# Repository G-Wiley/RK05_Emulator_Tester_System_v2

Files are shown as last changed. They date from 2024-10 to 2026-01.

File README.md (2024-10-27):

# RK05 Emulator/Tester System v2
The RK05 Emulator/Tester System v2

Finished Emulator

<p>The RK05 Emulator/Tester v2 system consists of a main unit, various cables, a terminator, and a power supply. The primary improvement of v2 is that is can emulate and test drives with up to 32 sectors. The DEC RK05 has a maximum capability of 16 sectors but other drives such as some members of the Diablo series 30 family can support up to 32 sectors.

<p>The RK05 Emulator/Tester main unit can be configured to function either as an RK05 disk drive emulator or as an RK05 disk drive tester. The specific function is determined by the software in the Raspberry Pi Pico and the FPGA firmware. Currently, the RK05 disk emulator functions have been rigorously tested. The RK05 disk drive tester functions have been used to test the emulator but full tester functionality is not yet complete.

<p>The Emulator/Tester main unit is designed so it can be connected using the same cables and terminators used with a real RK05 disk drive.

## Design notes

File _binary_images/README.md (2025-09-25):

as of 21-Sep-2025, the latest code is:<br>
<p><b>Emulator:</b><br>
RPi Pico software: RK05_Emulator_RPi_Pico_v2-7.uf2<br>
FPGA firmware: RK05_emulator_FPGA_v2-8.bin</p>
<p><b>Tester:</b><br>
RPi Pico software: RK05_Tester_RPi_Pico_v1-19.uf2<br>
FPGA firmware: RK05_tester_FPGA_v2-5.bin</p>

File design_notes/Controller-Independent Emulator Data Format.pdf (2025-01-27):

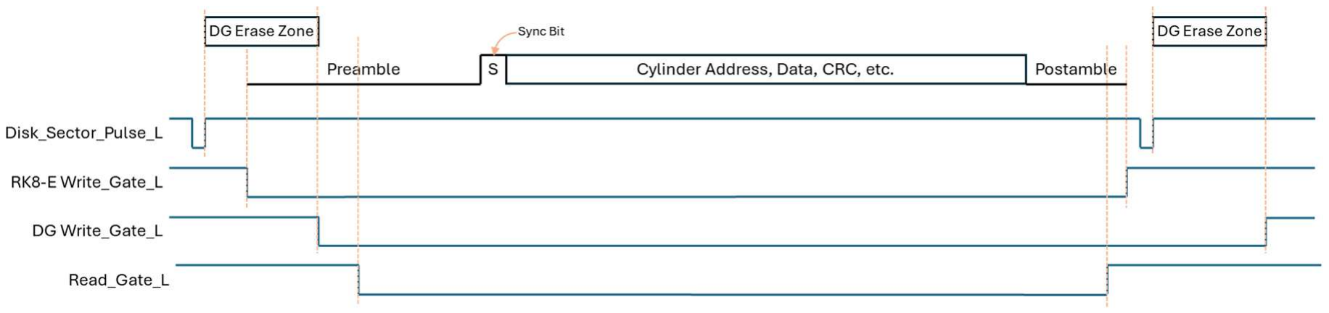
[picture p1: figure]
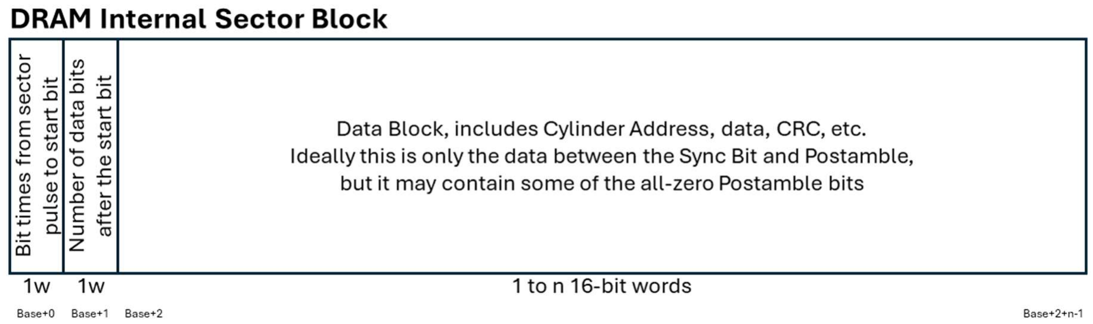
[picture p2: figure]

26-Jan-2025 | Controller-Independent Emulator Data Format v06.docx | page 1

Controller-independent drive emulator data format

Challenges for the previous emulator architecture:
- Having the drive use controller-specific fields made it diicult to accommodate dierent controllers. It was necessary to know details of the timing of the disk bus signals for dierent controllers.
- The timing of some control signals, such as the Write Gate signal on Data General controllers, extend past the sector being written or read which was a complication for the emulator but solvable.
All disk formats in this family of drives and controllers have an all-zero preamble, a single one bit for the sync bit, some number of data bits stored in each sector which includes various fields in addition to data, and an all-zero postamble. Data General controllers keep the Write Gate signal asserted past the sector mark of the next sector.

The controller-independent format has the following data structure for each sector in DRAM and also each sector on the microSD card.

By referencing time from the sector pulse, the emulator will always output the start bit and data block at the correct time. It’s just like bits on the surface of the disk platter.
The fields are as follows:
- Bit times from sector pulse to start bit – address Base+0, the number of bit times from the leading edge of the sector pulse to the start bit that follows the preamble. Since the preamble is an all-zero field, the emulator needs only to count the number of zero bits prior to the start bit and record the count in this field.
- Number of data bits after the start bit – address Base+1, a 16-bit count of the number of bits in the following Data Block. The emulator knows that any bits following the Data Block are all-zero which is either all of the postamble of the last bits of the postamble.

26-Jan-2025 | Controller-Independent Emulator Data Format v06.docx | page 2
- Data block – from addresses Base+2 up to Base+2+n-1, a block of 1 to n words which is the data for a sector on the disk which includes the Cylinder Address, sector data, and CRC. This field could also contain some of the postamble bits when sectors are written by the computer’s disk controller. This is the same data that is presently stored in the DRAM and on the microSD card disk image file.
It is helpful to describe the events that occur during disk read and write operations to be able to implement these functions in FPGA logic.

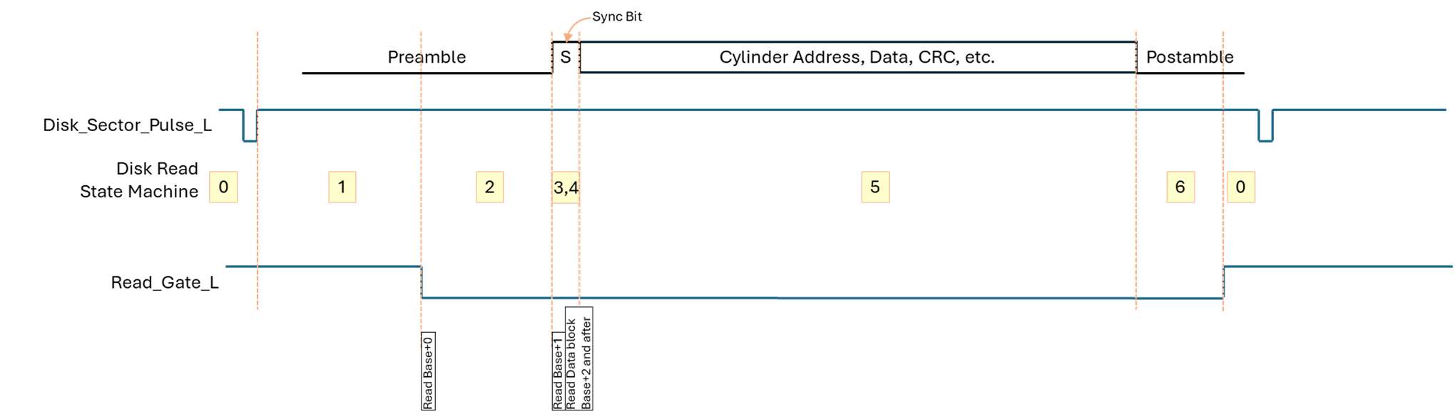
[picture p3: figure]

26-Jan-2025 | Controller-Independent Emulator Data Format v06.docx | page 3

Disk Read Operation:

The following sequence of events occurs when the disk controller reads a sector from the disk:
1. The Emulator generates a periodic sector pulse.
2. At the leading edge of the sector pulse, the Emulator internally loads the fieldbitcount counter to 1, which tracks the number of bit times since the sector pulse. The Emulator begins to increment the fieldbitcount counter once per bit time.
3. If the controller asserts the Read Gate signal, then the Emulator reads the first word of the
DRAM Internal Sector Block from DRAM at address Base+0 which is the value: “Bit times from sector pulse to start bit” and saves it in cthreshold. The fieldbitcount counter continues to increment once per bit time. If there is no read operation (Read Gate doesn’t go active after the sector pulse) and the next sector pulse arrives without having Read Gate asserted, then the fieldbitcount counter is loaded with 1 again at the leading edge of the sector pulse. This happens often.
4. The Emulator detects when the fieldbitcount counter is equal to cthreshold (which was read from Base+0 in step #3) and outputs the Start Bit at the proper clock/data phase time on the serial read data signal, BUS_RD_DATA_L.
5. The Emulator reads the second word of the DRAM Internal Sector Block from DRAM at address Base+1 which is “Number of data bits after the start bit” and saves it in cthreshold. This is to know when to stop the process of reading from DRAM and outputting serial data to the Disk Bus. The fieldbitcount counter is reset to 1 because it now keeps track of how many bits are transferred following the Sync Bit.
6. The Emulator now outputs serialized data read from the Data Block in the DRAM starting at address Base+2. The fieldbitcount counter is incremented once per bit time. If the fieldbitcount counter is equal to cthreshold (which was read from Base + 1 in step #5) then the emulator advances to step #7. If Read Gate goes inactive before all bits of the Data Block have been read from DRAM and serialized, then reset the data read state machine to its starting state.
7. While Read Gate is still in the active state, the Emulator outputs all-zero data to the Disk Bus until Read Gate goes inactive.
8. When Read Gate goes inactive, then reset the data read state machine to its starting state.

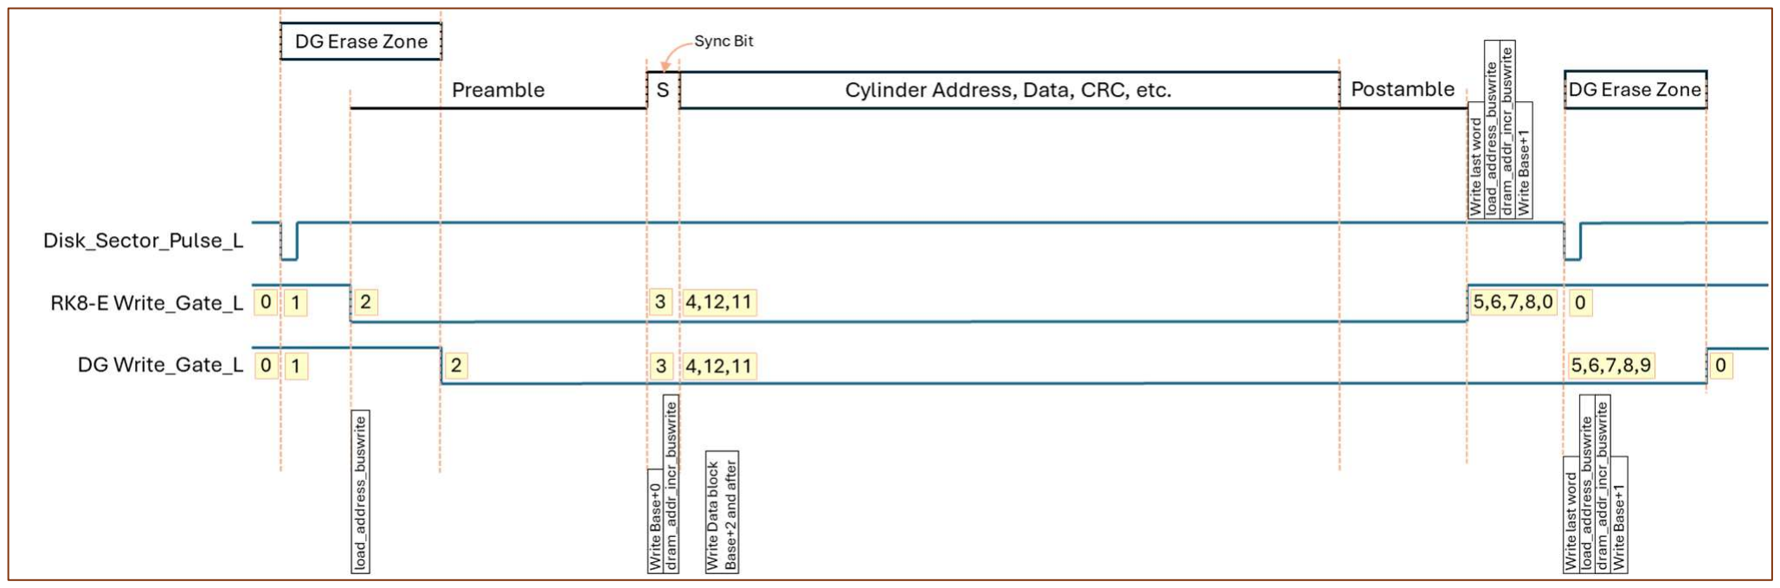
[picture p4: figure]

26-Jan-2025 | Controller-Independent Emulator Data Format v06.docx | page 4

Disk Write Operation:

The following sequence of events occurs when the disk controller writes a sector to the disk:
1. The Emulator generates a periodic sector pulse.
2. At the leading edge of the sector pulse, the Emulator internally loads the fieldbitcount counter to 1, which tracks the number of bit times since the sector pulse. The Emulator begins to increment the fieldbitcount counter once per bit time. Prior to receiving the composite write data-clock signal from the controller, the emulator uses the internal bit time reference signal, clkenbl_read_bit, as a bit time reference.
3. The controller asserts the Write Gate signal.
4. The Emulator decodes serial data on BUS_WT_DATA_CLK_L to recover clock and data.
5. The emulator continues to increment the fieldbitcount counter but now uses the bit enable signal from the decoded BUS_WT_DATA_CLK_L signal as a bit-time reference.
6. When the Sync Bit is detected on the decoded BUS_WT_DATA_CLK_L, the Emulator writes the value in the fieldbitcount counter (which is the bit count since the leading edge of the index pulse) into the first word of the DRAM Internal Sector Block at Base+0. The Emulator sets the fieldbitcount counter to 1 which will now be used to count the number of bits that follow the Sync Bit.

### 7. Emulator decodes serial data on BUS_WT_DATA_CLK_L and writes data words to the DRAM

Internal Sector Block area called Data Block which begins at Base+2.
8. When the Controller de-asserts Write Gate, the Emulator writes the last word or partial word of decoded data to the Data Block and then writes the value in the fieldbitcount counter to the second word of DRAM Internal Sector Block at Base+1 and the internal state machine returns to its starting state. If the Emulator asserts the periodic sector pulse prior to the inactive edge of Write Gate, then the Emulator interprets this event as the end of the sector data and the Emulator writes the last word or partial word of decoded data to the Data Block and then writes the field_bit_count counter to the second word of DRAM Internal Sector Block at Base+1 and the internal state machine goes to a state where no more data is written to DRAM and it waits for Write Gate to go inactive. In the event where Write Gate goes inactive following the assertion of the sector pulse, the internal state machine returns to its starting state when Write Gate goes inactive.

26-Jan-2025 | Controller-Independent Emulator Data Format v06.docx | page 5

The file size on microSD is only two words per sector larger than the previous rk05 file format size, so the load and unload times are about the same.
Essential fields needed in the microSD file header to support the functions described above are:
- Number of Cylinders
- Number of Sectors per Track
- Number of Heads
- Microseconds per sector
- Bit rate
The Bit Rate field is the only controller-specific information needed by the Emulator.
Need a format-specific converter utility for each disk controller type to convert from SIMH to the emulator file format. Maybe this is only needed for PDP-8 and PDP-11. For less-commonly-used formats it is probably suicient to have a utility to create an empty (all-zero data) file with header parameters in the list above, and the lengths of data blocks need to only be approximate given the data rate and number of sectors per track. The emulator disks can be formatted on each machine or users can develop their own SIMH converter for other formats using the source code for the PDP-8 utilities.

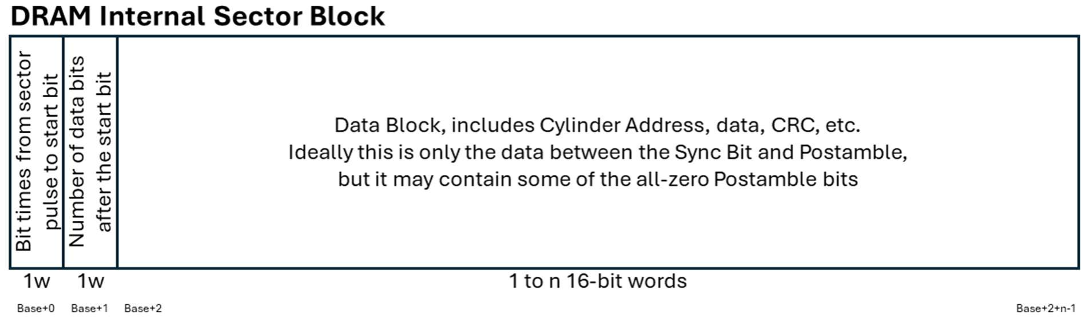
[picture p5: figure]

26-Jan-2025 | Controller-Independent Emulator Data Format v06.docx | page 6

rke File Format Description:

The file on the microSD card has a file extension of “rke”. The emulator RUN/LOAD switch is toggled to the RUN position, the emulator searches for the first rke file that it finds and loads that file into the emulator’s DRAM. The rke file consists of a group of header fields followed by a group of sector data blocks. The sector data blocks can vary in size slightly. This is determined by the original lengths of each block when the microSD file was created and the width of the write gate pulse produced by the disk controller that may have written new data to the disk while it was loaded in the drive.
The file consists of Header + Data Blocks. For 16-sector PDP-8 there are 203 * 16 * 2 = 6496 blocks. For 12-sector PDP-11 there are 203 * 12 * 2 = 4872 blocks.
The rke file header consists of the following fields:
# bytes | Field Description | Hex Oset

10 | char magicNumber[10] = "\x89RK05\r\n\x1A"; | 0x0
4 | char versionNumber[4] = "1.1"; | 0xa
11 | char imageName[11]; | 0xe
200 | char imageDescription[200]; | 0x19
20 | char imageDate[20]; | 0xe1
100 | char controller[100]; | 0xf5
4 | int bitRate; (big endian format) | 0x159
4 | int numberOfCylinders; (big endian format) | 0x15d
4 | int numberOfSectorsPerTrack; (big endian format) | 0x161
4 | int numberOfHeads; (big endian format) | 0x165
4 | int microsecondsPerSector; (big endian format) | 0x169

Following the header there is a group of Sector Blocks beginning at oset 36510 (0x16d). The number of Sector Blocks is:

numberOfCylinders × numberOfSectorsPerTrack × numberOfHeads
The format of each Sector Block is as follows:
- uint16 bit_times_sector_to_start_bit; (little endian format)
- uint16 data_bits_after_start_bit; (little endian format)
- uint16 data_in_sector[data_word_count]

26-Jan-2025 | Controller-Independent Emulator Data Format v06.docx | page 7

The length of the Data Block in 16-bit words, data_word_count, can vary by a small amount in each sector because it is determined by the emulator measuring the length of the write gate pulse from the controller. A file might be initially created by converting a simH file to an rke file, in which case all Sector Blocks will be the same length. Then if that rke file is loaded into the emulator and some sectors are written by the disk controller, the sectors written by the disk controller can have a slightly dierent length than the sectors created by the simH conversion software. The number of 16-bit words in the Data Block is based on the data_bits_after_start_bit field value.
If (data_bits_after_start_bit % 16) == 0 then the Data Block length is (data_bits_after_start_bit / 16). If (data_bits_after_start_bit % 16) != 0 then the Data Block length is (data_bits_after_start_bit / 16) + 1.

## Example of rke file contents

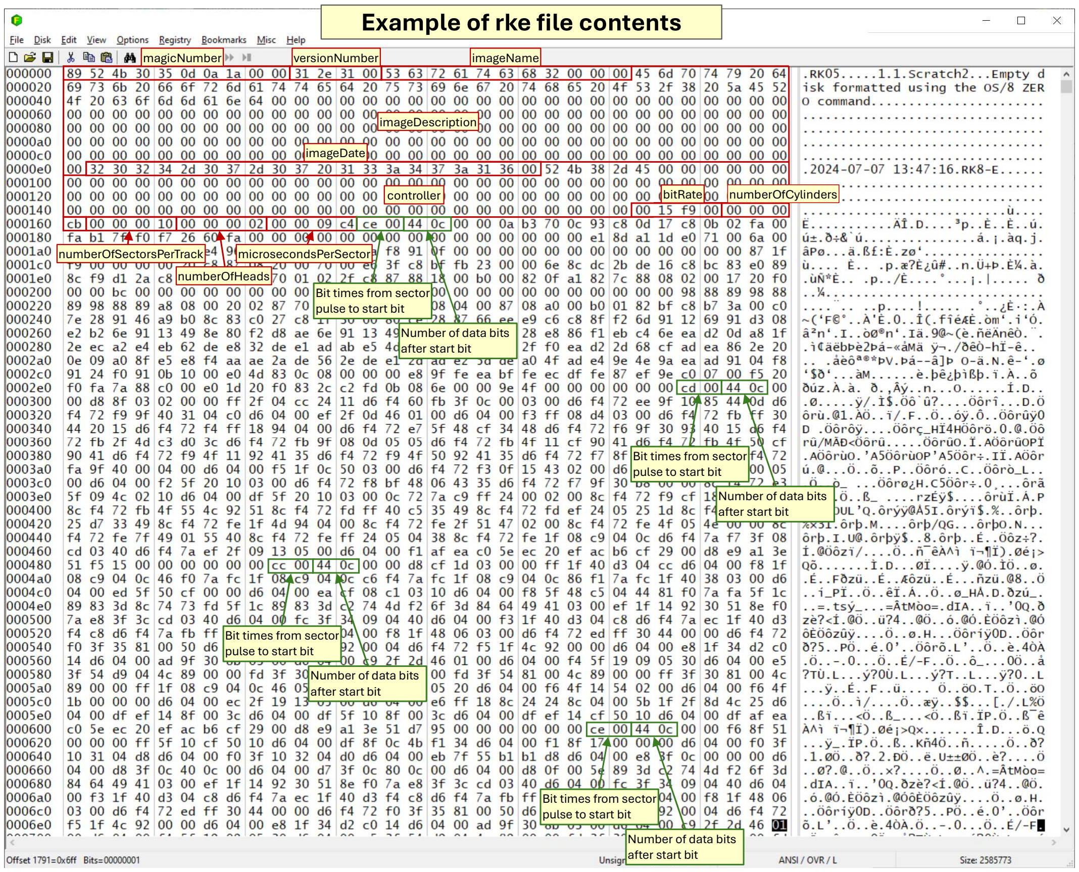
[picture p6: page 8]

26-Jan-2025 | Controller-Independent Emulator Data Format v06.docx | page 8
magicNumber | versionNumber | imageName

imageDescription

imageDate

controller | bitRate | numberOfCylinders

numberOfSectorsPerTrack
numberOfHeads

microsecondsPerSector

Bit times from sector
pulse to start bit
Number of data bits
after start bit

Bit times from sector
pulse to start bit
Number of data bits
after start bit

Bit times from sector
pulse to start bit
Number of data bits
after start bit

Bit times from sector
pulse to start bit
Number of data bits
after start bit

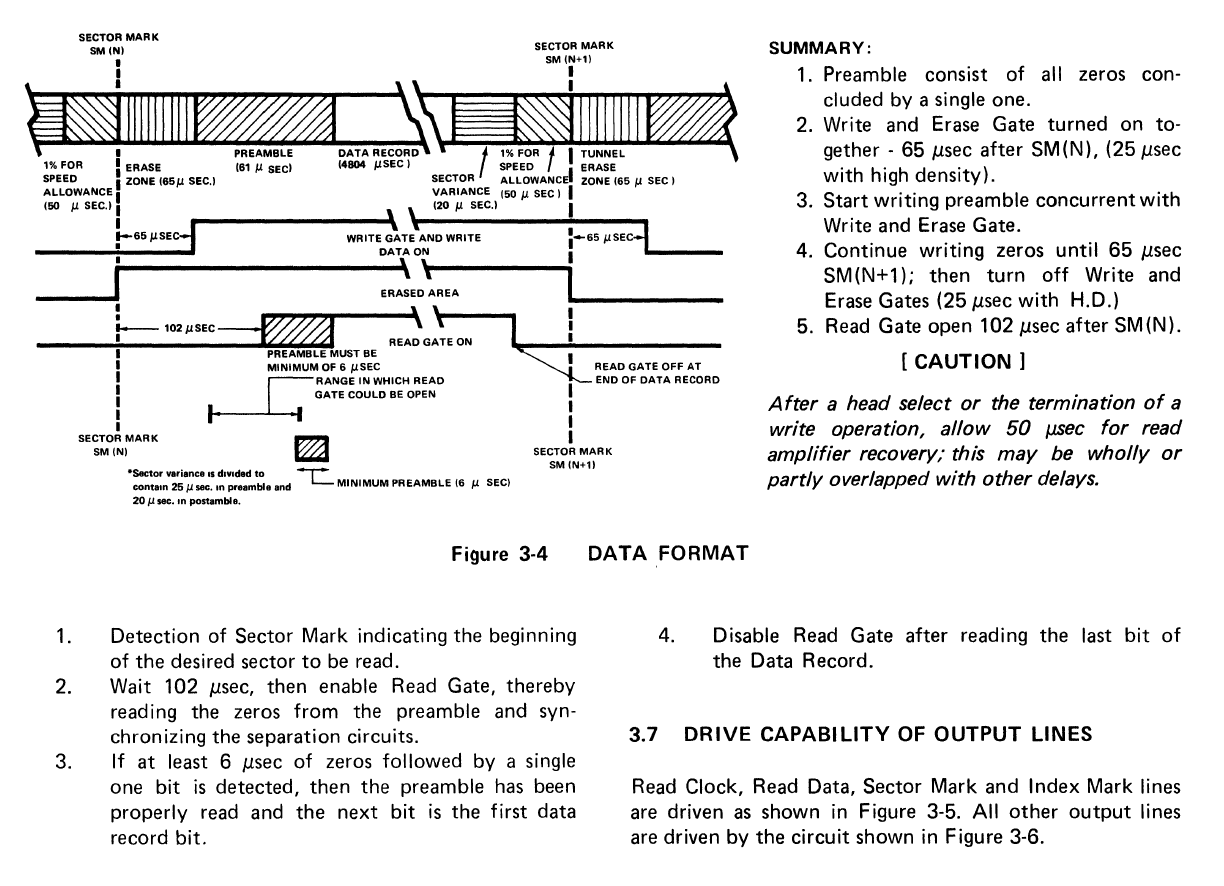
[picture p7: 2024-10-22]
design_notes/Data General diablosync.png

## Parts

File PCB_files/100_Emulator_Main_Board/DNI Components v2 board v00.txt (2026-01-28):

RK05 Emulator v1, parts not added to BOM
Schematic Page 1
J1
J28
J29
R5
R9

Schematic Page 2
JA7
JB7

Schematic Page 3
C7
J3
H1
H2
H3
H4
H5

Schematic Page 4
C35
FPC1
J2
J4
J5
J6
J7
J8
J9
J10
J11
J12
J13
J14
J15
J17
J18
J19
J20
J21
J24
J25
J27
R13
R22
R25
U21
U22

Schematic Page 5
JA8
JB8

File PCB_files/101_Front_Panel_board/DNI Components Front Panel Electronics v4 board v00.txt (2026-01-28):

RK05 Emulator Front Panel Electronics v3, parts not added to BOM
Schematic Page 1
J1
J2
J3
J4
J5
J6
J7 (3-pin header, servo)
J9
J10
J11
J12
J13
J14
J15
J16
J17 (16-pin header, main board)
H1 to H15
R6
R18
SW2
U3 (display module)

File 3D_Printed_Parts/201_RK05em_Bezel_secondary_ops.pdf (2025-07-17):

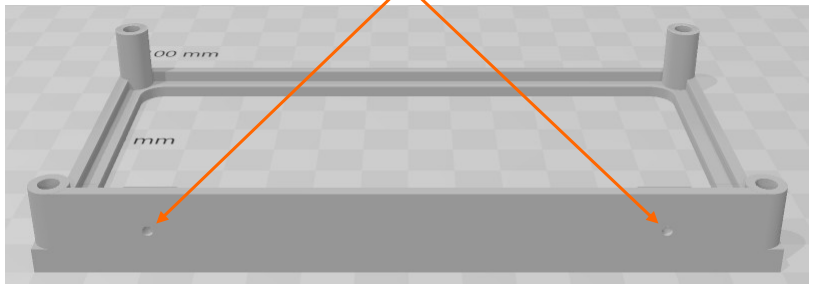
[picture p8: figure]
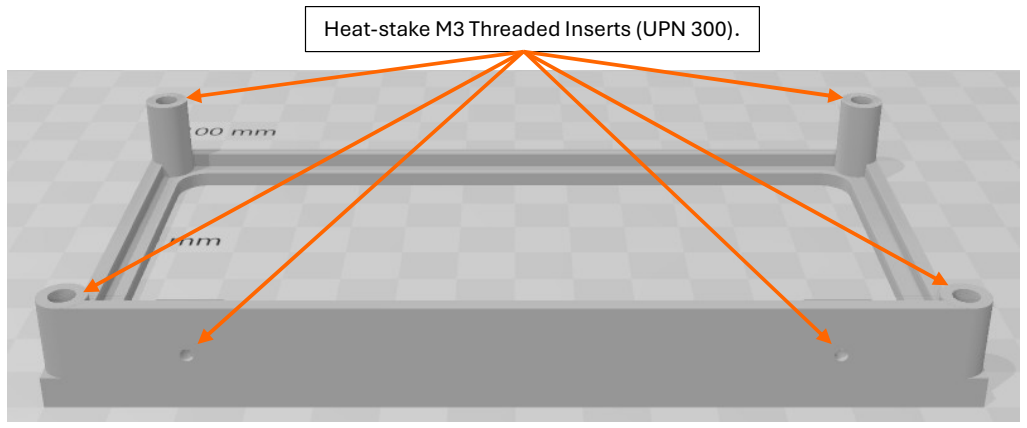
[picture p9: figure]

201_RK05em_Bezel_secondary_ops_v01.docx | page 1

Secondary operations, Bezel

After 3D printing, the Bezel, item 201, needs the following secondary operations to be the fully completed part that can be installed in the final main unit.
- Confirm that the holes in the 3D printed piece in 2 places have a diameter of 4.0 mm. The hole size in the printed part might be slightly inaccurate, depending on the 3D printing process. If necessary, drill these two holes to have a 4.0 mm diameter to be compatible with the M3 insert that will be installed here.
- Heat-stake M3 Threaded Inserts (UPN 300) in holes in the 3D printed piece in 6 places. A soldering iron set to 350° C with a pointed tip or a heat-staking tip can be used to gently press the threaded inserts into place.

Confirm 4.0 mm finished hole size.

Heat-stake M3 Threaded Inserts (UPN 300).

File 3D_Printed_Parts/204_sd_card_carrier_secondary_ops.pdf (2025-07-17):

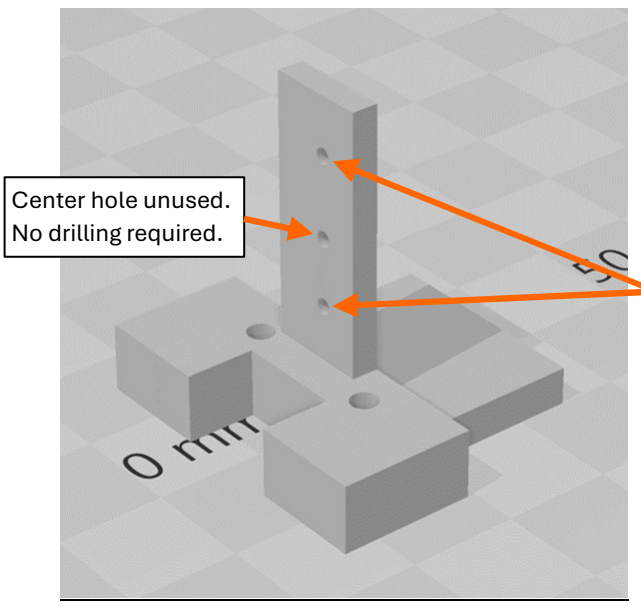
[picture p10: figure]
Center hole unused. No drilling required.
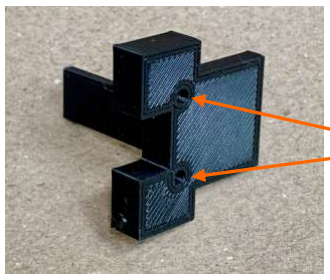
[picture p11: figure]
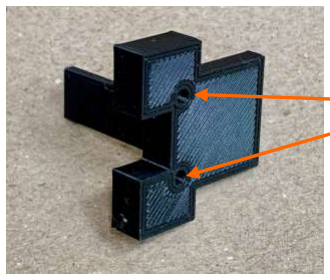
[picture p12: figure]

204_sd_card_carrier_secondary_ops_v02.docx | page 1

Secondary operations, microSD Card Carrier

After 3D printing, the microSD Card Carrier, item 204, needs the following secondary operations to be the fully completed part that can be attached to the front panel assembly.
- Confirm diameter and if necessary, drill holes through to the opposite surface in the 3D printed piece as shown in 2 places to produce a finished hole size of 3.2 mm.
- Confirm diameter and if necessary, drill holes through to the opposite surface in the 3D printed piece as shown in 2 places to produce a finished hole size of 3.0 mm. It is better to drill these holes from the flat surface most visible in the image below.
- Heat-stake M2 threaded inserts (item 311) into the 3.0 mm holes in the 3D printed piece in 2 places. A soldering iron set to 350° C with a pointed tip or a heat-staking tip can be used to gently press the threaded inserts into place.

Drill for 3.0 mm finished hole size.
Drill from this surface.

Heat-stake M2 threaded inserts (item 311) from this surface.

Drill for 3.2 mm finished hole size.

Heat-stake M2 threaded inserts (item 311) from this surface.

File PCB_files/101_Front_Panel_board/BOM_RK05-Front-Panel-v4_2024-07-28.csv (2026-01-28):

ID | Name | Designator | Footprint | Quantity | Manufacturer Part | Manufacturer | Supplier | Supplier Part | Price
1 | 220Ω | R1,R7 | R0603 | 2 | 0603WAF2200T5E | UNI-ROYAL(厚声) | LCSC | C22962 | 0.001
2 | KT-0603R | LED9,LED10 | LED0603-RD | 2 | KT-0603R | KENTO | LCSC | C2286 | 0.005
3 | C440445_CORRECTED_GW | LED6,LED7,LED8,LED5,LED1,LED2,LED3,LED4 | LED-SMD_L3.2-W2.8-R-RD-GW | 8 | TJ-S3528UG6W9TLC3DW-A5 | TOGIALED(统佳) | LCSC | C440445 | 0.033
4 | 10kΩ | R8,R9,R10,R21,R2,R3,R4,R5 | R0603 | 8 | 0603WAF1002T5E | UNI-ROYAL(厚声) | LCSC | C25804 | 0.001
5 | 0Ω | R19,R20 | R0603 | 2 | 0603WAF0000T5E | UNI-ROYAL(厚声) | LCSC | C21189 | 0.001
6 | 100nF | C2,C3,C4 | C0603 | 3 | CC0603KRX7R9BB104 | YAGEO(国巨) | LCSC | C14663 | 0.002
7 | 10uF | C5 | C0603 | 1 | CL10A106KP8NNNC | SAMSUNG(三星) | LCSC | C19702 | 0.005
8 | PCA9557PW,118 | U1 | TSSOP-16_L5.0-W4.4-P0.65-LS6.4-BL | 1 | PCA9557PWR | Texas Instruments | LCSC | C201547 | 0.461
9 | MC74ACT541DTR2G | U2 | TSSOP-20_L6.5-W4.4-P0.65-LS6.4-BL | 1 | MC74ACT541DTR2G | onsemi(安森美) | LCSC | C8112 | 0.553
10 | 120Ω | R11,R12,R13,R14,R15,R16,R17,R26 | R0805 | 8 | 0805W8F1200T5E | UNI-ROYAL(厚声) | LCSC | C17437 | 0.002

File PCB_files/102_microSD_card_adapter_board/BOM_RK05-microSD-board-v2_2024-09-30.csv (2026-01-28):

ID | Name | Designator | Footprint | Quantity | Manufacturer Part | Manufacturer | Supplier | Supplier Part | Price
1 | 100nF | C1 | C0603 | 1 | CC0603KRX7R9BB104 | YAGEO(国巨) | LCSC | C14663 | 0.002
2 | TF-01A | CARD1 | TF-SMD_TF-01A | 1 | TF-01A | 韩国韩荣 | LCSC | C91145 | 0.159
3 | 10kΩ | R1 | R0603 | 1 | 0603WAF1002T5E | UNI-ROYAL(厚声) | LCSC | C25804 | 0.001

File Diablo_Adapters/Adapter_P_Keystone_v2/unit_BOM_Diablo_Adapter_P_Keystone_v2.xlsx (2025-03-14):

Qty | UPN | Ref. Des. | Description | Part Ver. | Manufacturer | Manufacturer's part number | Supplier | Link | cost ea | ext cost
1 | 109 |  | PCB, Diablo Adapter, Pin, Keystone | v2 |  |  | JLCPCB | Surface Finish: LeadFree HASL | $0.990 | $0.990
4 | 379 | J1A, J1B, J2A, J2B | Header, 40-pin, right-angle, with ejectors |  | Amphenol ICC (FCI) | 86130402114345E1LF | Digikey | https://www.digikey.com/en/products/detail/amphenol-cs-fci/86130402114345E1LF/5201674 | $1.460 | $5.841
1 | 385 | J3 | CONN Header 2POS 0.1 GOLD PCB |  | Sullins Electronics | PPPC021LFBN-RC | Digikey | https://www.digikey.com/en/products/detail/sullins-connector-solutions/PPPC021LFBN-RC/810174 | $0.291 | $0.291
1 | 380 | R1 | Resistor, 10, 1/4W 5% |  |  | choose 10 ohms | AliExpress | https://www.aliexpress.us/item/3256805535456035.html | $0.037 | $0.037
1 | 208 |  | Diablo Connector Shim | v1 |  | 208 v0 | JLCPCB |  | $1.202 | $1.202
2 | 374 |  | Sheet Metal Screw, #2, 1/4 inch, pan head |  |  |  | Amazon | https://www.amazon.com/dp/B098QL1MCM | $0.075 | $0.151
1 | 388 |  | Thumb Screw, 6-32 x 12mm, Royal Blue |  |  |  | AliExpress | https://www.aliexpress.us/item/3256803687287578.html | $1.313 | $1.313
42 | 389 |  | CONN PC PIN CIRC 0.060 DIA GOLD |  | Mill-Max Manufacturing Inc. | 4357-0-00-15-00-00-03-0 | Digikey | https://www.digikey.com/en/products/detail/mill-max-manufacturing-corp/4357-0-00-15-00-00-03-0/5820224 | $0.388 | $16.281
0 |  |  | CONN PC PIN CIRC 0.063DIA GOLD |  | Keystone Electronics | 1362-2 | Digikey | https://www.digikey.com/en/products/detail/keystone-electronics/1362-2/2746382 | $0.922 | $0.000
 |  |  |  |  | Keystone is an alternate for Mill-Max 4357-0-00-15-00-00-03-0
 |  |  | TOTAL |  |  |  |  |  |  | $26.11

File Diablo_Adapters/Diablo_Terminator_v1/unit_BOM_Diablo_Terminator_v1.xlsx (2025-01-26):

Qty | UPN | Ref. Des. | Description | Part Ver. | Manufacturer | Manufacturer's part number | Supplier | Link | cost ea | ext cost
1 | 112 |  | PCB, Diablo Terminator, assembled | v1 |  |  | JLCPCB | Surface Finish: LeadFree HASL | $3.509 | $3.51
2 | 386 | J1, J2 | CONN HDR 40POS 0.1 GOLD PCB |  | Sullins Electronics | SFH11-PBPC-D20-ST-BK | Digikey | https://www.digikey.com/en/products/detail/sullins-connector-solutions/SFH11-PBPC-D20-ST-BK/1990093 | $1.780 | $3.56
1 | 387 | J3 | CONN HEADER VERT 2POS 2.54MM |  | Samtec Inc. | TSW-102-09-G-S | Digikey | https://www.digikey.com/en/products/detail/samtec-inc/TSW-102-09-G-S/2685867 | $0.340 | $0.34
 |  |  | TOTAL |  |  |  |  |  | $5.63

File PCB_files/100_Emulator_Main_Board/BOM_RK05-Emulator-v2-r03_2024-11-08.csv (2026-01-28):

ID | Name | Designator | Footprint | Quantity | Manufacturer Part | Manufacturer | Supplier | Supplier Part | Price
1 | 100kΩ | R34,R29 | R0603 | 2 | 0603WAF1003T5E | UNI-ROYAL(厚声) | LCSC | C25803 | 0.001
2 | 470Ω | R33 | R0603 | 1 | 0603WAF4700T5E | UNI-ROYAL(厚声) | LCSC | C23179 | 0.001
3 | SN75451BD-Logic | U23,U20,U11,U4,U5,U6,U7,U8,U9,U10,U12 | SOIC-8_L5.0-W4.0-P1.27-LS6.0-BL | 11 | SN75451 | Texas Instruments | LCSC | C7068 | 0.429
4 | 1kΩ | R32,R31 | R0603 | 2 | 0603WAF1001T5E | UNI-ROYAL(厚声) | LCSC | C21190 | 0.001
5 | 74LVC244AD,118 | U13,U14,U15 | SOIC-20_L13.0-W7.6-P1.27-LS10.3-BL | 3 | 74LVC244AD,118 | Nexperia | LCSC | C548504 | 0.312
6 | 10kΩ | R30,R20,R17,R8,R16,R14,R15,R1,R2,R3,R4,R6,R27,R11,R12 | R0603 | 15 | 0603WAF1002T5E | UNI-ROYAL(厚声) | LCSC | C25804 | 0.001
7 | TPS3808G01DBVR | U19 | SOT-23-6_L2.9-W1.6-P0.95-LS2.8-BR | 1 | TPS3808G01DBVR | TI(德州仪器) | LCSC | C19653 | 0.376
8 | 0Ω | R10 | R0603 | 1 | 0603WAF0000T5E | UNI-ROYAL(厚声) | LCSC | C21189 | 0.001
9 | SKRPASE010 | SW1 | KEY-SMD_4P-L4.2-W3.2-P2.20-LS4.6 | 1 | SKRPASE010 | ALPSALPINE(阿尔卑斯阿尔派) | LCSC | C470427 | 0.096
10 | 22kΩ | R28,R26 | R0603 | 2 | 0603WAF2202T5E | UNI-ROYAL(厚声) | LCSC | C31850 | 0.001
11 | 100Ω | R7,R23,R24 | R0603 | 3 | 0603WAF1000T5E | UNI-ROYAL(厚声) | LCSC | C22775 | 0.001
12 | FC-2012HRK-620D | LED1 | LED0805-R-RD | 1 | NCD0805R1 | 国星光电 | LCSC | C84256 | 0.012
13 | 150Ω | R21 | R0603 | 1 | 0603WAF1500T5E | UNI-ROYAL(厚声) | LCSC | C22808 | 0.001
14 | 4.7kΩ | R19 | R0603 | 1 | 0603WAF4701T5E | UNI-ROYAL(厚声) | LCSC | C23162 | 0.001
15 | MBR120LSF | D2 | SOD-123_L2.8-W1.8-LS3.7-RD | 1 | MBR120LSF | SHIKUES(时科) | LCSC | C130880 | 0.035
16 | 240Ω | R18 | R0603 | 1 | 0603WAF2400T5E | UNI-ROYAL(厚声) | LCSC | C23350 | 0.001
17 | RK05_Emulator_iCE40HX1K | U1 | TQFP-144_L20.0-W20.0-P0.50-LS22.0-BL-EP7.2 | 1 | iCE40HX1K-TQ144 | Lattice Semiconductor | Digi-Key | iCE40HX1K-TQ144
18 | 40MHz | X1 | OSC-SMD_4P-L5.0-W3.2-BL_SG-8101CB | 1 | SG-8101CB 40.000000MHz TBGSA | EPSON(爱普生) | LCSC | C390561 | 1.277
19 | 100nF | C47,C34,C1,C2,C3,C4,C5,C6,C9,C10,C11,C12,C13,C14,C15,C16,C17,C18,C19,C20,C21,C22,C28,C29,C30,C31,C32,C33,C36,C37,C38,C39,C40,C41,C42,C43,C44,C45,C46 | C0603 | 39 | CC0603KRX7R9BB104 | YAGEO(国巨) | LCSC | C14663 | 0.002
20 | W9825G6KH-6 | U2 | TSOP-54_L22.2-W10.2-P0.80-LS11.8-BL | 1 | W9825G6KH-6 | WINBOND(华邦) | LCSC | C62246 | 1.328
21 | 10uF | C23,C24,C25,C26 | C0603 | 4 | CL10A106KP8NNNC | SAMSUNG(三星) | LCSC | C19702 | 0.005
22 | B5819W_C8598 | D1 | SOD-123_L2.7-W1.6-LS3.7-RD-1 | 1 | B5819W SL | CJ(江苏长电/长晶) | LCSC | C8598 | 0.025
23 | N25Q032A13ESC40F | U3 | SOIC-8_L5.0-W4.0-P1.27-LS6.0-BL | 1 | N25Q032A13ESC40F | Micron | Digi-Key | 1450-N25Q032A13ESC40FCT-ND
24 | LD1117DT33CTR | U16 | TO-252-2_L6.5-W6.1-P4.58-LS10.0-TL | 1 | LD1117DT33CTR | ST(意法半导体) | LCSC | C36395 | 0.196
25 | LD1117DT12CTR | U17 | TO-252-3_L6.5-W5.8-P4.58-BL | 1 | LD1117DT12CTR | ST(意法半导体) | LCSC | C81188 | 0.191

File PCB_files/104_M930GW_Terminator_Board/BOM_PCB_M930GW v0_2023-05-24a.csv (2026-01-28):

ID | Name | Designator | Footprint | Quantity | Manufacturer Part | Manufacturer | Supplier | Supplier Part | Price
1 | 470nF | C8,C9,C4,C5,C6,C7 | C0603 | 6 | CL10B474KA8NNNC | SAMSUNG(三星) | LCSC | C1623 | 0.007
2 | 47uF | C1A | C1210 | 1 | LMK325BJ476MM-T | TAIYO YUDEN(太诱) | LCSC | C92824 | 0.214
3 | 1nF | C2,C3 | C0603 | 2 | CL10B102KB8NNNC | SAMSUNG(三星) | LCSC | C1588 | 0.003
4 | 180Ω | R1,R3,R5,R7,R9,R11,R13,R15,R17,R19,R21,R23,R25,R27,R29,R31,R33,R35,R37,R39,R41,R43,R45,R47,R49,R51,R53,R55,R58,R60,R62,R64,R66,R70,R72,R74,R76,R78,R80,R82,R84,R86,R88,R90,R92,R94,R96,R98,R100,R102,R104,R106,R108,R110 | R1206 | 54 | 1206W4F1800T5E | UNI-ROYAL(Uniroyal Elec) | LCSC | C17924 | 0.003
5 | 390Ω | R2,R4,R6,R8,R10,R12,R14,R16,R18,R20,R22,R24,R26,R28,R30,R32,R34,R40,R42,R44,R46,R48,R50,R52,R54,R57,R59,R61,R63,R65,R67,R68,R69,R71,R73,R77,R79,R83,R85,R87,R89,R91,R93,R95,R97,R99,R101,R103,R105,R107,R109 | R0603 | 51 | 0603WAF3830T5E | UNI-ROYAL(厚声) | LCSC | C23151 | 0.001

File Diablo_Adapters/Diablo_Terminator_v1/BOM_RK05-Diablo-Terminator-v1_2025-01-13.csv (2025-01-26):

ID | Name | Designator | Footprint | Quantity | Manufacturer Part | Manufacturer | Supplier | Supplier Part | Price
1 | 383Ω | R38,R2,R4,R6,R8,R14,R16,R18,R20,R22,R24,R26,R30,R32,R34,R40,R42,R44,R48,R52,R54,R57,R59,R61,R63,R65,R67,R68,R73,R83,R85,R87,R89,R91,R93,R103,R105,R107,R109 | R0603 | 39 | 0603WAF3830T5E | UNI-ROYAL(厚声) | LCSC | C23151 | 0.001
2 | 470nF | C8,C9,C4,C5,C6,C7 | C0603 | 6 | CL10B474KA8NNNC | SAMSUNG(三星) | LCSC | C1623 | 0.006
3 | 47uF | C1A | C1210 | 1 | LMK325BJ476MM-T | TAIYO YUDEN(太诱) | LCSC | C92824 | 0.192
4 | 1nF | C2,C3 | C0603 | 2 | CL10B102KB8NNNC | SAMSUNG(三星) | LCSC | C1588 | 0.003
5 | 180Ω | R1,R3,R5,R7,R13,R15,R17,R19,R21,R23,R25,R29,R31,R33,R35,R37,R39,R41,R43,R47,R51,R53,R58,R60,R62,R64,R66,R74,R84,R86,R88,R90,R92,R94,R104,R106,R108,R110 | R1206 | 38 | 1206W4F1800T5E | UNI-ROYAL(厚声) | LCSC | C17924 | 0.003

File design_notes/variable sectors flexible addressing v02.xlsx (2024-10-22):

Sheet: v2_board
0.04 |  |  | 1600000 b/s
 |  |  |  |  |  |  |  |  |  |  | #sectors - 1
# sectors | #sectors - 1 | #sector bits | #bits / sector | #words / sector needed | sector data #addr bits needed | total# addr bits | sector data #addr bits allocated | #words / sector allocated | margin (words) | margin (µsec) | s4 | s3 | s2 | s1 | s0 | DRAM Address
2 | 1 | 1 | 32000 | 2000 | 11 | 12 | 12 | 4096 | 2096 | 20960 | 0 | 0 | 0 | 0 | 1 | CYL[7:0] | HEAD | SECT[0] | AC[11] | AC[10] | AC[9] | AC[8] | AC[7] | AC[6] | AC[5] | AC[4] | AC[3] | AC[2] | AC[1] | AC[0]
3 | 2 | 2 | 21333.33333 | 1333.333333 | 11 | 13 | 11 | 2048 | 714 | 7140 | 0 | 0 | 0 | 1 | 0 | CYL[7:0] | HEAD | SECT[1] | SECT[0] | AC[10] | AC[9] | AC[8] | AC[7] | AC[6] | AC[5] | AC[4] | AC[3] | AC[2] | AC[1] | AC[0]
4 | 3 | 2 | 16000 | 1000 | 10 | 12 | 11 | 2048 | 1048 | 10480 | 0 | 0 | 0 | 1 | 1 | CYL[7:0] | HEAD | SECT[1] | SECT[0] | AC[10] | AC[9] | AC[8] | AC[7] | AC[6] | AC[5] | AC[4] | AC[3] | AC[2] | AC[1] | AC[0]
5 | 4 | 3 | 12800 | 800 | 10 | 13 | 10 | 1024 | 224 | 2240 | 0 | 0 | 1 | 0 | 0 | CYL[7:0] | HEAD | SECT[2] | SECT[1] | SECT[0] | AC[9] | AC[8] | AC[7] | AC[6] | AC[5] | AC[4] | AC[3] | AC[2] | AC[1] | AC[0]
6 | 5 | 3 | 10666.66667 | 666.6666667 | 10 | 13 | 10 | 1024 | 357 | 3570 | 0 | 0 | 1 | 0 | 1 | CYL[7:0] | HEAD | SECT[2] | SECT[1] | SECT[0] | AC[9] | AC[8] | AC[7] | AC[6] | AC[5] | AC[4] | AC[3] | AC[2] | AC[1] | AC[0]
7 | 6 | 3 | 9142.857143 | 571.4285714 | 10 | 13 | 10 | 1024 | 452 | 4520 | 0 | 0 | 1 | 1 | 0 | CYL[7:0] | HEAD | SECT[2] | SECT[1] | SECT[0] | AC[9] | AC[8] | AC[7] | AC[6] | AC[5] | AC[4] | AC[3] | AC[2] | AC[1] | AC[0]
8 | 7 | 3 | 8000 | 500 | 9 | 12 | 10 | 1024 | 524 | 5240 | 0 | 0 | 1 | 1 | 1 | CYL[7:0] | HEAD | SECT[2] | SECT[1] | SECT[0] | AC[9] | AC[8] | AC[7] | AC[6] | AC[5] | AC[4] | AC[3] | AC[2] | AC[1] | AC[0]
9 | 8 | 4 | 7111.111111 | 444.4444444 | 9 | 13 | 9 | 512 | 67 | 670 | 0 | 1 | 0 | 0 | 0 | CYL[7:0] | HEAD | SECT[3] | SECT[2] | SECT[1] | SECT[0] | AC[8] | AC[7] | AC[6] | AC[5] | AC[4] | AC[3] | AC[2] | AC[1] | AC[0]
10 | 9 | 4 | 6400 | 400 | 9 | 13 | 9 | 512 | 112 | 1120 | 0 | 1 | 0 | 0 | 1 | CYL[7:0] | HEAD | SECT[3] | SECT[2] | SECT[1] | SECT[0] | AC[8] | AC[7] | AC[6] | AC[5] | AC[4] | AC[3] | AC[2] | AC[1] | AC[0]
11 | 10 | 4 | 5818.181818 | 363.6363636 | 9 | 13 | 9 | 512 | 148 | 1480 | 0 | 1 | 0 | 1 | 0 | CYL[7:0] | HEAD | SECT[3] | SECT[2] | SECT[1] | SECT[0] | AC[8] | AC[7] | AC[6] | AC[5] | AC[4] | AC[3] | AC[2] | AC[1] | AC[0]
12 | 11 | 4 | 5333.333333 | 333.3333333 | 9 | 13 | 9 | 512 | 178 | 1780 | 0 | 1 | 0 | 1 | 1 | CYL[7:0] | HEAD | SECT[3] | SECT[2] | SECT[1] | SECT[0] | AC[8] | AC[7] | AC[6] | AC[5] | AC[4] | AC[3] | AC[2] | AC[1] | AC[0]
13 | 12 | 4 | 4923.076923 | 307.6923077 | 9 | 13 | 9 | 512 | 204 | 2040 | 0 | 1 | 1 | 0 | 0 | CYL[7:0] | HEAD | SECT[3] | SECT[2] | SECT[1] | SECT[0] | AC[8] | AC[7] | AC[6] | AC[5] | AC[4] | AC[3] | AC[2] | AC[1] | AC[0]
14 | 13 | 4 | 4571.428571 | 285.7142857 | 9 | 13 | 9 | 512 | 226 | 2260 | 0 | 1 | 1 | 0 | 1 | CYL[7:0] | HEAD | SECT[3] | SECT[2] | SECT[1] | SECT[0] | AC[8] | AC[7] | AC[6] | AC[5] | AC[4] | AC[3] | AC[2] | AC[1] | AC[0]
15 | 14 | 4 | 4266.666667 | 266.6666667 | 9 | 13 | 9 | 512 | 245 | 2450 | 0 | 1 | 1 | 1 | 0 | CYL[7:0] | HEAD | SECT[3] | SECT[2] | SECT[1] | SECT[0] | AC[8] | AC[7] | AC[6] | AC[5] | AC[4] | AC[3] | AC[2] | AC[1] | AC[0]
16 | 15 | 4 | 4000 | 250 | 8 | 12 | 9 | 512 | 262 | 2620 | 0 | 1 | 1 | 1 | 1 | CYL[7:0] | HEAD | SECT[3] | SECT[2] | SECT[1] | SECT[0] | AC[8] | AC[7] | AC[6] | AC[5] | AC[4] | AC[3] | AC[2] | AC[1] | AC[0]
17 | 16 | 5 | 3764.705882 | 235.2941176 | 8 | 13 | 8 | 256 | 20 | 200 | 1 | 0 | 0 | 0 | 0 | CYL[7:0] | HEAD | SECT[4] | SECT[3] | SECT[2] | SECT[1] | SECT[0] | AC[7] | AC[6] | AC[5] | AC[4] | AC[3] | AC[2] | AC[1] | AC[0]
18 | 17 | 5 | 3555.555556 | 222.2222222 | 8 | 13 | 8 | 256 | 33 | 330 | 1 | 0 | 0 | 0 | 1 | CYL[7:0] | HEAD | SECT[4] | SECT[3] | SECT[2] | SECT[1] | SECT[0] | AC[7] | AC[6] | AC[5] | AC[4] | AC[3] | AC[2] | AC[1] | AC[0]
19 | 18 | 5 | 3368.421053 | 210.5263158 | 8 | 13 | 8 | 256 | 45 | 450 | 1 | 0 | 0 | 1 | 0 | CYL[7:0] | HEAD | SECT[4] | SECT[3] | SECT[2] | SECT[1] | SECT[0] | AC[7] | AC[6] | AC[5] | AC[4] | AC[3] | AC[2] | AC[1] | AC[0]
20 | 19 | 5 | 3200 | 200 | 8 | 13 | 8 | 256 | 56 | 560 | 1 | 0 | 0 | 1 | 1 | CYL[7:0] | HEAD | SECT[4] | SECT[3] | SECT[2] | SECT[1] | SECT[0] | AC[7] | AC[6] | AC[5] | AC[4] | AC[3] | AC[2] | AC[1] | AC[0]
21 | 20 | 5 | 3047.619048 | 190.4761905 | 8 | 13 | 8 | 256 | 65 | 650 | 1 | 0 | 1 | 0 | 0 | CYL[7:0] | HEAD | SECT[4] | SECT[3] | SECT[2] | SECT[1] | SECT[0] | AC[7] | AC[6] | AC[5] | AC[4] | AC[3] | AC[2] | AC[1] | AC[0]
22 | 21 | 5 | 2909.090909 | 181.8181818 | 8 | 13 | 8 | 256 | 74 | 740 | 1 | 0 | 1 | 0 | 1 | CYL[7:0] | HEAD | SECT[4] | SECT[3] | SECT[2] | SECT[1] | SECT[0] | AC[7] | AC[6] | AC[5] | AC[4] | AC[3] | AC[2] | AC[1] | AC[0]
23 | 22 | 5 | 2782.608696 | 173.9130435 | 8 | 13 | 8 | 256 | 82 | 820 | 1 | 0 | 1 | 1 | 0 | CYL[7:0] | HEAD | SECT[4] | SECT[3] | SECT[2] | SECT[1] | SECT[0] | AC[7] | AC[6] | AC[5] | AC[4] | AC[3] | AC[2] | AC[1] | AC[0]
24 | 23 | 5 | 2666.666667 | 166.6666667 | 8 | 13 | 8 | 256 | 89 | 890 | 1 | 0 | 1 | 1 | 1 | CYL[7:0] | HEAD | SECT[4] | SECT[3] | SECT[2] | SECT[1] | SECT[0] | AC[7] | AC[6] | AC[5] | AC[4] | AC[3] | AC[2] | AC[1] | AC[0]
25 | 24 | 5 | 2560 | 160 | 8 | 13 | 8 | 256 | 96 | 960 | 1 | 1 | 0 | 0 | 0 | CYL[7:0] | HEAD | SECT[4] | SECT[3] | SECT[2] | SECT[1] | SECT[0] | AC[7] | AC[6] | AC[5] | AC[4] | AC[3] | AC[2] | AC[1] | AC[0]
26 | 25 | 5 | 2461.538462 | 153.8461538 | 8 | 13 | 8 | 256 | 102 | 1020 | 1 | 1 | 0 | 0 | 1 | CYL[7:0] | HEAD | SECT[4] | SECT[3] | SECT[2] | SECT[1] | SECT[0] | AC[7] | AC[6] | AC[5] | AC[4] | AC[3] | AC[2] | AC[1] | AC[0]
27 | 26 | 5 | 2370.37037 | 148.1481481 | 8 | 13 | 8 | 256 | 107 | 1070 | 1 | 1 | 0 | 1 | 0 | CYL[7:0] | HEAD | SECT[4] | SECT[3] | SECT[2] | SECT[1] | SECT[0] | AC[7] | AC[6] | AC[5] | AC[4] | AC[3] | AC[2] | AC[1] | AC[0]
28 | 27 | 5 | 2285.714286 | 142.8571429 | 8 | 13 | 8 | 256 | 113 | 1130 | 1 | 1 | 0 | 1 | 1 | CYL[7:0] | HEAD | SECT[4] | SECT[3] | SECT[2] | SECT[1] | SECT[0] | AC[7] | AC[6] | AC[5] | AC[4] | AC[3] | AC[2] | AC[1] | AC[0]
29 | 28 | 5 | 2206.896552 | 137.9310345 | 8 | 13 | 8 | 256 | 118 | 1180 | 1 | 1 | 1 | 0 | 0 | CYL[7:0] | HEAD | SECT[4] | SECT[3] | SECT[2] | SECT[1] | SECT[0] | AC[7] | AC[6] | AC[5] | AC[4] | AC[3] | AC[2] | AC[1] | AC[0]
30 | 29 | 5 | 2133.333333 | 133.3333333 | 8 | 13 | 8 | 256 | 122 | 1220 | 1 | 1 | 1 | 0 | 1 | CYL[7:0] | HEAD | SECT[4] | SECT[3] | SECT[2] | SECT[1] | SECT[0] | AC[7] | AC[6] | AC[5] | AC[4] | AC[3] | AC[2] | AC[1] | AC[0]
31 | 30 | 5 | 2064.516129 | 129.0322581 | 8 | 13 | 8 | 256 | 126 | 1260 | 1 | 1 | 1 | 1 | 0 | CYL[7:0] | HEAD | SECT[4] | SECT[3] | SECT[2] | SECT[1] | SECT[0] | AC[7] | AC[6] | AC[5] | AC[4] | AC[3] | AC[2] | AC[1] | AC[0]

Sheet: v1_board
0.04 |  |  | 1600000 b/s
 |  |  |  |  |  |  |  |  |  |  | #sectors - 1
# sectors | #sectors - 1 | #sector bits | #bits / sector | #words / sector needed | sector data #addr bits needed | total# addr bits | sector data #addr bits allocated | #words / sector allocated | margin (words) | margin (µsec) | s3 | s2 | s1 | s0 | DRAM Address
2 | 1 | 1 | 32000 | 2000 | 11 | 12 | 12 | 4096 | 2096 | 20960 | 0 | 0 | 0 | 1 | CYL[7:0] | HEAD | SECT[0] | AC[11] | AC[10] | AC[9] | AC[8] | AC[7] | AC[6] | AC[5] | AC[4] | AC[3] | AC[2] | AC[1] | AC[0]
3 | 2 | 2 | 21333.33333 | 1333.333333 | 11 | 13 | 11 | 2048 | 714 | 7140 | 0 | 0 | 1 | 0 | CYL[7:0] | HEAD | SECT[1] | SECT[0] | AC[10] | AC[9] | AC[8] | AC[7] | AC[6] | AC[5] | AC[4] | AC[3] | AC[2] | AC[1] | AC[0]
4 | 3 | 2 | 16000 | 1000 | 10 | 12 | 11 | 2048 | 1048 | 10480 | 0 | 0 | 1 | 1 | CYL[7:0] | HEAD | SECT[1] | SECT[0] | AC[10] | AC[9] | AC[8] | AC[7] | AC[6] | AC[5] | AC[4] | AC[3] | AC[2] | AC[1] | AC[0]
5 | 4 | 3 | 12800 | 800 | 10 | 13 | 10 | 1024 | 224 | 2240 | 0 | 1 | 0 | 0 | CYL[7:0] | HEAD | SECT[2] | SECT[1] | SECT[0] | AC[9] | AC[8] | AC[7] | AC[6] | AC[5] | AC[4] | AC[3] | AC[2] | AC[1] | AC[0]
6 | 5 | 3 | 10666.66667 | 666.6666667 | 10 | 13 | 10 | 1024 | 357 | 3570 | 0 | 1 | 0 | 1 | CYL[7:0] | HEAD | SECT[2] | SECT[1] | SECT[0] | AC[9] | AC[8] | AC[7] | AC[6] | AC[5] | AC[4] | AC[3] | AC[2] | AC[1] | AC[0]
7 | 6 | 3 | 9142.857143 | 571.4285714 | 10 | 13 | 10 | 1024 | 452 | 4520 | 0 | 1 | 1 | 0 | CYL[7:0] | HEAD | SECT[2] | SECT[1] | SECT[0] | AC[9] | AC[8] | AC[7] | AC[6] | AC[5] | AC[4] | AC[3] | AC[2] | AC[1] | AC[0]
8 | 7 | 3 | 8000 | 500 | 9 | 12 | 10 | 1024 | 524 | 5240 | 0 | 1 | 1 | 1 | CYL[7:0] | HEAD | SECT[2] | SECT[1] | SECT[0] | AC[9] | AC[8] | AC[7] | AC[6] | AC[5] | AC[4] | AC[3] | AC[2] | AC[1] | AC[0]
9 | 8 | 4 | 7111.111111 | 444.4444444 | 9 | 13 | 9 | 512 | 67 | 670 | 1 | 0 | 0 | 0 | CYL[7:0] | HEAD | SECT[3] | SECT[2] | SECT[1] | SECT[0] | AC[8] | AC[7] | AC[6] | AC[5] | AC[4] | AC[3] | AC[2] | AC[1] | AC[0]
10 | 9 | 4 | 6400 | 400 | 9 | 13 | 9 | 512 | 112 | 1120 | 1 | 0 | 0 | 1 | CYL[7:0] | HEAD | SECT[3] | SECT[2] | SECT[1] | SECT[0] | AC[8] | AC[7] | AC[6] | AC[5] | AC[4] | AC[3] | AC[2] | AC[1] | AC[0]
11 | 10 | 4 | 5818.181818 | 363.6363636 | 9 | 13 | 9 | 512 | 148 | 1480 | 1 | 0 | 1 | 0 | CYL[7:0] | HEAD | SECT[3] | SECT[2] | SECT[1] | SECT[0] | AC[8] | AC[7] | AC[6] | AC[5] | AC[4] | AC[3] | AC[2] | AC[1] | AC[0]
12 | 11 | 4 | 5333.333333 | 333.3333333 | 9 | 13 | 9 | 512 | 178 | 1780 | 1 | 0 | 1 | 1 | CYL[7:0] | HEAD | SECT[3] | SECT[2] | SECT[1] | SECT[0] | AC[8] | AC[7] | AC[6] | AC[5] | AC[4] | AC[3] | AC[2] | AC[1] | AC[0]
13 | 12 | 4 | 4923.076923 | 307.6923077 | 9 | 13 | 9 | 512 | 204 | 2040 | 1 | 1 | 0 | 0 | CYL[7:0] | HEAD | SECT[3] | SECT[2] | SECT[1] | SECT[0] | AC[8] | AC[7] | AC[6] | AC[5] | AC[4] | AC[3] | AC[2] | AC[1] | AC[0]
14 | 13 | 4 | 4571.428571 | 285.7142857 | 9 | 13 | 9 | 512 | 226 | 2260 | 1 | 1 | 0 | 1 | CYL[7:0] | HEAD | SECT[3] | SECT[2] | SECT[1] | SECT[0] | AC[8] | AC[7] | AC[6] | AC[5] | AC[4] | AC[3] | AC[2] | AC[1] | AC[0]
15 | 14 | 4 | 4266.666667 | 266.6666667 | 9 | 13 | 9 | 512 | 245 | 2450 | 1 | 1 | 1 | 0 | CYL[7:0] | HEAD | SECT[3] | SECT[2] | SECT[1] | SECT[0] | AC[8] | AC[7] | AC[6] | AC[5] | AC[4] | AC[3] | AC[2] | AC[1] | AC[0]
16 | 15 | 4 | 4000 | 250 | 8 | 12 | 9 | 512 | 262 | 2620 | 1 | 1 | 1 | 1 | CYL[7:0] | HEAD | SECT[3] | SECT[2] | SECT[1] | SECT[0] | AC[8] | AC[7] | AC[6] | AC[5] | AC[4] | AC[3] | AC[2] | AC[1] | AC[0]

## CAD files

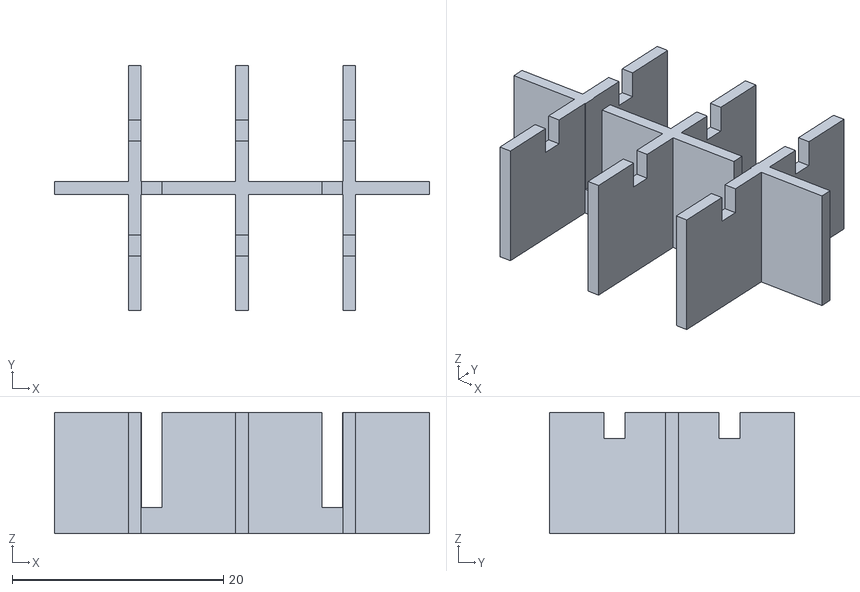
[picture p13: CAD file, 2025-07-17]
3D_Printed_Parts/207_Light_Shield1_v03.stl
35.5 x 23.2 x 11.5

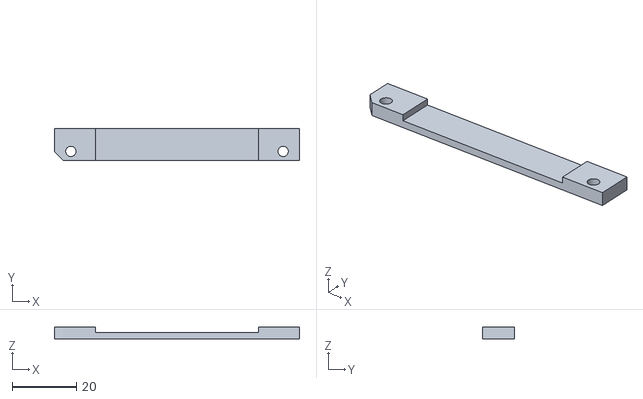
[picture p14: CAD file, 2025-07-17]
3D_Printed_Parts/205_M993_Cable_Clamp_v04.stl
76.2 x 10.0 x 3.73

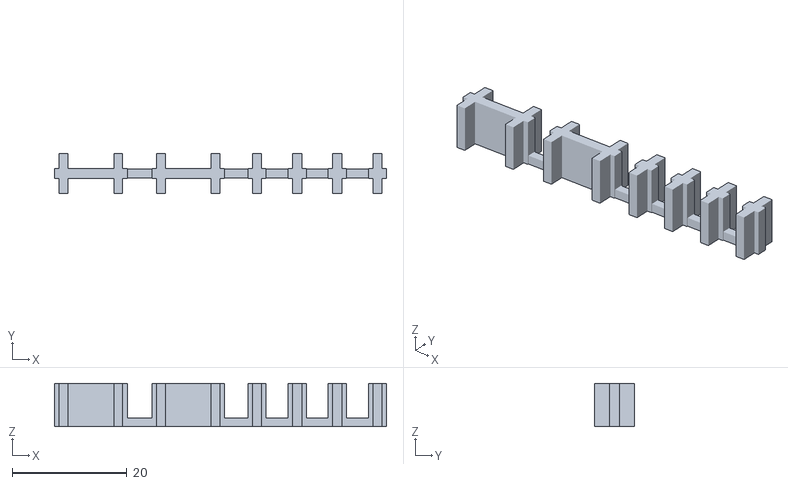
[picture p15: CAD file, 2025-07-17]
3D_Printed_Parts/202_RK05em_connector_filler_v05.stl
57.9 x 7.01 x 7.51

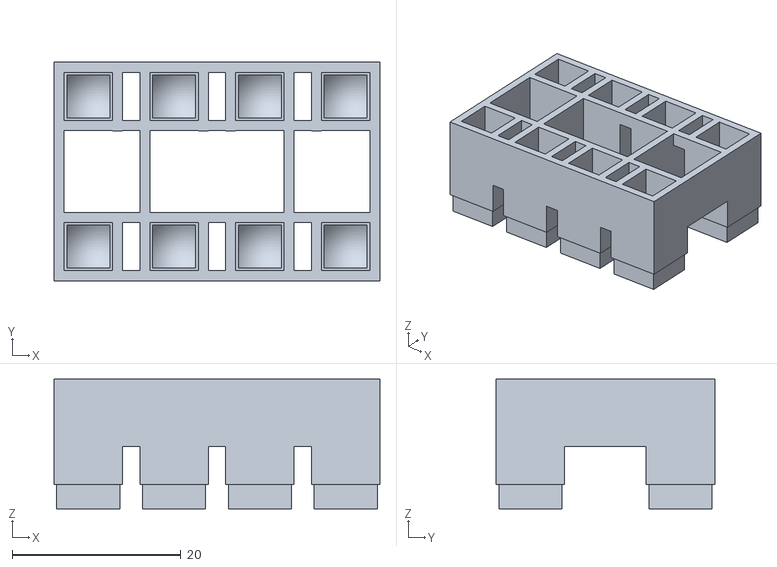
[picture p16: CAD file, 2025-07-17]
3D_Printed_Parts/200_RK05_Lamp_Lens_v04.stl
38.6 x 25.9 x 15.4

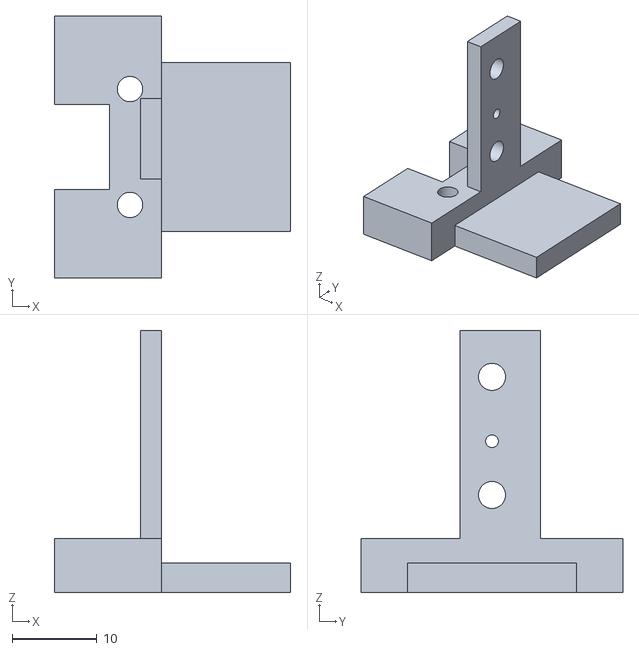
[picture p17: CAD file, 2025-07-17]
3D_Printed_Parts/204_sd_card_carrier_v21.stl
27.9 x 31.0 x 31.0

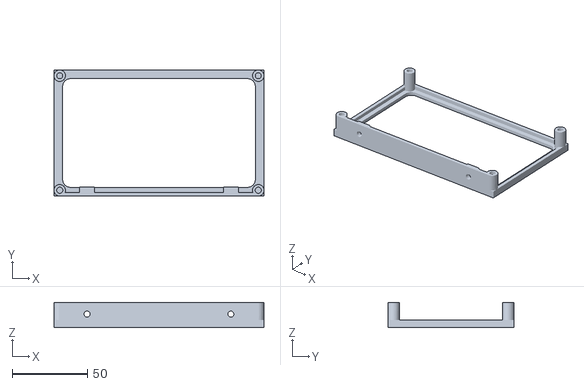
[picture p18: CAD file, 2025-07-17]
3D_Printed_Parts/201_RK05em_Bezel_v06.stl
139.7 x 83.8 x 16.8

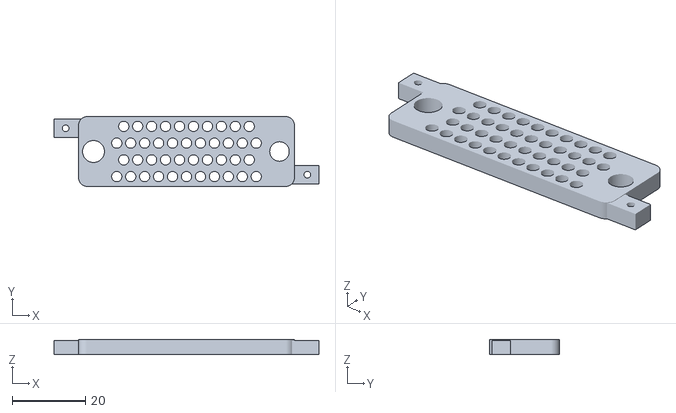
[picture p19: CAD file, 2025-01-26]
3D_Printed_Parts/Diablo Connector Shell v01.stl
72.4 x 19.1 x 3.96

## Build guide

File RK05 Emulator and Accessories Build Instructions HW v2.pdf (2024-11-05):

5-Nov-2024 | RK05 Emulator/Tester v2 & Accessories Assembly Instructions (document v04) | page 1

## RK05 Emulator/Tester v2 & Accessories Assembly Instructions

The RK05 Emulator/Tester system consists of a main unit, various cables, a terminator, and a power supply. These sub-components are available in kit form or parts can be purchased directly from the sources in the bill of materials. Assembly instructions for each of the sub-components are provided below.
The assembly process consists of soldering components to circuit boards and the use of M2 and M3 fasteners to hold parts together. Less common procedures such as heat staking of threaded inserts, and modification of edge connectors have been performed in advance so the kit can be assembled using commonly available tools. Some assemblies describe crimping of quick-connect terminals, but these terminals can be optionally soldered is a crimping tool is not available.
The RK05 Emulator/Tester v2 & Accessories sub-components are:
- E1, RK05 Emulator/Tester v2 main unit – This main unit emulates an RK05 drive. It can also be configured as an RK05 tester by loading dierent software and FPGA code.
- A1, RK05-to-RK8-E Cable, 1 meter length – Cable to connect an RK05 Emulator/Tester main unit to a DEC RK8-E or Plessey PM-DC/8 disk controller for a PDP-8 Omnibus. This board is intended to work with a DEC RK-11D/E but has not yet been tested. The A1 kit consists of an A4 plus two 1 meter 40-pin flat cables.
- A2, RK05-to-RK05 Cable, 1 meter length – Cable to connect two RK05 Emulators or RK05 drives or RK05 Emulator to RK05 drive on an RK05 bus. The A2 kit consists of two A4 boards plus two 1 meter 40-pin flat cables.
- A3, RK05-to-RK05 Cable, Side-to-Side – Similar to A2 but without cable clamps on the adapter board and short cables that route to the side.
- A4, RK05 Adapter Board without Flat Cables – An adapter board that plugs into the RK05 bus and has two 40-pin flat cable connectors. Pinout compatible with RK8-E and RK-11D/E.
- A5, RK05-to-Tester Cable, 1 meter length – Cable to connect an RK05 Tester to an RK05 or RK05 Emulator. Consists of one A6, one A4, and two 1 meter 40-pin flat cables.
- A6, RK05 Tester Adapter Board without flat cables – When the main unit is configured as a Tester then the RK05 bus edge connector signals are not compatible with the RK05 bus. This is because the inputs and outputs of the main unit are now reversed. The Tester Adapter Board converts the flipped input-output signals to standard RK05 flat cable signal pinout.
- A7 and A7N, RK05 Emulator Power Supply – A Power Supply that powers up to three RK05 Emulators from a 25 watt USB Type C input. A 25 watt USB Type C power adapter is included with the A7. The power cable built in the main unit kit plugs directly into this board. A7N does not include the USB Type C power adapter, for countries with primary power dierent than in the US.
- A9, RK05 Emulator Rack Mount Tray for 3 Emulators – A rack mount tray that holds three RK05 Emulators and a power supply. This can be purchased directly from amazon.com.
- T1, M930GW Terminator Board – RK05 bus terminator. Electrically the same as the DEC M930.

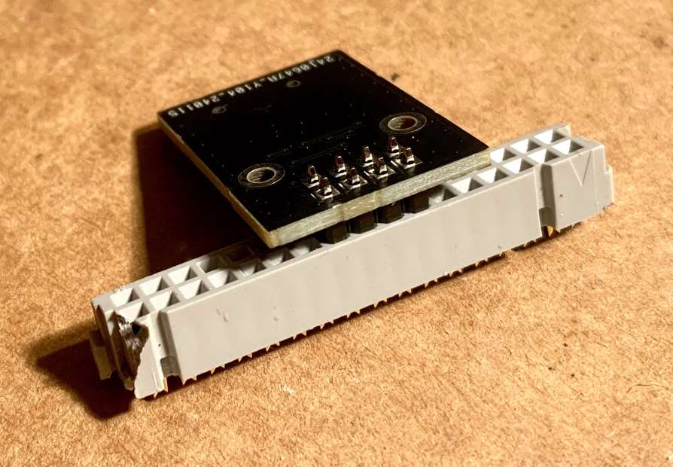
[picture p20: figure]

5-Nov-2024 | RK05 Emulator/Tester v2 & Accessories Assembly Instructions (document v04) | page 2

Assembly tips:
It’s recommended to use Lead-Free solder: 99% tin, 0.3% silver, 0.7% copper (99/0.3/0.7 Sn/Ag/Cu) when building the boards. PCB fabrication and surface mount assembly of all modules in the emulator was performed using a lead-free process. A 0.6mm diameter 99/0.3/0.7 lead-free solder with flux works well for attaching the through-hole parts.
When soldering the headers it is easy for heat from soldering to melt the plastic body of the header and the result is that the pins are crooked. Also, the end pins in the small headers can be slightly loose due to cutting the small headers from a larger header strip. To mitigate this issue, use an old flat cable connector as a holder for the header being soldered. First, rest the header on a hard surface and press the flat cable connector onto the header. This will align the pins in case any are loose. Next, insert the header into the PCB and solder the pins while the flat cable connector is still attached.

The assembly instructions have been written so that the shortest parts are installed first and the tallest are installed last.
Kit Parts Programming & Testing:
The FPGA on the main board has been programmed with the latest released code at the time of shipment. The main board has been tested using a bed-of-nails tester. In this test, all RK05 disk bus input/output signals have been verified using a walking-zeroes test and all other input/output signals such as those to the microSD card, display, front panel switches and LEDs have been similarly checked using an automated test.
The front panel board has been tested using a test clip with pogo pins that contact the 2x8 header pads and by running an automated test to verify all signals related to the display, front panel switches and LEDs.
The Raspberry Pi Pico has been programmed with the latest released code at the time of shipment, and plugged into a known-good system to confirm that the code boots properly.
Refer to the testing description document for details regarding the production testing.
The Raspberry Pi Pico and FPGA can be upgraded in the field. The Raspberry Pi Pico can be loaded with the latest “UF2” file by removing it from the main board and plugging it into a computer and copying the UF2 file to the Pico which appears as a flash drive. The FPGA can be reprogrammed with the latest “bin”

5-Nov-2024 | RK05 Emulator/Tester v2 & Accessories Assembly Instructions (document v04) | page 3

file using a Lattice programming adapter (about $30) that is commonly available on eBay. Refer to the programming document for details regarding the reprogramming of the Pico and FPGA.

5-Nov-2024 | RK05 Emulator/Tester v2 & Accessories Assembly Instructions (document v04) | page 4

## E1 RK05 Emulator/Tester

RK05 Emulator/Tester kit of parts:

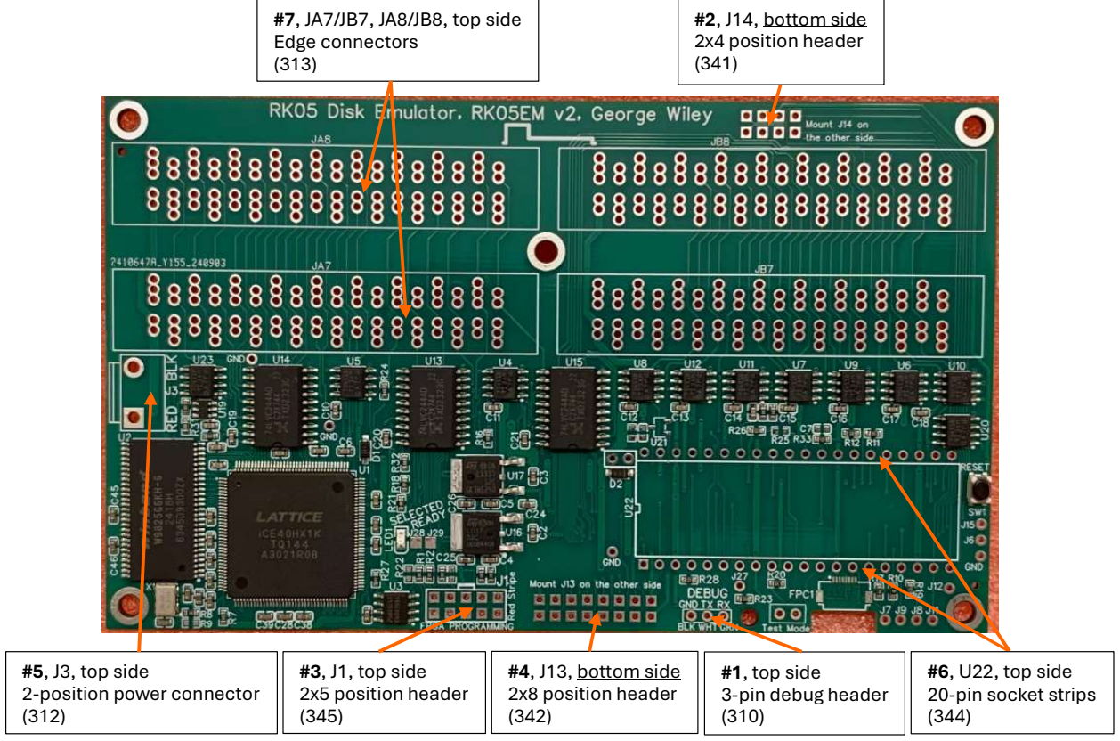
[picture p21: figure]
#2, J14, bottom side 2x4 position header (341); #7, JA7/JB7, JA8/JB8, top side Edge connectors (313); #1, top side 3-pin debug header (310); #4, J13, bottom side 2x8 position header (342); #3, J1, top side 2x5 position header (345); #5, J3, top side 2-position power connector (312); #6, U22, top side 20-pin socket strips (344)

5-Nov-2024 | RK05 Emulator/Tester v2 & Accessories Assembly Instructions (document v04) | page 5

Main Board electrical assembly
In the following instructions, “top side” refers to the side of the board with the surface mount components and “bottom side” refers to the side without the surface mount components. Install the following parts on the Emulator Main Board (100) from bag “G, Main Board”. The parts referenced in the following instructions are from bag “E, Main Board Electrical” and bag “M, Edge Connectors”.
1. Install and solder the 3-pin debug header (310) on the top side.
2. Install and solder J14, a 2 x 4 position header (341) on the bottom side. Silkscreen text describes proper installation.
3. Install and solder J1, a 2 x 5 position header (345) on the top side.
4. Install and solder J13, a 2 x 8 position header (342) on the bottom side. Silkscreen text describes proper installation.
5. Install and solder J3, a 2-pin power connector (312) on the top side. Take care to notice the silkscreen text and graphics that describe the proper polarity.
6. Install and solder two 20-pin single row socket strips (344) in the two rows of pins of U22 on the top side. It’s helpful to plug the Raspberry Pi Pico into the socket strips while soldering them to keep proper alignment between the two strips. First, solder the four corner pins of the two socket strips and then turn the board over to check the alignment. If necessary, correct the alignment and then turn back and solder the remaining pins of the socket strips.
7. Install and solder two edge connectors (313), one in location JA7/JB7 and the other in location JA8/JB8, both on the top side. There is no polarity so the connectors can be installed in either direction. For consistency, the blue lettering can face the lower edge so it’s not visible when the unit is assembled.

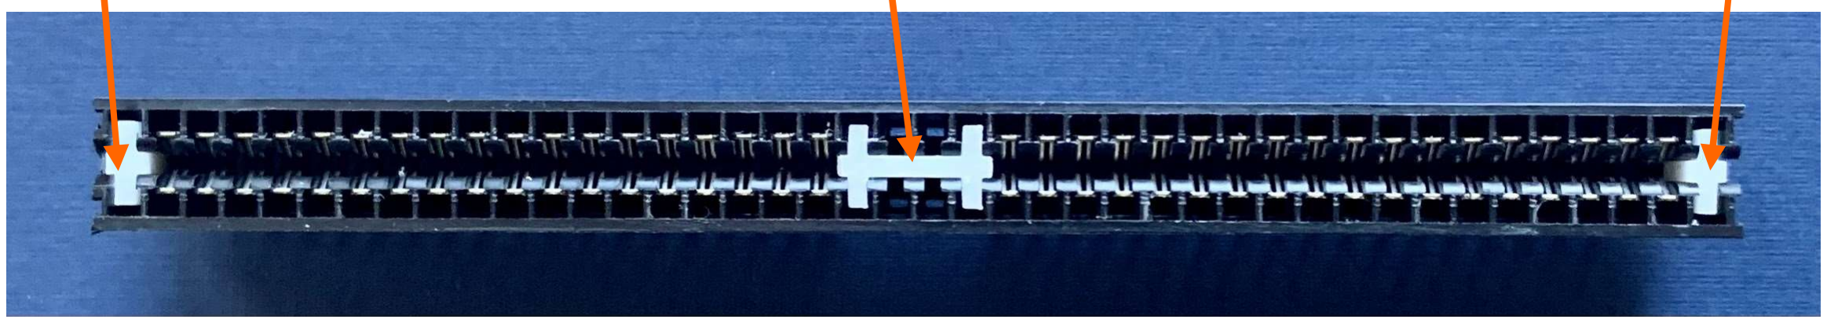
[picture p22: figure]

5-Nov-2024 | RK05 Emulator/Tester v2 & Accessories Assembly Instructions (document v04) | page 6
8. Detach the connector fillers/shims (202) from the connecting ribs and insert them into the edge connectors.
Keep track of which ends of the shims were attached to the connecting rib in the rack of shims. When the shims are separated (probably with diagonal cutters) the widths of the ends that were cut will be less accurate compared to the top ends of the shims. Insert these cut ends into the bottom of the connectors so the more-precise shim width is at the top where the boards are inserted.
The single-width shims should be inserted into the single slots without contact pins on the outside of the connectors. The quad-width shims should be inserted into the 4-pin-wide slots without contact pins in the center of the connectors.

#8, fillers/shims

Single-width
(202)

#8, fillers/shims

Single-width
(202)

#8, fillers/shims

Quad-width
(202)

5-Nov-2024 | RK05 Emulator/Tester v2 & Accessories Assembly Instructions (document v04) | page 7
9. Build the Power Cable by stripping about 2.5mm (0.1 inch) of insulation from the ends of the 12-inch (30.5 cm) AWG 22 red-black zip cord (346). Tin the bare ends of the wire for best results.
10. Detach four socket pins (339) from the small metal band. Use needle-nose pliers to crimp the wide-short fins around the bare wire exposed in the previous step.
11. It is recommended to use a small amount of solder to solder the crimped joints and wire. Be careful not to use too much solder so that solder does not run into the contact area of the socket pins.
12. Use needle-nose pliers to crimp the narrow-long fins around the insulation of the wire.
13. Find the two 3-position 3.96 EP Plugs (312) in bag E, and observe how they fit onto the power connector, J3, on the main board. The locking lever on the plug latches to the tall plastic tab on the power connector. This step is to know the orientation of the plug when it is installed. Now notice that the silkscreen on the Main Board has legends “RED” and “BLK” beside J3. This tells which wire color to insert into which position of the plug. The red wire connects to +5V and the black wire connects to ground. Details of the proper polarity are shown in the photo below.
14. Insert the socket pins that we previously attached to the ends of the red/black zip cord into the EP Plugs (312), being careful to insert the red and black wires into the proper slots of the EP Plugs. The proper slots for the red and black wires were determined in the previous step. The center position of the EP Plug will not have a socket pin inserted. The socket pins fit only one way into the EP Plugs. The small locking fins on the socket pins align with the small openings in the side of the

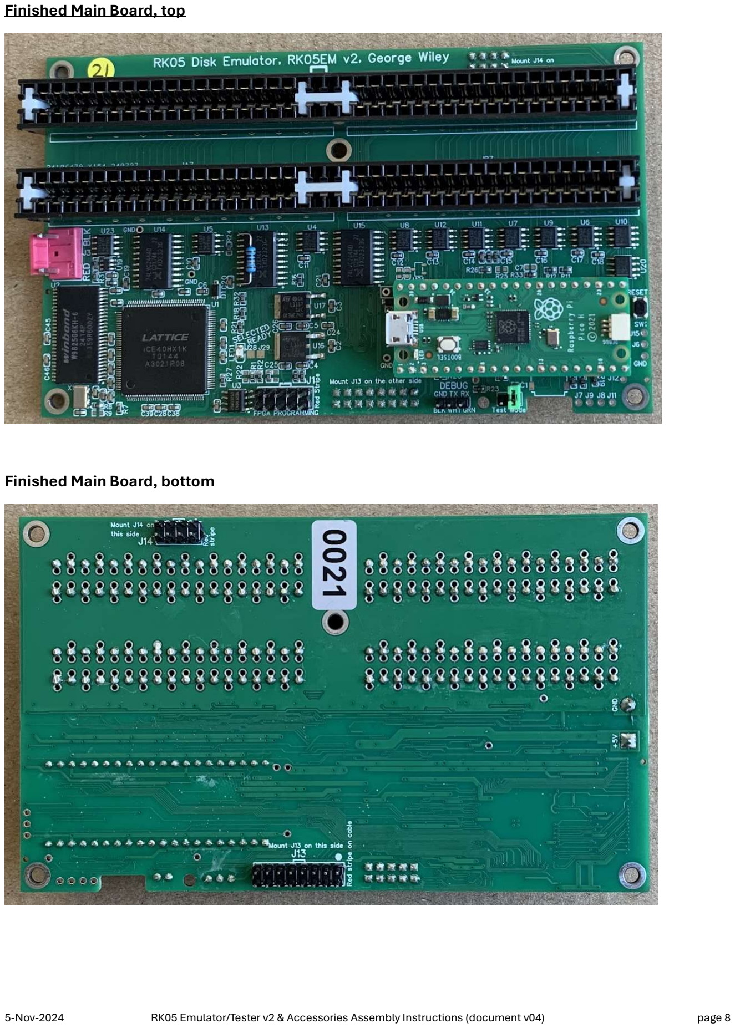
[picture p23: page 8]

5-Nov-2024 | RK05 Emulator/Tester v2 & Accessories Assembly Instructions (document v04) | page 8

Finished Main Board, top

Finished Main Board, bottom

5-Nov-2024 | RK05 Emulator/Tester v2 & Accessories Assembly Instructions (document v04) | page 9

microSD Board assembly
The parts referenced in the following instructions are from bag “K, microSD Board”.
1. Install and solder J14, a 2 x 4 position header (341) on the top side of the microSD card adapter board (102).
2. Use two M2 x 4mm screws (321) and two M2 split lock washers (322), both in bag K2, to attach the assembled microSD board from step 1 to the microSD card carrier bracket (204).

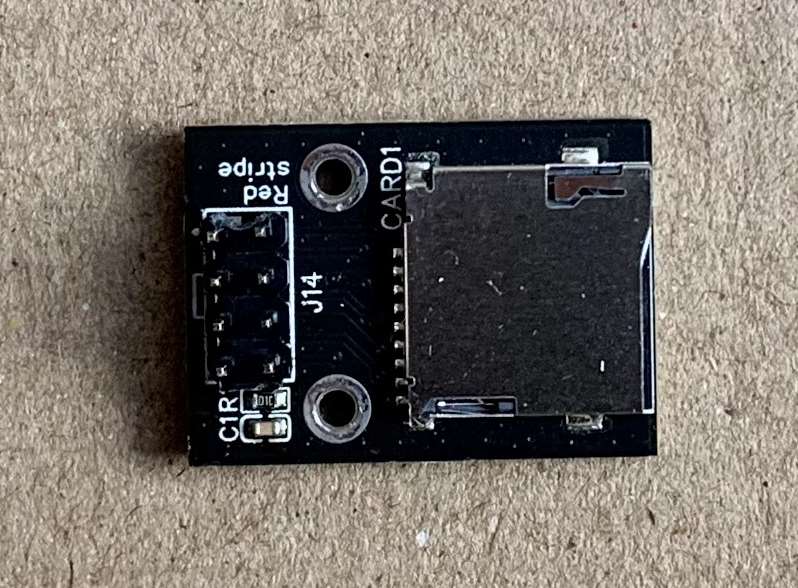
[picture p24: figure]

Finished microSD Card Adapter | Finished microSD carrier bracket

#2, top side

M2 x 4mm + M2 split lock washer (321 & 322)

#1, J14, top side

2x4 position header
(341)

5-Nov-2024 | RK05 Emulator/Tester v2 & Accessories Assembly Instructions (document v04) | page 10

Front Panel Board electrical assembly
Install the following parts on the Front Panel Board (101) from bag “J, Front Panel”. The parts referenced in the following instructions are from bag “H, Front Panel Board Electrical”.
1. Install and solder J17, a 2 x 8 position header (342), on the bottom side. Silkscreen text describes proper installation.
2. Install and solder SW2, the 4-position right-angle dipswitch (317) on the top side. The switch levers should face the edge of the board as indicated in the silkscreen, so they are easily accessible after the unit is assembled.
3. Install the socket of the plug/socket set (376) at location J5 on the bottom side. The silkscreen has text to indicate on which side of the board to mount J5. Note that the connector has two notches. Orient the connector so that the notches correspond with the similar features in the silkscreen, as shown.
4. Locate the small white connector from the plug/socket set with 4 wires (red, white, green, and black) protruding from it. Cut the red and black wires (the two wires on the outside) to a length of 2 inches measured from the back of the white plug to the end of the cut wire. Cut the white and green wires (the two wires on the inside) to a length of 2.25 inches measured from the back of the white plug to the end of the cut wire.
5. Strip about 0.25 inches (6.4 mm) of insulation from the cut end of each of the wires extending from the plug of the plug/socket set (376).
6. Crimp a Quick Spade Wire Connector (375) onto the ends of the wire that were stripped in the previous step. If a crimping tool isn’t available, then it’s acceptable to carefully solder the wires inside the barrel of the Quick Spade Wire Connectors.

#3, J5, bottom side

Socket of plug/socket set
(376)

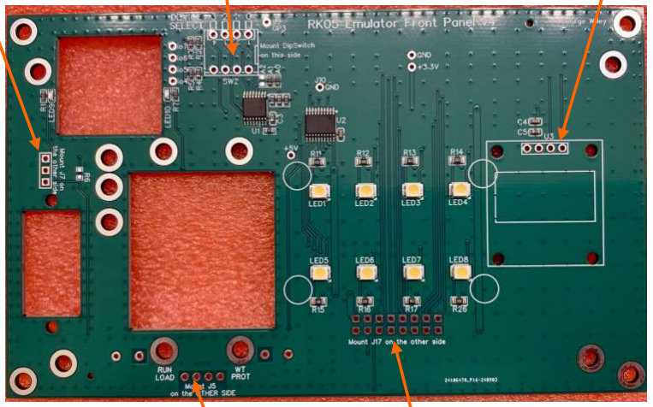
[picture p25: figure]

5-Nov-2024 | RK05 Emulator/Tester v2 & Accessories Assembly Instructions (document v04) | page 11
7. The 4-pin socket strip (343) and OLED display module (323) from bag H will be used in the “Front Panel Board mechanical assembly” sequence of steps, which are next.

Next page #1, U3, top side 4-position socket strip
(343)

#1, J17, bottom side

2x8 position header
(342)

#2, SW2, top side

4-position dipswitch
(317)

#3, J5, bottom side

Plug from plug/socket
set (318)

No component in J7

5-Nov-2024 | RK05 Emulator/Tester v2 & Accessories Assembly Instructions (document v04) | page 12

Front Panel Board mechanical assembly
Install the following parts on “J, Front Panel”. The parts referenced in the following instructions are from bag “F, Front Panel Board Hardware” and the previously assembled microSD board and carrier bracket.
1. In 2 places, near U3, install the M2 nylon flat washer (325) and M2 10mm Threaded Spacer (324) on the top side, and M2 split lock washer (322) on the bottom side and secure this stack of hardware using the M2 x 8 mm screw (315) from the bottom side. A detail of this stack-up is shown below. The recommended sequence is:
a. place the M2 split lock washer (322) onto the M2 x 8 mm screw (315)
b. insert the M2 x 8 mm screw into the hole in the PCB
c. place the M2 nylon flat washer (325) over the end of the screw
d. thread the M2 10mm Threaded Spacer (324) over the end of the screw
2. In 8 places, install an M3 x 12 mm Threaded Spacer (326) on the top side and secure it using an M3 x 6 mm screw (327) from the bottom side. The locations of the threaded spacers and mounting screws are shown in the diagram below. Be careful not to confuse the M3 x 6 mm screws with the two M3 x 8 mm screws that are in the same bag. The M3 x 8 mm screws are used later in step #6.

M3 x 12 mm threaded spacer, top side (326),

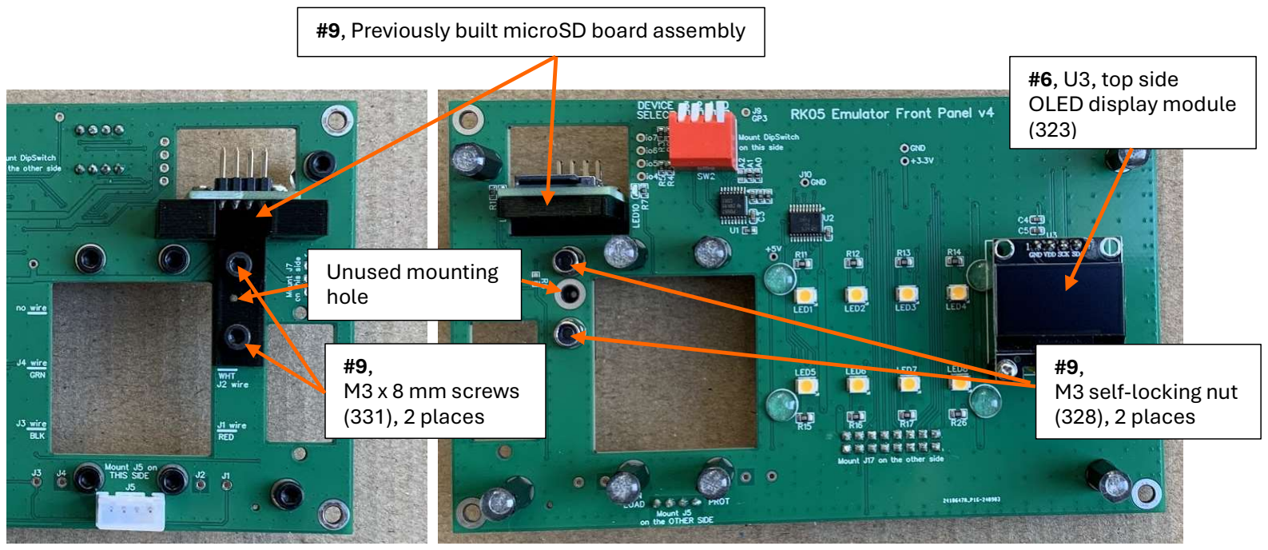
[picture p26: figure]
#6, U3, top side OLED display module (323); #9, M3 x 8 mm screws (331), 2 places; #9, M3 self-locking nut (328), 2 places; Unused mounting hole

5-Nov-2024 | RK05 Emulator/Tester v2 & Accessories Assembly Instructions (document v04) | page 13
3. In 8 places, as shown in the figure, install 6 mm diameter Self-Adhesive Clear Rubber Feet (329) on top of the standos that were installed in step #2.
4. In 4 places, install 6 mm diameter Self-Adhesive Clear Rubber Feet (329) on the top side of the Front Panel Board near LED1, LED4, LED5, and LED8, as shown. These four rubber feet hold the Lamp Lens in place when the unit is assembled.
5. Locate the 4-pin socket strip (343) and OLED display module (323) from bag H. Plug the OLED display module pins into the 4-pin socket strip. The display and socket strip have no polarity.
6. Install the OLED display module with attached 4-pin socket strip so that the 4-pin socket strip pins to into the four pads at location U3 and the lower two mounting holes of the OLED display module are positioned over the two M2 threaded spacers that were installed in step #1.
7. Attach the OLED display module to the two M2 threaded spacers using the M2 x 4 mm screws (321). Before tightening the screws, ensure that the OLED display module is square with the edges of the PCB. This is so the display will be nicely aligned with the front panel when the display is viewed from the front of the unit.
8. Solder the 4-pin socket strip to the PCB on the bottom side at the U3 pad locations.
9. Attach the previously built microSD board assembly to the Front Panel Board (101) using two M3 x 8 mm screws (331) and two M3 self-locking nuts (328). Insert the screws from the bottom side of the Front Panel Board and the microSD mounting bracket and self-locking nuts from the top side of the Front Panel Board. The middle screw hole in the PCB is unused. Tighten the screws while supporting the self-locking nuts, taking care to keep the bracket with the microSD card square.
10. Remove the protective film from the OLED display. There’s a small blue tab at the top-right corner of the display that can be pulled to remove the protective film.

#9, Previously built microSD board assembly

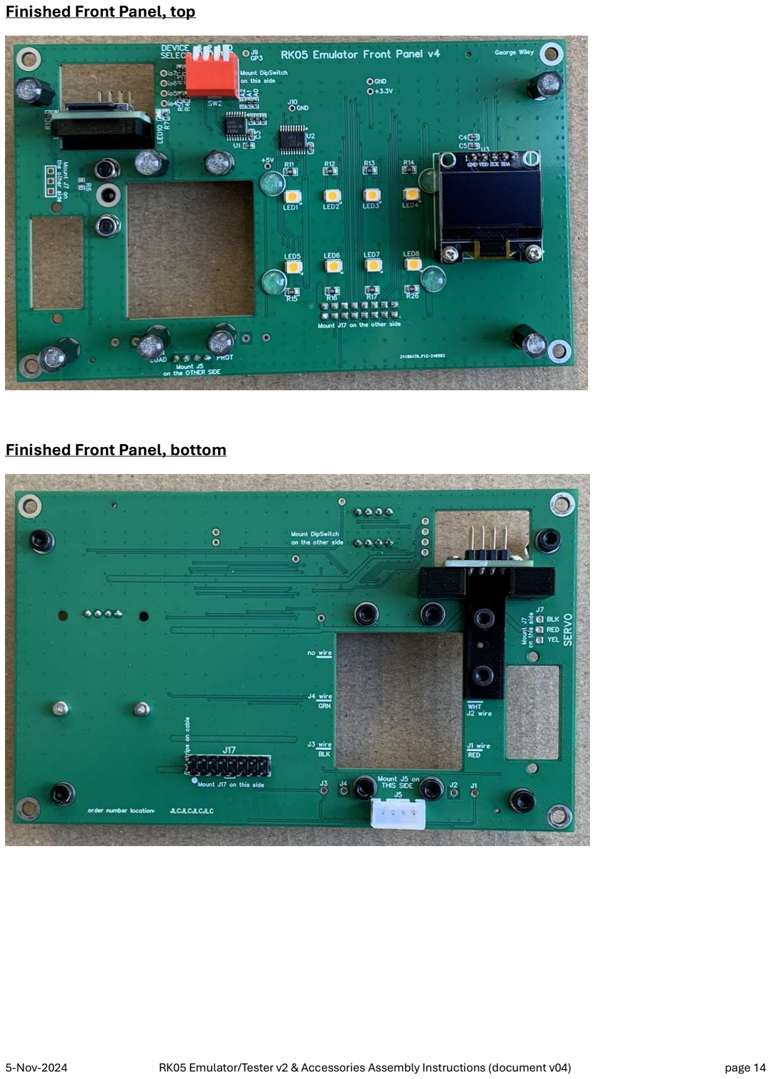
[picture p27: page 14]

5-Nov-2024 | RK05 Emulator/Tester v2 & Accessories Assembly Instructions (document v04) | page 14

Finished Front Panel, top

Finished Front Panel, bottom

5-Nov-2024 | RK05 Emulator/Tester v2 & Accessories Assembly Instructions (document v04) | page 15

Top Level assembly
Assemble the modules built in the previous steps using parts from: bag “A, Top-Level Front Panel”, bag “B, Bezel”, envelope “C, Dress Panel”, bag “D, Top-Level Hardware”, bag “N, Flat Cables”, and bag “P, RPi Pico”.
1. Install the momentary Rocker switch, on-mom (303) from bag A into the right switch opening in the Dress Panel (103) from bag C. This opening in the Dress Panel has the legend “WT PROT” on the front side of the Dress Panel. Orient the switch so the dot on the rocker handle is close to the “WT PROT” legend. Press the switch into the opening in the Dress Panel so the latches on the switch lock into place. Graphics and text on the bottom-side silkscreen of the Dress Panel are a helpful guide for inserting the switch with the proper orientation.
2. Install the on-o two-position Rocker switch (304) from bag A into the left switch opening in the Dress Panel (103). This opening in the Dress Panel has the legends “RUN” and “LOAD” on the front side of the Dress Panel. Orient the switch so the two terminals on the back of the switch are toward the lower edge of the Dress Panel. Press the switch into the opening in the Dress Panel so the latches on the switch lock into place. Graphics and text on the bottom-side silkscreen of the Dress Panel are a helpful guide for inserting the switch with the proper orientation.
3. Insert the Light Shield (207) from bag A into the top of the RK05 Lamp Lens (200) from bag A. The slots in the walls of the Light Shield face downward so they engage with the ribs between compartments of the Lamp Lens. The Light Shield is symmetrical so it can be installed in either direction on the long axis of the Lamp Lens. In some kits, the Light Shield and Lamp Lens are already connected. A photo shows an example of the Light Shield installed in the Lamp Lens. The photo of the Light Shield is shown upside down so the slots in the bottom are visible.
Lamp Lens (200) | Light Shield (207) | Lamp Lens with Light Shield
4. Insert the RK05 Lamp Lens with Light Shield into the eight square indicator holes in the Dress Panel (103) from envelope C. The body of the RK05 Lamp Lens should be between the Dress Panel and the Front Panel Board when the unit is assembled. The Lamp Lens is symmetrical so it can be installed in either direction.
5. Insert the assembled Dress Panel into the Bezel (201) from bag B so that the bottom edge of the Dress Panel is adjacent to the long edge of the Bezel that has the high outer wall.
6. Attach the assembled Front Panel Board to the Bezel and Dress Panel so that the large rectangular hole in the Front Panel Board aligns with the rocker switches. The top side of the Front Panel Board is oriented towards the Dress Panel, so the LEDs on the Front Panel Board face the Lamp Lens. Use four 30 mm threaded spacers (369) from bag D to hold the Front Panel Board in place by inserting the spacers through the mounting holes at the four corners of the Front Panel Board and

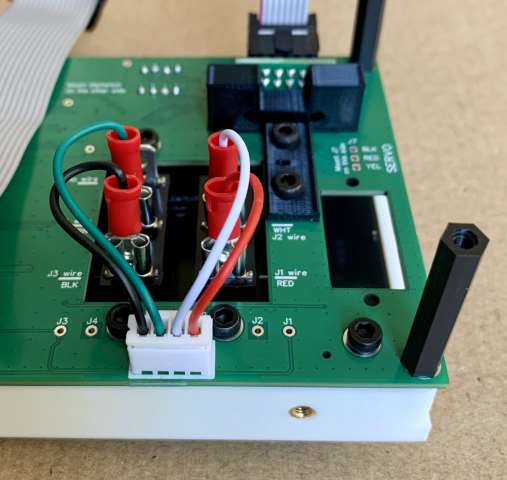
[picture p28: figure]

5-Nov-2024 | RK05 Emulator/Tester v2 & Accessories Assembly Instructions (document v04) | page 16

screwing the posts on the spacers into the threaded inserts in the bezel mounting holes. Be careful not to cross-thread the spacers. They should screw in easily.
7. Connect the Quick Spade Wire Connectors attached to the red and white wires from J5 to the terminals on the “RUN/LOAD” switch. Graphics and text on the bottom-side silkscreen of the Front Panel Board indicate which wire color to attach to each terminal on the switch. (see photo)
8. Connect the Quick Spade Wire Connectors attached to the black and green wires from J5 to the terminals on the “WT PROT” switch. Graphics and text on the bottom-side silkscreen of the Front Panel Board indicate which wire color to attach to each terminal on the switch. (see photo)
9. Connect one end of the 8-pin flat cable (347), from bag N to the 2x4 header, J14, on the bottom-side of the Main Board. Choose the end of the flat cable that has the keying bump facing away from the main part of the cable. Match the keying bump on the side of the flat cable connector with the corresponding silkscreen bump image on J14 of the Main Board. Also, confirm that the red stripe on the cable is on the same side as the “Red stripe” notation on the Main Board silkscreen. When connected properly, the cable will lay across the bottom-side of the Main Board. (see photo)
10. Connect one end of the 16-pin flat cable (348), from bag N to the 2x8 header, J13, on the bottom side of the Main Board. Choose the end of the flat cable that has the keying bump facing toward the main part of the cable. Match the keying bump on the side of the flat cable connector with the corresponding silkscreen bump image on J13 of the Main Board. Also, confirm that the red stripe on the cable is on the same side as the “Red stripe on cable” notation on the Main Board

5-Nov-2024 | RK05 Emulator/Tester v2 & Accessories Assembly Instructions (document v04) | page 17

silkscreen. When connected properly, the cable will lay across the bottom side of the Main Board. (see photo)
11. Connect the free end of the 16-pin flat cable (348), to the 2x8 header, J17, on the bottom side of the Front Panel Board. Match the keying bump on the side of the flat cable connector with the corresponding silkscreen bump image on J17 of the Front Panel Board. Also, confirm that the red stripe on the cable is on the same side as the “Red stripe on cable” notation on the Front Panel Board silkscreen.
12. Connect the free end of the 8-pin flat cable (347), to the 2x4 header, J14, on the microSD Board. Match the keying bump on the side of the flat cable connector with the corresponding silkscreen bump image on J14 of the microSD Board. Also, confirm that the red stripe on the cable is on the same side as the “Red stripe” notation on the microSD Board silkscreen.
13. Use four M3 x 8 mm screws (331) and four M3 split lock-washers (332) to attach the Main Board to the threaded standos that hold the Front Panel assembly in place. First insert the screws into the lock-washers and then insert the screws with lock washers through the mounting holes in the corners of the Main Board. Be careful when inserting the screw in the bottom corner of the Main Board that is close to the reference oscillator X1. Tighten all four screws.
14. After the unit is assembled, tuck, fold, and crease the flat cables so they are away from the edge connector pins.
15. Install the Raspberry Pi Pico (309) from bag P into the socket pins at location U22 on the Main Board. The USB connector on the Pico should be aligned with the small notch and “U22” designator on the main board silkscreen.
16. Connect one end of the Power Cable to J3 on the Main Board.
17. The RK05 Emulator assembly is complete.

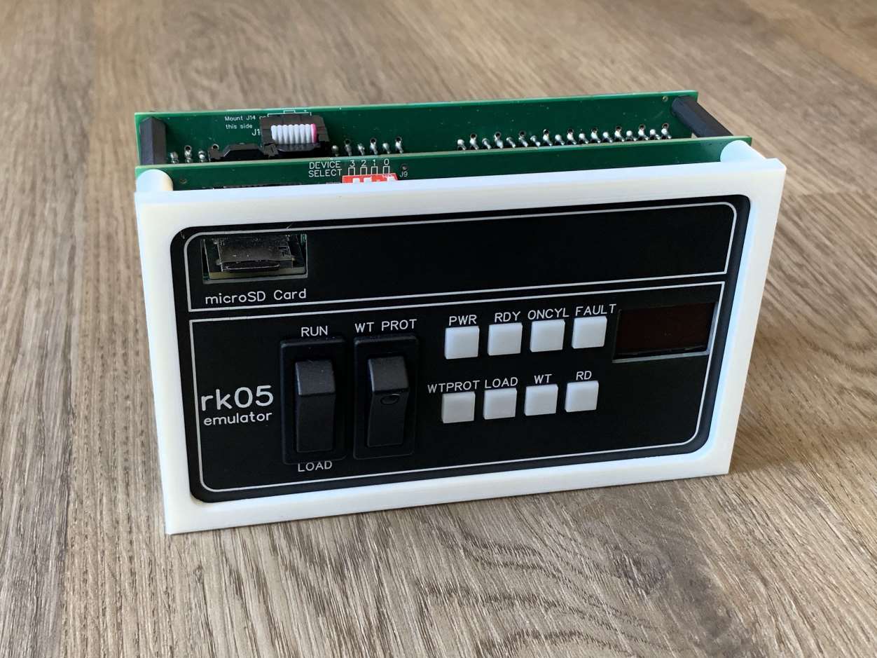
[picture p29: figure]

5-Nov-2024 | RK05 Emulator/Tester v2 & Accessories Assembly Instructions (document v04) | page 18

Finished Emulator, top-level

5-Nov-2024 | RK05 Emulator/Tester v2 & Accessories Assembly Instructions (document v04) | page 19

## A1 RK05-to-RK8-E Cable, 1 meter length

RK05-to-RK8-E Cable, 1 meter length, kit of parts:

Install the following parts on the M993GW RK05 Adapter Card (105) from bag “BE, Adapter PCB”. The parts referenced in the following instructions are from bag “H1, Adapter HW”.
1. Install and solder two 40-pin right-angle headers (336) on the top side of the M993GW RK05 Adapter Board (105) at locations J1 and J2. There is no hardware used to attach J1 and J2.
2. Loosely install the Cable Clamp (205) on the top side of the adapter board using two M3 x 12 mm screws (334) and two M3 self-locking nuts (328). The wide slot on the cable clamp faces the Adapter Board. Also, the beveled corner of the Cable Clamp points towards J2. Don’t tighten the screws and nuts now. Wait until flat cables are installed later.

Header, 40-pin, right-angle, top side (336)

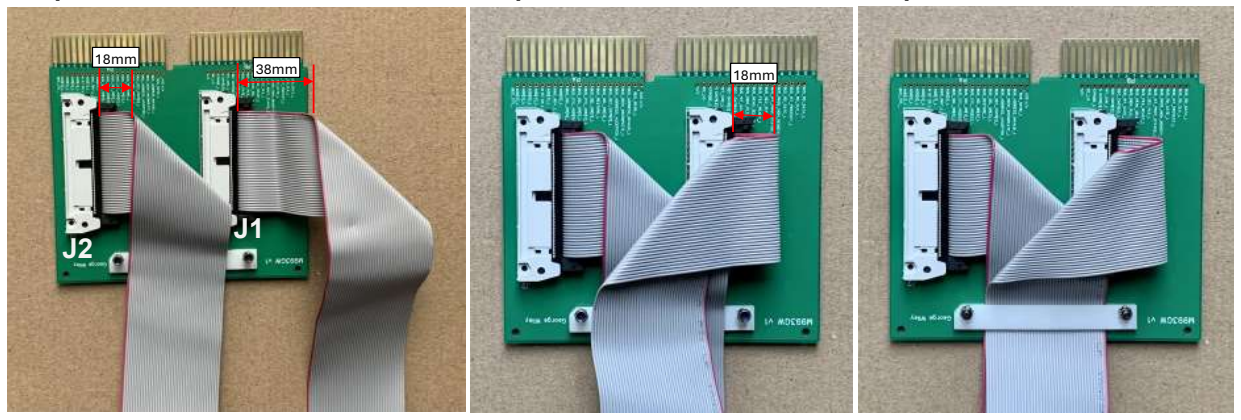
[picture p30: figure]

5-Nov-2024 | RK05 Emulator/Tester v2 & Accessories Assembly Instructions (document v04) | page 20

Assemble the cable using the board built in the previous steps and the flat cables from bag “C1, Cables 1m”.
1. Insert one end of one of the 40-pin flat cables (349) into J1 on the M993GW RK05 Adapter Card. Notice that the keying bump should face up to correspond with the slot on the slot in the J1 connector body. The red stripe on the flat cable should be towards the gold fingers on the Adapter Card.
2. Insert one end of the second flat cable into J2 on the M993GW RK05 Adapter Card. Similarly, notice the keying bump orientation and the direction of the red stripe on the flat cable.
3. Fold each of the flat cables with a diagonal fold as shown in the photo. For the cable in J2, the diagonal fold of the side of the cable with the red stripe should begin about 18 mm from the body of the flat cable connector. For the cable in J1, the diagonal fold of the side of the cable with the red stripe should begin about 38 mm from the body of the flat cable connector.
4. For the cable in J1, fold and crease the cable about 18 mm from the body of the flat cable connector so that the cable folds onto itself. Refer to the photo for an example.
5. Loosen a screw holding one side of the Cable Clamp (205), tuck both cables underneath the Cable Clamp, and re-install the screw and self-locking nut. Tighten the screws that hold each side of the Cable Clamp in place. While tightening the screws, hold and position the flat cables so the cables extend perpendicular to the back edge of the Adapter Card. Take care to route the flat cables through the wide slot underneath the Cable Clamp before completely tightening the screws.
6. The free ends of the flat cables connect to the disk controller: either a DEC RK8-E or Plessey PM-DC/8. The Plessey PM-DC/8 has flat cable connectors with keying notches similar to the connectors used on the M993GW RK05 Adapter Card, so the cables in this kit can plug directly into the PM-DC/8 without any modifications. However, the DEC RK8-E has Berg connectors without a keying notch. When the RK05 emulator is used with the DEC RK8-E it is necessary to sand the keying bumps on the free ends of the flat cables so they can fit into the Berg connectors on the RK8-E. This is easily done using a Dremel tool with a coarse abrasive tool tip.
Step #3 | Step #4 | Step #5

The System Setup Guide describes how to connect the free ends of this cable to the disk controller, either the DEC RK8-E or Plessey PM-DC/8.

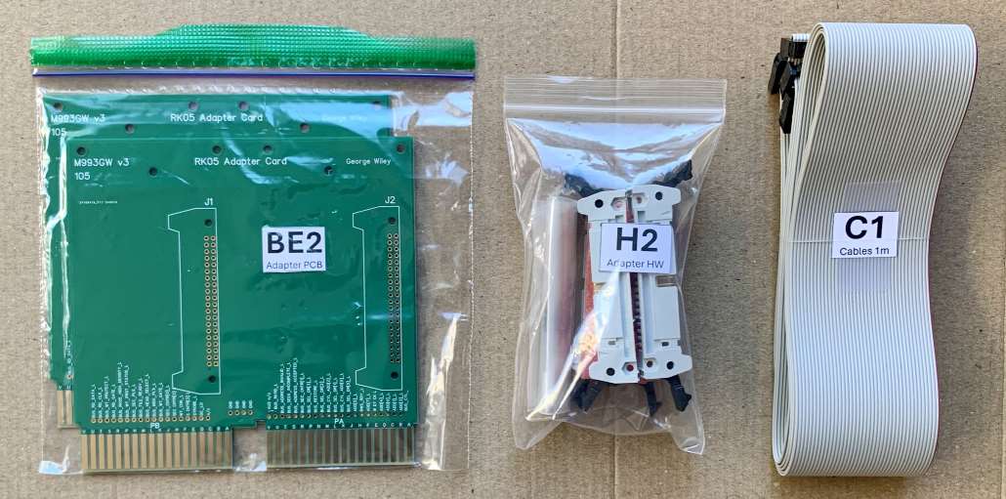
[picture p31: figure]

5-Nov-2024 | RK05 Emulator/Tester v2 & Accessories Assembly Instructions (document v04) | page 21

## A2 RK05-to-RK05 Cable, 1 meter length

RK05-to-RK05 Cable, 1 meter length, kit of parts:

Install the following parts on the M993GW RK05 Adapter Card (105). Since there are two RK05 Adapter PCBs in the kit, the following steps are performed twice. Two M993GW RK05 Adapter PCBs are from bag “BE2, Adapter PCB”. The parts referenced in the following instructions are from bag “H2, Adapter HW”.
1. Install and solder two 40-pin right-angle headers (336) on the top side of the M993GW RK05 Adapter Board (105) at locations J1 and J2. There is no hardware used to attach J1 and J2.
2. Loosely install the Cable Clamp (205) on the top side of the adapter board using two M3 x 12 mm screws (334) and two M3 self-locking nuts (328). The wide slot on the cable clamp faces the Adapter Board. Also, the beveled corner of the Cable Clamp points towards J2. Don’t tighten the screws and nuts now. Wait until flat cables are installed later.
3. Repeat steps 1 and 2 with the second M993GW RK05 Adapter PCB.

Header, 40-pin, right-angle, top side (336)

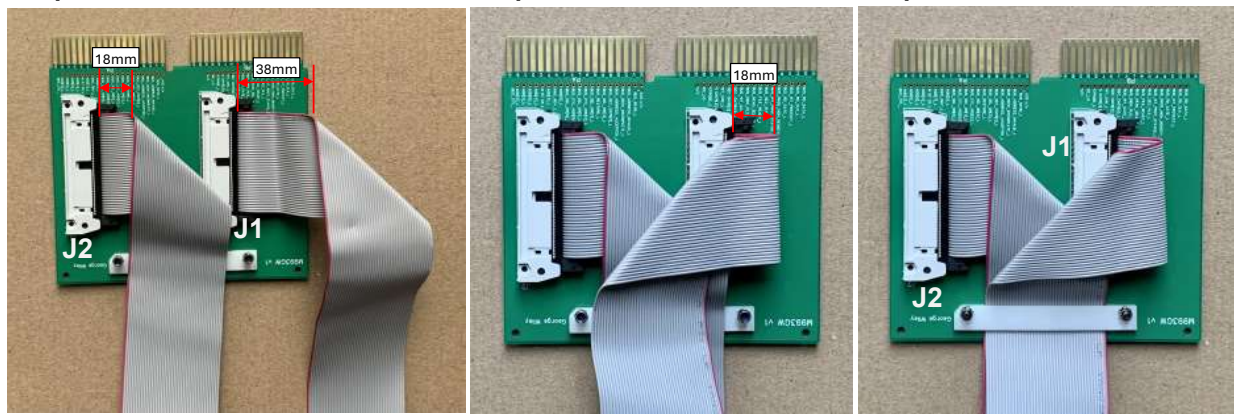
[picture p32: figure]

5-Nov-2024 | RK05 Emulator/Tester v2 & Accessories Assembly Instructions (document v04) | page 22

Assemble the cable using the two boards built in the previous steps and the flat cables from bag “C1, Cables 1m”.
1. Insert one end of one of the flat cables into J1 on the first M993GW RK05 Adapter Card. Notice that the keying bump should face up to correspond with the slot on the slot in the J1 connector body. The red stripe on the flat cable should be towards the gold fingers on the Adapter Card.
2. Insert one end of the second flat cable into J2 on the first M993GW RK05 Adapter Card. Similarly, notice the keying bump orientation and the direction of the red stripe on the flat cable.
3. Fold each of the flat cables with a diagonal fold as shown in the photo. For the cable in J2, the diagonal fold of the side of the cable with the red stripe should begin about 18 mm from the body of the flat cable connector. For the cable in J1, the diagonal fold of the side of the cable with the red stripe should begin about 38 mm from the body of the flat cable connector.
4. For the cable in J1, fold and crease the cable about 18 mm from the body of the flat cable connector so that the cable folds onto itself. Refer to the photo for an example.
5. Loosen a screw holding one side of the Cable Clamp (205), tuck both cables underneath the Cable Clamp, and re-install the screw and self-locking nut. Tighten the screws that hold each side of the Cable Clamp in place. While tightening the screws, hold and position the flat cables so the cables extend perpendicular to the back edge of the Adapter Card. Take care to route the flat cables through the wide slot underneath the Cable Clamp before completely tightening the screws.
6. Connect the free ends of the flat cables to the second M993GW RK05 Adapter Card as before, following steps 1 through 5 above. The cable connected to J1 on the first Adapter Card should connect to J1 on the second Adapter Card. Similarly, the cable connected to J2 on the first Adapter Card should connect to J2 on the second Adapter Card.

The following tip simplifies routing of the cables to the second Adapter Card: lay the first Adapter Card (that already has the cables attached) face down on the workbench and lay the second Adapter Card face up on the workbench. The gold fingers on each of the Adapter Cards should point away from the other Adapter Card. Now fold and connect the J1 cable per the instructions above, and next connect the J2 cable per the instructions above.
Step #3 | Step #4 | Step #5

Notice in the Step #5 photo that the J1 cable is on top and the J2 cable is on the bottom. At the other end of the cable, do the reverse. Put the J1 cable on the bottom and the J2 cable on the top. This way, the cables will lay flat without a twist in one of the cables.

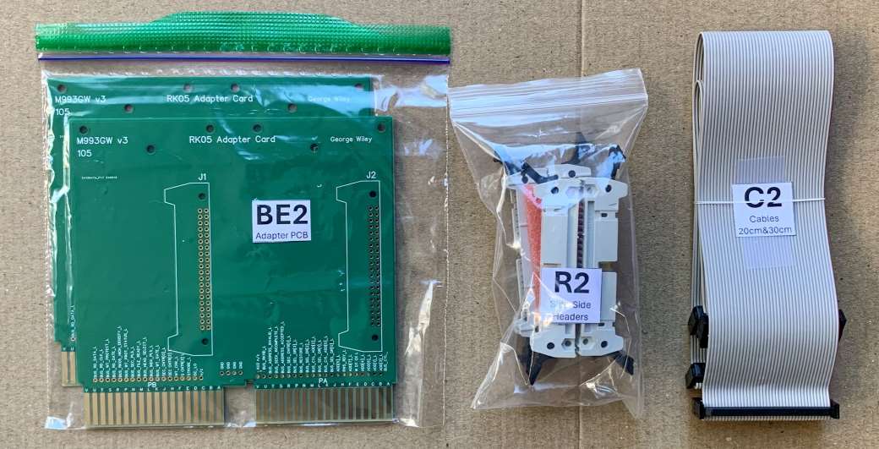
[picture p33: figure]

5-Nov-2024 | RK05 Emulator/Tester v2 & Accessories Assembly Instructions (document v04) | page 23

## A3 RK05-to-RK05 Cable, Side-to-Side

RK05-to-RK05 Cable, Side-to-Side, 20cm length, kit of parts:

Install the following parts on the M993GW RK05 Adapter PCB. Since there are two RK05 Adapter PCBs in the kit, the following steps are performed twice. Two M993GW RK05 Adapter PCBs are in bag “BE2, Adapter PCB”. The parts referenced in the following instructions are from bag “R2, Side-Side Headers”. This kit does not need cable clamps so they are not included.
1. Install and solder two 40-pin right-angle headers (336) on the top side of the M993GW RK05 Adapter Board (105) at locations J1 and J2. There is no hardware used to attach J1 and J2.
2. Repeat step 1 with the second M993GW RK05 Adapter PCB.

#1, J1 & J2:

Header, 40-pin, right-angle, top side (336)

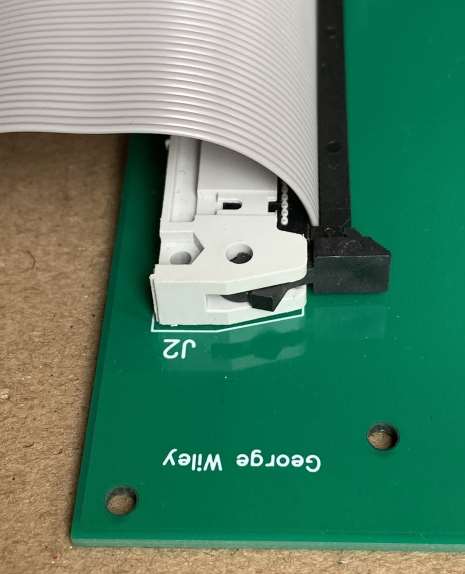
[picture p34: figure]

5-Nov-2024 | RK05 Emulator/Tester v2 & Accessories Assembly Instructions (document v04) | page 24

Assemble the cable using the two boards built in the previous steps and the flat cables from bag “C2, Cables 20cm&30cm”.
1. Find the end of the 30 cm flat cable (361) that has the keying bump facing away from the flat cable. This is the longer of the two flat cables. Insert this end of the 30 cm flat cable into J2 of the first M993GW RK05 Adapter Card. Notice that the keying bump should face up to correspond with the slot in the J2 connector body and the cable will be routed close to the Adapter Card. The red stripe on the flat cable should be towards the gold fingers on the Adapter Card.
2. Insert the other end of the 30 cm flat cable connected in the previous step into J2 on the second M993GW RK05 Adapter Card. Similarly, notice the keying bump orientation and the direction of the red stripe on the flat cable. At this end of the cable, the gray flat cable will leave the connector away from the Adapter Card.
3. Find the end of the 20 cm flat cable (370) that has the keying bump facing away from the flat cable. This is the shorter of the two flat cables. Insert this end of the 20 cm flat cable into J1 of the first M993GW RK05 Adapter Card. Notice that the keying bump should face up to correspond with the slot in the J1 connector body and the cable will be routed close to the Adapter Card. The red stripe on the flat cable should be towards the gold fingers on the Adapter Card.
4. Insert the other end of the 20 cm flat cable connected in the previous step into J1 on the second M993GW RK05 Adapter Card. Similarly, notice the keying bump orientation and the direction of the red stripe on the flat cable. At this end of the cable, the gray flat cable will leave the connector away from the Adapter Card.
J2, first Adapter Card | J2, second Adapter Card
J2 | J1 | 20 cm cable | J2 | J1

### 30 cm cable

First Adapter Card | Second Adapter Card

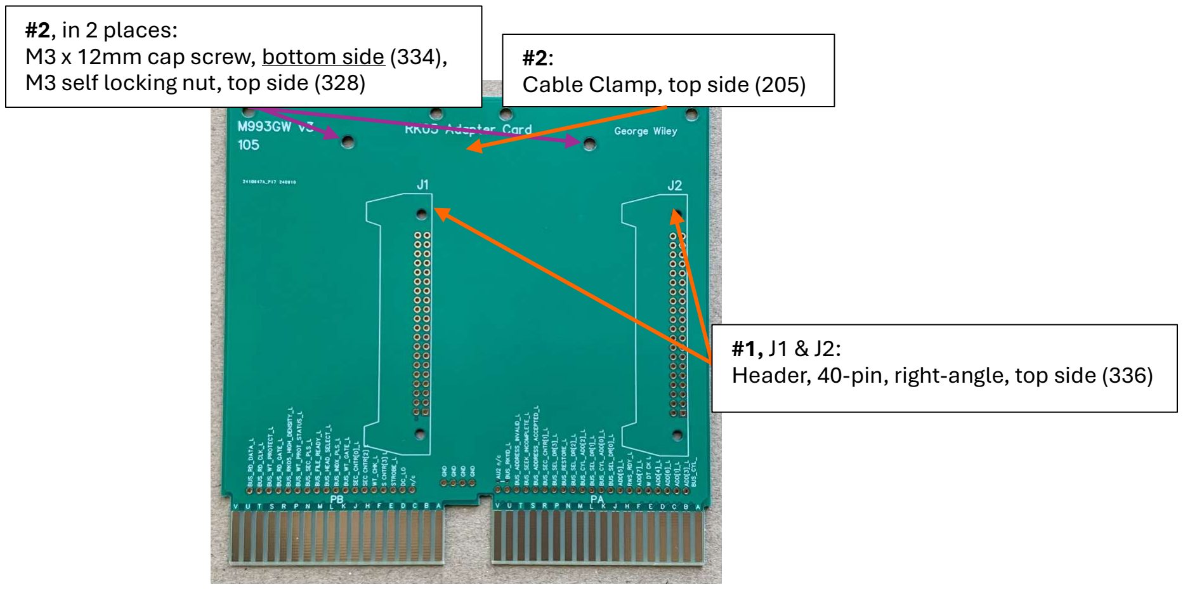
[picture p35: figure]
#2, in 2 places: M3 x 12mm cap screw, bottom side (334), M3 self locking nut, top side (328); #2: Cable Clamp, top side (205)

5-Nov-2024 | RK05 Emulator/Tester v2 & Accessories Assembly Instructions (document v04) | page 25

## A4 RK05 Adapter Board without flat cables

RK05 Adapter Board kit of parts:

Install the following parts on the M993GW RK05 Adapter Card from bag “BE, Adapter PCB”. The parts referenced in the following instructions are from bag “H1, Adapter HW”.
1. Install and solder two 40-pin right-angle headers (336) on the top side of the M993GW RK05 Adapter Board (105) at locations J1 and J2. There is no hardware used to attach J1 and J2.
2. Loosely install the Cable Clamp (205) on the top side of the adapter board using two M3 x 12 mm screws (334) and two M3 self-locking nuts (328). The wide slot on the Cable Clamp faces the Adapter Board. Also, the beveled corner of the Cable Clamp points towards J2. Don’t tighten the screws and nuts now. Wait until the flat cables are installed later.

Header, 40-pin, right-angle, top side (336)

5-Nov-2024 | RK05 Emulator/Tester v2 & Accessories Assembly Instructions (document v04) | page 26

Finished RK05 Adapter Board without flat cables, top

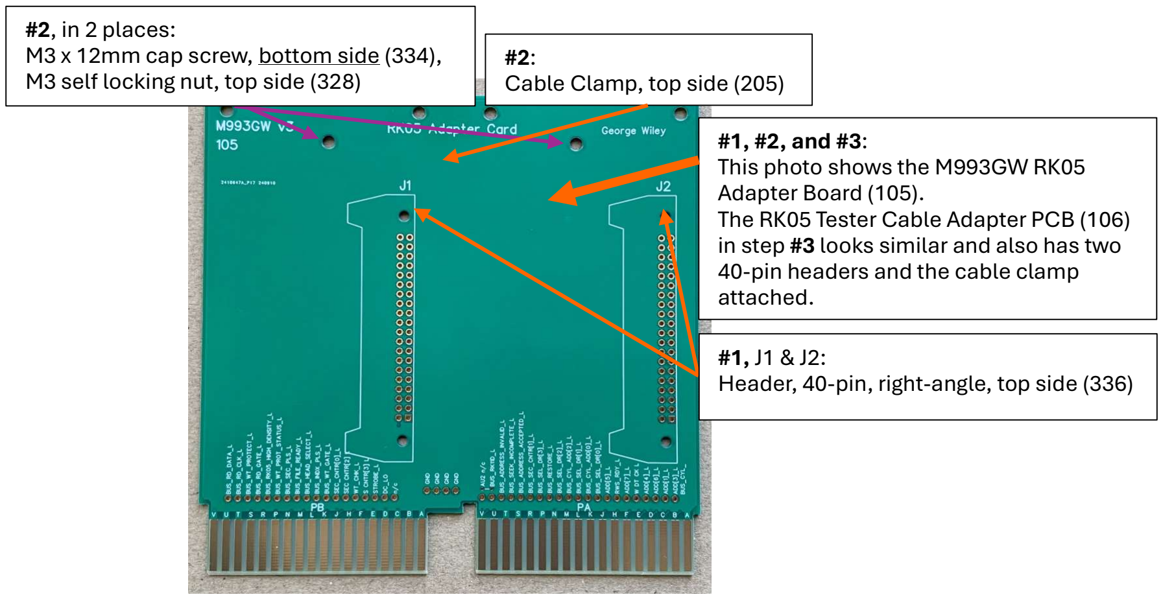
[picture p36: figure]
#2: Cable Clamp, top side (205); #1, #2, and #3: This photo shows the M993GW RK05 Adapter Board (105). The RK05 Tester Cable Adapter PCB (106); 40-pin headers and the cable clamp attached.; #2, in 2 places: M3 x 12mm cap screw, bottom side (334), M3 self locking nut, top side (328)

5-Nov-2024 | RK05 Emulator/Tester v2 & Accessories Assembly Instructions (document v04) | page 27

## A5 RK05-to-Tester Cable, 1 meter length

RK05-to-Tester Cable, 1 meter length, kit of parts:

Install the following parts on the M993GW RK05 Adapter PCB and the Tester Adapter PCB. Since there are two similar PCBs in the kit, the following steps are performed on each of the two boards. The two PCBs are in bag “BE, Adapter PCB” and bag “BT, Tester Adapter PCB”. The parts referenced in the following instructions are from bag “H2, Adapter HW”.
1. Install and solder two 40-pin right-angle headers (336) on the top side of the M993GW RK05 Adapter Board (105) at locations J1 and J2. There is no hardware used to attach J1 and J2.
2. Loosely install the Cable Clamp (205) on the top side of the adapter board using two M3 x 12 mm screws (334) and two M3 self-locking nuts (328). The wide slot on the cable clamp faces the Adapter Board. Also, the beveled corner of the Cable Clamp points towards J2. Don’t tighten the screws and nuts now. Wait until flat cables are installed later.
3. Repeat steps 1 and 2 but install parts onto the RK05 Tester Cable Adapter PCB (106).

Header, 40-pin, right-angle, top side (336) in step #3 looks similar and also has two

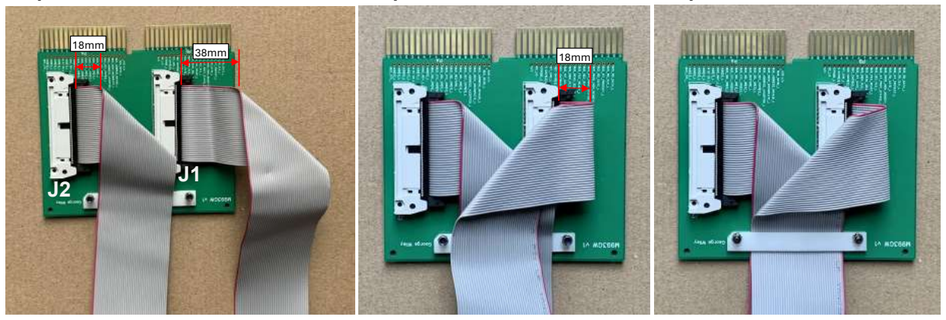
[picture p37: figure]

5-Nov-2024 | RK05 Emulator/Tester v2 & Accessories Assembly Instructions (document v04) | page 28

Assemble the cable using the two boards built in the previous steps and the flat cables from bag “C1, Cables 1m”.
1. Insert one end of one of the flat cables into J1 on the M993GW RK05 Adapter Card. Notice that the keying bump should face up to correspond with the slot on the slot in the J1 connector body. The red stripe on the flat cable should be towards the gold fingers on the Adapter Card.
2. Insert one end of the second flat cable into J2 on the M993GW RK05 Adapter Card. Similarly, notice the keying bump orientation and the direction of the red stripe on the flat cable.
3. Fold each of the flat cables with a diagonal fold as shown in the photo. For the cable in J2, the diagonal fold of the side of the cable with the red stripe should begin about 18 mm from the body of the flat cable connector. For the cable in J1, the diagonal fold of the side of the cable with the red stripe should begin about 38 mm from the body of the flat cable connector.
4. For the cable in J1, fold and crease the cable about 18 mm from the body of the flat cable connector so that the cable folds onto itself. Refer to the photo for an example.

### 5. Loosen one of the screws holding one side of the Cable Clamp (205), tuck both cables

underneath the Cable Clamp, and re-install the screw and self-locking nut. Tighten the screws that hold each side of the Cable Clamp in place. While tightening the screws, hold and position the flat cables so the cables extend perpendicular to the back edge of the Adapter Card. Take care to route the flat cables through the wide slot underneath the Cable Clamp before completely tightening the screws.
6. Connect the free ends of the flat cables to the RK05 Tester Cable Adapter Card as before, following steps 1 through 5 above. The cable connected to J1 on the M993GW RK05 Adapter Card should connect to J1 on the RK05 Tester Cable Adapter Card. Similarly, the cable connected to J2 on the M993GW RK05 Adapter Card should connect to J2 on the RK05 Tester Cable Adapter Card.
Step #3 | Step #4 | Step #5

The following tip simplifies routing of the cables to the RK05 Tester Cable Adapter Card: lay the M993GW RK05 Adapter Card (that already has the cables attached) face down on the workbench and lay the RK05 Tester Cable Adapter Card face up on the workbench. The gold fingers on each of the Adapter Cards should point away from the other Adapter Card. Now fold and connect the J1 cable per the instructions above, and next connect the J2 cable per the instructions above. To prevent the cables from crossing, stack the J1 cable on top on one board and on the bottom on the other board.

5-Nov-2024 | RK05 Emulator/Tester v2 & Accessories Assembly Instructions (document v04) | page 29

## A6 RK05 Tester Board without flat cables

RK05 Tester Board kit of parts:

Install the following parts on the RK05 Tester Cable Adapter Board from bag “BT, Tester Adapter PCB”. The parts referenced in the following instructions are from bag “H1, Adapter HW”.
1. Install and solder two 40-pin right-angle headers (336) on the top side of the RK05 Tester Cable Adapter Board (106).
2. Install the Cable Clamp (205) on the top side of the adapter board using two M3 x 12 mm screws
(334) and two M3 self-locking nuts (328). The wide slot on the Cable Clamp faces the Adapter Board. Also, the beveled corner of the Cable Clamp points towards J2. Don’t tighten the screws now. Wait until the flat cables are installed later.
Refer to the photos and assembly guides for “A4 RK05 Adapter Board without flat cables” for additional details. The A4 and A6 accessories are visually quite similar except they use dierent PCBs.

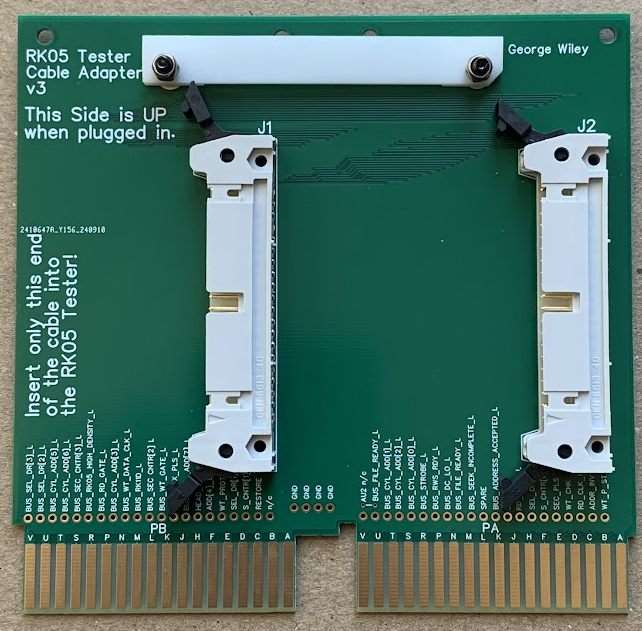
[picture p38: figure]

5-Nov-2024 | RK05 Emulator/Tester v2 & Accessories Assembly Instructions (document v04) | page 30

Finished RK05 Adapter Board without flat cables, top

5-Nov-2024 | RK05 Emulator/Tester v2 & Accessories Assembly Instructions (document v04) | page 31

## A7 & A7N RK05 Emulator Power Supply (version v3)

A7 Power Supply kit of parts:

The kit contents for A7 and A7N are very similar. The only dierence is that A7N does not include the USB Charger (CH). The assembly instructions for A7 and A7N are the same.

5-Nov-2024 | RK05 Emulator/Tester v2 & Accessories Assembly Instructions (document v04) | page 32

Power Supply Board electrical and mechanical assembly
Install the following parts on the RK05 Emulator Power Supply Board from bag “BP, PS Board”. The parts referenced in the following instructions can be found in bag “S4, PS HW & E”, “S5, PS Semi”, and bag “S1, Pwr Trigger”.
1. Install and solder the Power Trigger Module (351) from bag “S1, Pwr Trigger” on the top side of the RK05 Emulator Power Supply Board (107) using pins from the 4-pin header connector (352) through the four terminals at the end of the Power Trigger Module. Remove the plastic base of the 4-pin header and use only the pins. Solder the four pins on the top side of the Power Trigger Module and solder again on the bottom side of the RK05 Emulator Power Supply Board. Cut o any excess length of the pins after soldering.
2. Install and solder an SR540L rectifier (371) from bag “S5, PS Semi” on the top side at location D1. Take note of the correct polarity. The band indicating the cathode lead on the part corresponds to a similar band in the silkscreen image on the PCB. Cut the excess lead lengths on the bottom side.
3. Install and solder three 2-pin power connectors (340) on the top side at locations J21, J22, and J23. Take care to notice the silkscreen graphics that indicate the proper polarity.
4. Install the toggle switch (366) at location SW1.
5. Locate one of the 1.5-inch AWG 22 red-black zip cords (360). Slightly separate the red and black wires at each end. Strip about 0.15 inches (3.8 mm) of insulation from each end of the red and black wires. Slightly tin the stripped ends with solder. Remove any solder burrs on the ends of the wire so the wires will fit easily into the PCB pads in the next step.
6. Insert one end of the red wire into the hole closest to the edge of the board. Similarly, insert one end of the black wire into the hole farthest from the edge of the board. The board silkscreen has a guide that describes this. Solder both wires from the top side of the board.
Bend the other end of each wire in the shape of a small hook, put each wire through the small eyelets in the switch terminals. Connect the black wire to the center switch terminal and the red wire to the lower outside switch terminal as indicated on the silkscreen. Solder both wires to the switch terminals.
7. Install and solder a 4.7k resistor (372) from bag “S4, PS HW & E” on the top side at location R1. Cut the excess lead lengths on the bottom side.
8. Install and solder a 390 ohm resistor (377) from bag “S5, PS Semi” on the top side at location R2. Cut the excess lead lengths on the bottom side.

5-Nov-2024 | RK05 Emulator/Tester v2 & Accessories Assembly Instructions (document v04) | page 33
9. Install and solder a blue diused LED (378) from bag “S5, PS Semi” on the top side at location LED1. Be careful to install LED1 with the proper orientation. The flat side of the LED corresponds with the flat side of the graphic in the silkscreen. The flat side of the LED package is the side with the short lead. Cut the excess lead lengths on the bottom side after soldering.
10. Mount the DC-to-DC converter (359) on the top side of the Power Supply Board (107) using the “TOBSUN EA50-5V” silkscreen outline as a guide. Secure the DC-to-DC converter with two M3 x 8 mm screws (331) and two M3 self-locking nuts (328). Insert the M3 screws from the top side and tighten the M3 nuts onto the screws on the bottom side.
11. Locate two 1.5-inch AWG 22 red-black zip cords (360). Separate the red and black wires completely so there are two red wires and two black wires. Strip about 0.25 inches (6.4 mm) of insulation from one end of each of the wires.
12. Crimp a Fork Spade Lug terminal (362) onto the bare ends of each of the four wires stripped in the previous step. Optionally, add a small amount of solder to secure each of the crimped wires to the terminal improve the reliability of the connection. This is because the wire size is on the lower end of the compatibility range for the Fork Spade Lug terminals.
13. Strip about 0.15 inches (3.8 mm) of insulation from the other end of each 1.5-inch AWG 22 red and black wire (360). Slightly tin the stripped ends with solder. Remove any solder burrs on the ends of the wire so the wires will fit easily into the PCB pads in the next step.
14. Loosen the four screws on the terminal block on the DC-to-DC converter.
15. Insert the tinned ends of the red and black wires into J5 (red), J14 (black), J3 (black), and J12 (red) so the wires extend from the top side of the board. Silkscreen text describes proper installation: red to “+” and black to “-”. Don’t solder the wires to the PCB yet. Insert the Fork Spade Lugs crimped to the other end of each wire into the corresponding terminal block positions on the DC-to-DC converter that are each directly above J5, J14, J3, and J12.
16. Tighten the screws on the terminal block on the DC-to-DC converter.
17. Solder the four wires on the bottom side of the Power Supply Board and cut any excess length of exposed wire.
18. At each of the four corners of the Power Supply Board, install M3 x 20 mm Threaded Spacers (357) on the bottom side and secure them on the top side using M3 lock washers (332) and M3 nuts (328). Locations of the threaded spacers, lock washers, and nuts are shown in the diagram below. Some kits may have 25mm threaded spacers (301) instead of 20 mm threaded spacers.

Flat side of LED (short lead)

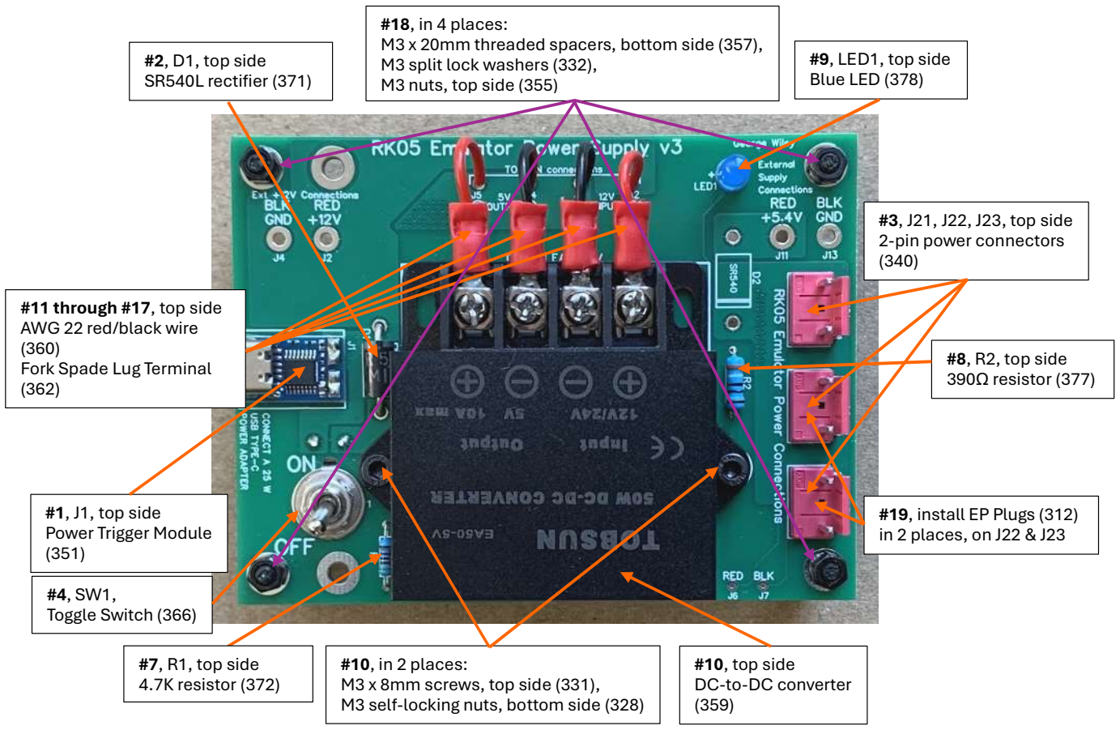
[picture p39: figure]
#1, J1, top side Power Trigger Module (351); #3, J21, J22, J23, top side 2-pin power connectors (340); #10, top side DC-to-DC converter (359); #11 through #17, top side AWG 22 red/black wire (360) Fork Spade Lug Terminal (362); #10, in 2 places: M3 x 8mm screws, top side (331), M3 self-locking nuts, bottom side (328); #7, R1, top side 4.7K resistor (372); #19, install EP Plugs (312) in 2 places, on J22 & J23; #18, in 4 places:; M3 split lock washers (332), M3 nuts, top side (355); #2, D1, top side SR540L rectifier (371); #4, SW1, Toggle Switch (366); #9, LED1, top side Blue LED (378)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

5-Nov-2024 | RK05 Emulator/Tester v2 & Accessories Assembly Instructions (document v04) | page 34
19. Install EP Plugs (312) onto J22 and J23. This protects the pins from shorting while in use.

M3 x 20mm threaded spacers, bottom side (357),

5-Nov-2024 | RK05 Emulator/Tester v2 & Accessories Assembly Instructions (document v04) | page 35

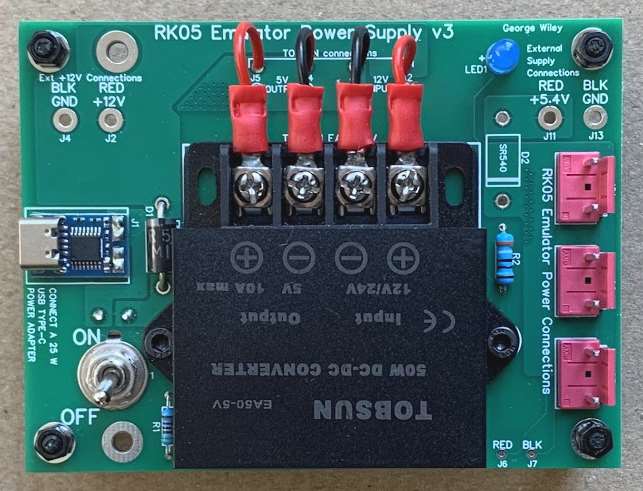
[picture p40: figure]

Finished Power Supply, top (A7 & A7N) | 25 Watt USB Type C charger (A7 only)

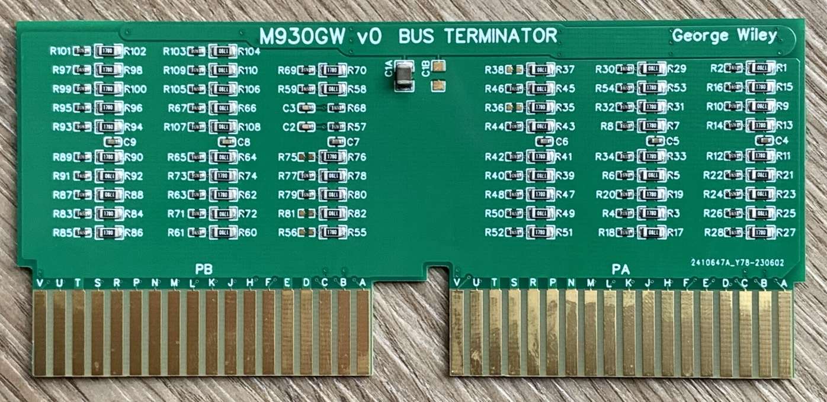
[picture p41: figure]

5-Nov-2024 | RK05 Emulator/Tester v2 & Accessories Assembly Instructions (document v04) | page 36

## T1 M930GW Terminator Board

Terminator Board parts:

1. No assembly is needed. All SMT assembly of the Terminator Board has been performed by the manufacturer.

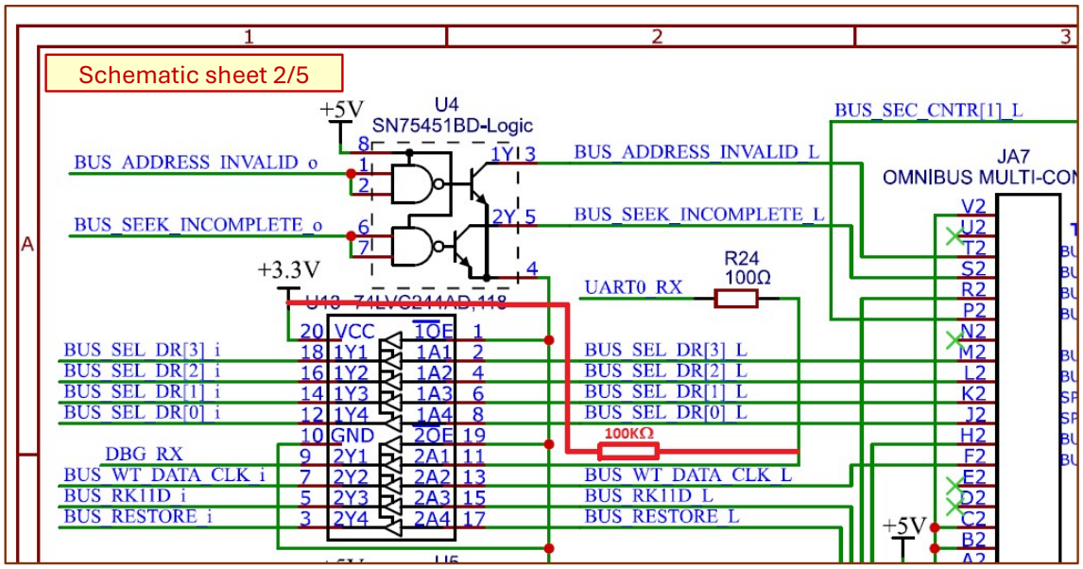
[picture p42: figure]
Schematic sheet 2/5

5-Nov-2024 | RK05 Emulator/Tester v2 & Accessories Assembly Instructions (document v04) | page 37

## Rework Instructions

Rework to fix an intermittent boot-up problem (for board serial numbers 0040 and below, serial numbers 0041 and above already have the rework)
An issue was discovered that causes the Raspberry Pi Pico controller in the emulator to intermittently not boot up properly. The symptoms are when power is applied, some of the front panel lights are illuminated, the display is blank, and the emulator hasn’t booted up fully.
This is caused by coupling of signals onto the debug port serial input which is floating and not properly pulled to a known state when a USB serial cable is not connected to the debug port. The fix is to solder a 100K Ω pullup resistor between the on-board +3.3V supply and the 74LVC244 receiver input for the serial debug port.
The following instructions describe the procedure to attach the resistor to a convenient place on the main board.
A 100K ohm resistor will be connected from U13-11 to U13-20 as shown in the schematic diagram.

There is a software improvement that prevents the system from locking up due to activity on the serial port input during the boot-up process. It’s not required but recommended to install Raspberry Pi software version 2.7 or higher in addition to the rework to add the pullup on the serial port input.
Although the use of software version 2.7 or higher will allow the system to boot properly without performing the rework, the rework is highly recommended because it prevents random characters from appearing on the serial port input during normal operation when a USB serial cable is not attached. The emulator responds to certain one-character commands during normal operation to enable debug logging modes. Inadvertent random characters on the serial input could cause the emulator to enter a logging mode which might change its operating behavior. Adding the pullup prevents this issue from happening. Recommendation: perform the rework and use software version 2.7 or higher. Main board serial numbers 0041 or higher already have the pullup on the serial port.

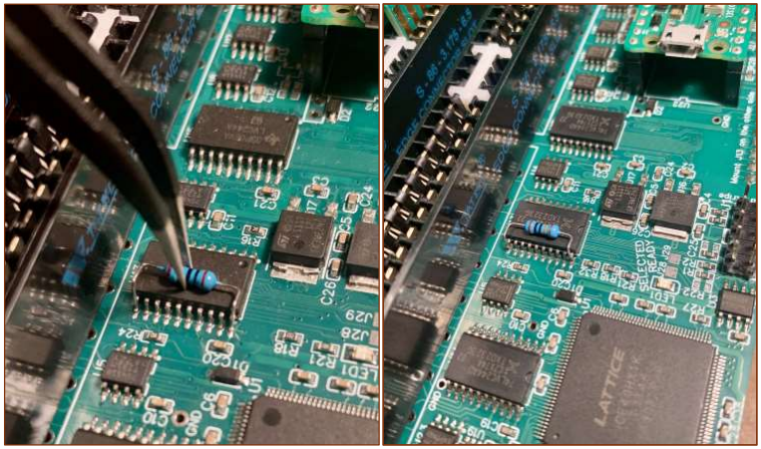
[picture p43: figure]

5-Nov-2024 | RK05 Emulator/Tester v2 & Accessories Assembly Instructions (document v04) | page 38

Bend the leads of a 100K Ω resistor so that the bent wires are 0.45” apart. Then bend each lead once more and cut, as shown below.

In the following steps we will solder one lead of the resistor to U13 pin 11 and the other to U13 pin 20. For lead-free solder, Sn / Ag / Cu: 99% / 0.3% / 0.7%, use a small pointed soldering tip and set the temperature to about 350°C.
1. Place the 100K Ω resistor, with leads bent, on top of U13.
2. Hold the resistor in-place with tweezers. With a little melted solder on the iron tip, lightly tack one lead first to hold the resistor in place. (If you’re right-handed, it might be easier to hold the tweezers in your left hand and tack the resistor to U13 pin 20 in this step. If you prefer to hold the iron in your left hand then tack U13 pin 11 first.)
3. Next, solder the other resistor lead completely. (There’s no need to use the tweezers to hold the resistor in the step as the resistor is held in place by the action performed in step #2.)
4. Solder the first lead completely that was tacked in place in step #2.

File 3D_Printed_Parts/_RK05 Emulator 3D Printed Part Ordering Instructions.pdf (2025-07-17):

_RK05 Emulator 3D Printed Part Ordering Instructions v02.docx | page 1

RK05 Emulator 3D Printed Part Ordering Instructions:

The following brief descriptions are to provide guidance to choose the proper materials and options when ordering the 3D printed parts from JLC3DP.
- 3D file: 200_RK05_Lamp_Lens_v04.stl
3D Technology: SLA (Resin)
Material: LEDO 6060 Resin
Colors: Natural White
Notes: Dimensional accuracy of the Lamp Lens is important so that it fits perfectly into the corresponding square openings in the Dress Panel.
Ordering instructions:
o Click “Add 3D Files” and select the file: “200_RK05_Lamp_Lens_v04.stl”
o 3D Technology: click “SLA(Resin)”
o Material: click “LEDO 6060 Resin”
o Color: click “Natural White”
o Surface Finish: click “Yes”, select “Sanding”, select “General sanding” o Click “SAVE TO CART”
o Approximate per-part price: $0.66 plus tax & shipping
- 3D file: 201_RK05em_Bezel_v06.stl
3D Technology: FDM (Plastic)
Material: PLA
Colors: White
Notes: This part must be plastic so the threaded inserts can be melted into the mounting holes. Please refer to the secondary operations document for this part.
Ordering instructions:
o Click “Add 3D Files” and select the file: “201_RK05em_Bezel_v06.stl”
o 3D Technology: click “FDM(Plastic)”
o Material: click “PLA”
o Color: click “White”
o Click “SAVE TO CART”
o Approximate per-part price: $3.14 plus tax & shipping
- 3D file: 202_RK05em_connector_filler_v05.stl
3D Technology: SLA (Resin)
Material: LEDO 6060 Resin
Colors: Natural White
Ordering instructions:
o Click “Add 3D Files” and select the file: “202_RK05em_connector_filler_v05.stl” o 3D Technology: click “SLA(Resin)”
o Material: click “LEDO 6060 Resin”
o Color: click “Natural White”
o Surface Finish: click “Yes”, select “Sanding”, select “General sanding” o Click “SAVE TO CART”
o Approximate per-part price: $0.30 plus tax & shipping

_RK05 Emulator 3D Printed Part Ordering Instructions v02.docx | page 2
- 3D file: 204_sd_card_carrier_v21.stl 3D Technology: FDM (Plastic)
Material: PLA
Colors: Black
Notes: This part must be plastic so the threaded inserts can be melted into the mounting holes. Please refer to the secondary operations document for this part. The vertical section of this part with two holes for M3 mounting screws is as long as it is so the minimum dimension requirements for PLA printing at JLC3DP can be met.
Ordering instructions:
o Click “Add 3D Files” and select the file: “204_sd_card_carrier_v21.stl”
o 3D Technology: click “FDM(Plastic)”
o Material: click “PLA”
o Color: click “Black”
o Click “SAVE TO CART”
o Approximate per-part price: $1.00 plus tax & shipping
- 3D file: 205_M993_Cable_Clamp_v04.stl
3D Technology: SLA (Resin)
Material: LEDO 6060 Resin
Colors: Natural White
Ordering instructions:
o Click “Add 3D Files” and select the file: “205_M993_Cable_Clamp_v04.stl” o 3D Technology: click “SLA(Resin)”
o Material: click “LEDO 6060 Resin”
o Color: click “Natural White”
o Surface Finish: click “Yes”, select “Sanding”, select “General sanding” o Click “SAVE TO CART”
o Approximate per-part price: $0.30 plus tax & shipping
- 3D file: 207_Light_Shield1_v03.stl
3D Technology: SLS (Nylon)
Material: 3201PA-F Nylon
Colors: Natural White
Notes: alternatively, this part can be printed in SLA(Resin), LEDO 6060 Resin, Natural White and then painted. The cost of SLA (Resin) is $0.30 per part compared to SLS (Nylon) which is $1.00 per part.
Ordering instructions:
o Click “Add 3D Files” and select the file: “207_Light_Shield1_v03.stl”
o 3D Technology: click “SLS (Nylon)”
o Material: click “3201PA-F Nylon”
o Color: click “Black”
o Click “SAVE TO CART”
o Approximate per-part price: $1.00 plus tax & shipping

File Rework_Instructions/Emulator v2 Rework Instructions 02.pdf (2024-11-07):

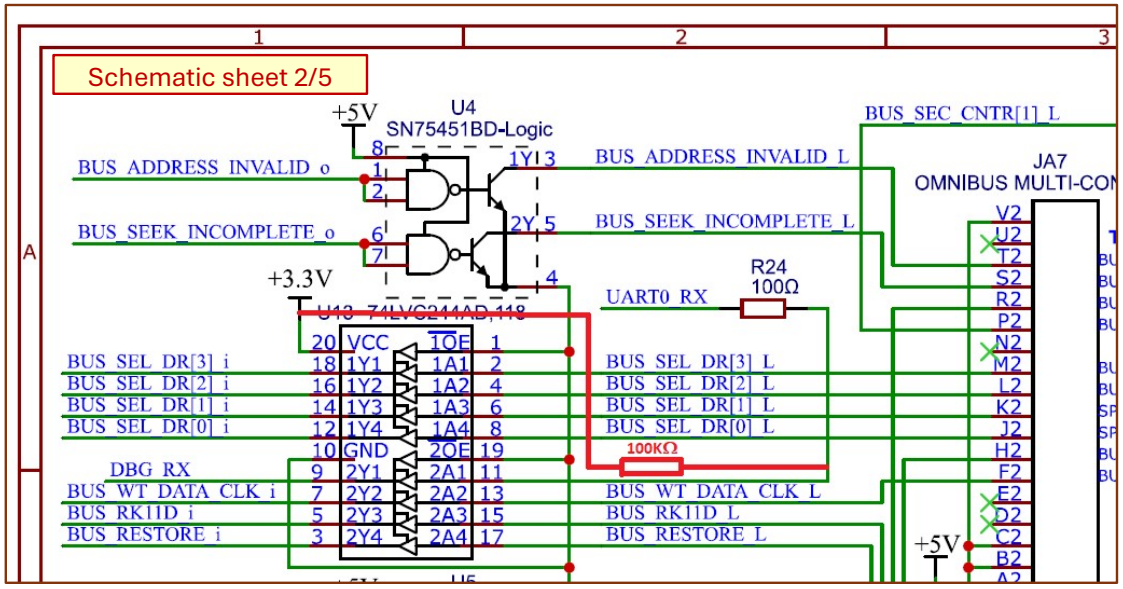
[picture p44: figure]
Schematic sheet 2/5

6-November-2024 | Emulator v2 Rework Instructions 02.docx | page 1

Rework to fix an intermittent boot-up problem (for board serial numbers 11 through 40) An issue was just discovered that causes the Raspberry Pi Pico controller in the emulator to intermittently not boot up properly. The symptoms are when power is applied, some of the front panel lights are illuminated, the display is blank, and the emulator hasn’t booted up fully.
This is caused by coupling of signals onto the debug port serial input which is floating and not properly pulled to a known state when a USB serial cable is not connected to the debug port. The fix is to solder a 100K Ω pullup resistor between the on-board +3.3V supply and the 74LVC244 receiver input for the serial debug port.
The following instructions describe the procedure to attach the resistor to a convenient place on the main board.
A 100K ohm resistor will be connected from U13-11 to U13-20 as shown in the schematic diagram.

There is a software improvement that prevents the system from locking up due to activity on the serial port input during the boot-up process. It’s not required but recommended to install Raspberry Pi software version 2.7 or higher in addition to the rework to add the pullup on the serial port input. Although the use of software version 2.7 or higher will allow the system to boot properly without performing the rework, the rework is highly recommended because it prevents random characters from appearing on the serial port input during normal operation when a USB serial cable is not attached. The emulator responds to certain one-character commands during normal operation to enable debug logging modes. Inadvertent random characters on the serial input could cause the emulator to enter a logging mode which might change its operating behavior. Adding the pullup prevents this issue from happening.
Recommendation: perform the rework and use software version 2.7 or higher. Main board serial numbers 0041 or higher already have the pullup on the serial port.

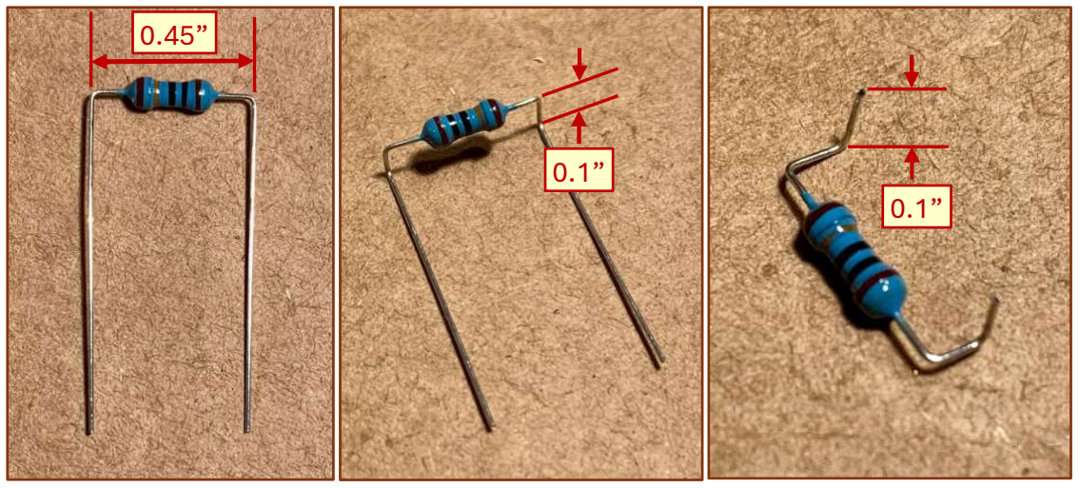
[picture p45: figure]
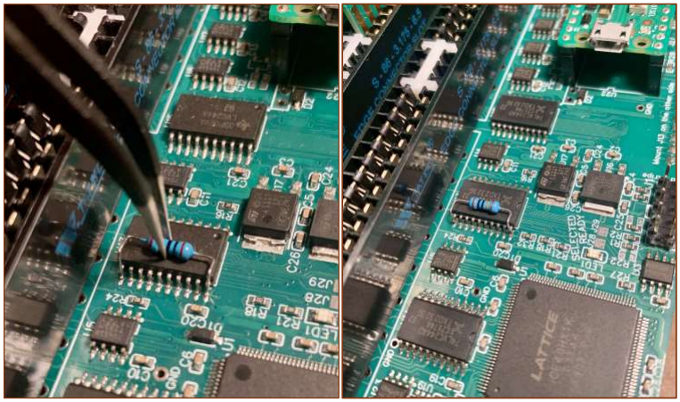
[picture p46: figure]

6-November-2024 | Emulator v2 Rework Instructions 02.docx | page 2

Bend the leads of a 100K Ω resistor so that the bent wires are 0.45” apart. Then bend each lead once more and cut, as shown below.

In the following steps we will solder one lead of the resistor to U13 pin 11 and the other to U13 pin
20. For lead-free solder, Sn / Ag / Cu: 99% / 0.3% / 0.7%, use a small pointed soldering tip and set the temperature to about 350°C.
1. Place the 100K Ω resistor, with leads bent, on top of U13.
2. Hold the resistor in-place with tweezers. With a little melted solder on the iron tip, lightly tack one lead first to hold the resistor in place. (If you’re right-handed, it might be easier to hold the tweezers in your left hand and tack the resistor to U13 pin 20 in this step. If you prefer to hold the iron in your left hand then tack U13 pin 11 first.)
3. Next, solder the other resistor lead completely. (There’s no need to use the tweezers to hold the resistor in the step as the resistor is held in place by the action performed in step #2.)
4. Solder the first lead completely that was tacked in place in step #2.

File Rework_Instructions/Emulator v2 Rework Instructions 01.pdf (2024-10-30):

Rework to fix an intermittent boot-up problem
An issue was just discovered that causes the Raspberry Pi Pico controller in the emulator to intermittently not boot up properly. The symptoms are when power is applied, some of the front panel lights are illuminated, the display is blank, and the emulator hasn’t booted up fully.
This is caused by coupling of signals onto the debug port serial input which is floating and not properly pulled to a known state when a USB serial cable is not connected to the debug port. The fix is to solder a 100K Ω pullup resistor between the on-board +3.3V supply and the 74LVC244 receiver input for the serial debug port.
The following instructions describe the procedure to attach the resistor to a convenient place on the main board.
A 100K ohm resistor will be connected from U13-11 to U13-20 as shown in the schematic diagram.

Schematic sheet 2/5

Bend the leads of a 100K Ω resistor so that the bent wires are 0.45” apart. Then bend each lead once more and cut, as shown below.

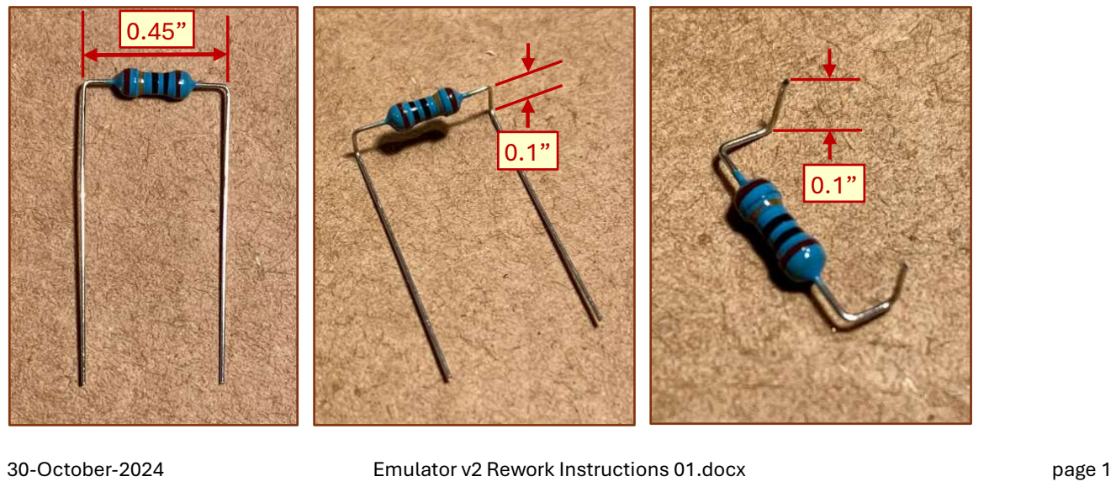
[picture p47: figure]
30-October-2024; Emulator v2 Rework Instructions 01.docx; page 1

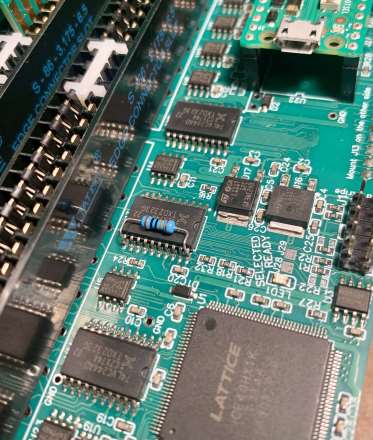
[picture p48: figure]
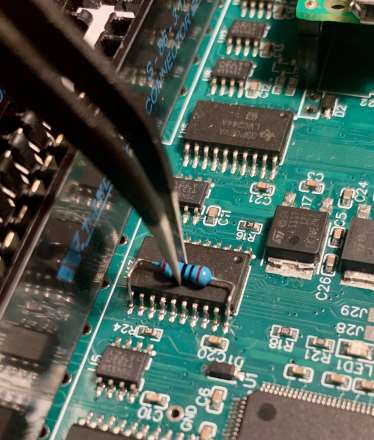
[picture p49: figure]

30-October-2024 | Emulator v2 Rework Instructions 01.docx | page 2

In the following steps we will solder one lead of the resistor to U13 pin 11 and the other to U13 pin
20. For lead-free solder, Sn / Ag / Cu: 99% / 0.3% / 0.7%, use a small pointed soldering tip and set the temperature to about 350°C.
1. Place the 100K Ω resistor, with leads bent, on top of U13.
2. Hold the resistor in-place with tweezers. With a little melted solder on the iron tip, lightly tack one lead first to hold the resistor in place. (If you’re right-handed, it might be easier to hold the tweezers in your left hand and tack the resistor to U13 pin 20 in this step. If you prefer to hold the iron in your left hand then tack U13 pin 11 first.)
3. Next, solder the other resistor lead completely. (There’s no need to use the tweezers to hold the resistor in the step as the resistor is held in place by the action performed in step #2.)
4. Solder the first lead completely that was tacked in place in step #2.

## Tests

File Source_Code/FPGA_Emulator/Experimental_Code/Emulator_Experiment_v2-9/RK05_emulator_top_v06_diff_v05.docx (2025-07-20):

//==========================================================================================================

// RK05 Emulator

// Top Level definition

// File Name: RK05_emulator_top_v06.v

// Version 2.9

//==========================================================================================================

//

//===============================================================================================//

// //

// This FPGA firmware and related modules included by the top level module and files used to //

// build the software are provided on an as-is basis. No warrantees or guarantees are provided //

// or implied. Users of the RK05 Emulator or RK05 Tester shall not hold the developers of this //

// software, firmware, hardware, or related documentation liable for any damages caused by //

// any type of malfunction of the product including malfunctions caused by defects in the design //

// or operation of the software, firmware, hardware or use of related documentation or any //

// combination thereof. //

// //

//===============================================================================================//

//

`include "bus_disk_read.v"

`include "bus_disk_write.v"

`include "bus_outputs.v"

`include "clock_and_reset.v"

`include "drive_select.v"

`include "sdram_controller.v"

`include "sector_and_index.v"

`include "seek_to_cylinder.v"

`include "spi_interface.v"

`include "timing_gen.v"

//================================= TOP LEVEL INPUT-OUTPUT DEFINITIONS =====================================

module RK05_emulator_top (

// BUS Connector Inputs, 20 signals

input wire BUS_RK11D_L, // RK11 mode for Drive Select BUS_RK11D_L

input wire [3:0] BUS_SEL_DR_L, // Drive Select signals

input wire [7:0] BUS_CYL_ADD_L, // Cylinder Address

input wire BUS_STROBE_L, // Strobe to enable movement, gates the Cylinder Address or Restore line

input wire BUS_HEAD_SELECT_L, // Head Select

input wire BUS_WT_PROTECT_L, // Write Protect

input wire BUS_WT_DATA_CLK_L, // Composite write data and write clock

input wire BUS_WT_GATE_L, // Write gate, when active enables write circuitry

input wire BUS_RESTORE_L, // Restore, moves heads to cylinder 0

input wire BUS_RD_GATE_L, // Read gate, when active enables read circuitry

// BUS Connector Outputs, 17 signals

output wire BUS_FILE_READY_L, // data copied from microSD to SDRAM, drive is ready

output wire BUS_RWS_RDY_L, // Read, Write or Seek ready and on-cylinder

output wire BUS_ADDRESS_ACCEPTED_L, // Address accepted. 5 usec pulse indicates that the drive accepted a Seek command

output wire BUS_ADDRESS_INVALID_L, // Address invalid. 5 usec pulse indicates that the drive received a nonexecutable Seek command, alternative ATTEN mode function is ATTEN4

output wire BUS_SEEK_INCOMPLETE_L, // Seek Incomplete, indicates some malfunction, connected but not currently used

output wire BUS_WT_PROT_STATUS_L, // Write Protect status

output wire BUS_WT_CHK_L, // Write Check, indicates a write malfunction, connected but not currently used

output wire BUS_RD_DATA_L, // Read data pulses, 160 ns pulse

output wire BUS_RD_CLK_L, // Read clock pulses, 160 ns pulse

output wire [4:0] BUS_SEC_CNTR_L, // Sector Counter, sector counter bit 4 is pin 73 when not using Servo_Pulse_FPGA_pin

output wire BUS_SEC_PLS_L, // 2 us negative pulse each time a sector slot passes the transducer

output wire BUS_INDX_PLS_L, // 2 us negative pulse for each revolution of the disk, 600 usec after the sector pulse

output wire BUS_DC_LO_L, // DC low indicator, not used for the emulator, connected but not currently used

output wire BUS_RK05_HIGH_DENSITY_L, // All RK05's are high density, alternative ATTEN mode function is ATTEN2

// SDRAM I/O. 39 signals. 16 - DQ, 13 - Address: A0-A12, 2 - Addr Select: BS0 BS1, 8 - SDRAM Control: WE# CAS# RAS# CS# CLK CKE DQML DQMH

//input [15:0] SDRAM_DQ_in, // input from DQ signal receivers

//output [15:0] SDRAM_DQ_output, // outputs to DQ signal drivers

//output SDRAM_DQ_enable, // DQ output enable, active high

output wire [12:0] SDRAM_Address,// SDRAM Address

output wire SDRAM_BS0, // SDRAM Bank Select 0

output wire SDRAM_BS1, // SDRAM Bank Select 1

output wire SDRAM_WE_n, // SDRAM Write

output wire SDRAM_CAS_n, // SDRAM Column Address Select

output wire SDRAM_RAS_n, // SDRAM Row Address Select

output wire SDRAM_CS_n, // SDRAM Chip Select

output wire SDRAM_CLK, // SDRAM Clock

output wire SDRAM_CKE, // SDRAM Clock Enable

output wire SDRAM_DQML, // SDRAM DQ Mask for Lower Byte

output wire SDRAM_DQMH, // SDRAM DQ Mask for Upper (High) Byte

inout wire [15:0] SDRAM_DQ, //SDRAM multiplexed Data Input & Output

// ESP32 CPU SPI Port 6 signals: MISO MOSI CLK CS 2-bit-register-select

output wire CPU_SPI_MISO, // SPI Controller Input Peripheral Output

input wire CPU_SPI_MOSI, // SPI Controller Output Peripheral Input

input wire CPU_SPI_CLK, // SPI Controller Clock

input wire CPU_SPI_CS_n, // SPI Controller Chip Select, active low

// Front Panel from FPGA, 4 signals. WT_PROT_indicator WT_indicator RD_indicator ON_CYL_indicator

output wire FPANEL_WT_PROT_indicator, // Write Protect indicator

output wire FPANEL_WT_indicator, // Write indicator

output wire FPANEL_RD_indicator, // Read indicator

output wire FPANEL_ON_CYL_indicator, // On Cylinder indicator

// Clock and Reset external pins: pin_clock pin_reset

input wire clock,

input wire pin_reset_n,

// Tester Outputs, new in Emulator v1 hardware

output wire TESTER_OUTPUT_1_L, // this is pin 87

output wire TESTER_OUTPUT_2_L, // this is pin 44

, alternative ATTEN mode function is ATTEN1

output wire TESTER_OUTPUT_3_L, // this is pin 45, alternative ATTEN mode function is ATTEN3

output wire Servo_Pulse_FPGA_pin, // this is pin 73 when not using sector counter bit 4

input wire SPARE_PIO1_24, // this is pin 74, the spare input used in interface test mode to monitor the sector counter bit 4 output on bus pin AV1 driven by the tester

output wire SELECTED_RDY_LED_N, // this is pin 75

output wire CMD_INTERRUPT // this is pin 76

);

// ATTEN Mode summary:

// TESTER_OUTPUT_2_L, FPGA pin 44, alternative ATTEN mode function is ATTEN1

// BUS_RK05_HIGH_DENSITY_L, alternative ATTEN mode function is ATTEN2

// TESTER_OUTPUT_3_L, FPGA pin 45, alternative ATTEN mode function is ATTEN3

// BUS_ADDRESS_INVALID_L, alternative ATTEN mode function is ATTEN4

//============================ Internal Connections ==================================

wire [7:0] MAJOR_VERSION;

assign MAJOR_VERSION = 2;

wire [7:0] MINOR_VERSION;

assign MINOR_VERSION = 9;

wire reset;

wire [7:0] test_reg_1;

wire [7:0] test_reg_2;

wire [11:0] test_reg_3;

//wire [4:0] number_of_sectors;

wire [4:0] number_of_sectors_minus_1;

wire [7:0] bitclockdivider_clockphase;

wire [7:0] bitclockdivider_dataphase;

wire [7:0] bitpulse_width;

wire [15:0] microseconds_per_sector;

wire cpu_dc_low;

wire atten_mode_enable;

wire clkenbl_sector;

wire clkenbl_index;

wire bus_sector_pulse;

wire bus_index_pulse;

wire File_Ready;

wire Write_Protect;

wire Fault_Latch;

wire [2:0] Drive_Address;

wire Selected_Ready;

wire [7:0] Cylinder_Address;

wire Head_Select;

wire [4:0] Sector_Address;

wire [4:0] Sector_Address_Safe;

wire oncylinder_indicator;

wire write_indicator;

wire read_indicator;

wire BUS_RD_DATA_H;

wire BUS_RD_CLK_H;

wire load_address_spi;

wire load_address_busread;

wire load_address_buswrite;

wire dram_read_enbl_spi;

wire dram_read_enbl_busread;

wire dram_addr_incr_buswrite;

wire dram_write_enbl_spi;

wire dram_write_enbl_buswrite;

wire dram_readack;

wire dram_writeack;

wire [7:0] spi_serpar_reg;

wire [15:0] dram_readdata;

wire [15:0] dram_writedata_spi;

wire [15:0] dram_writedata_buswrite;

wire [15:0] SDRAM_DQ_in;

wire [15:0] SDRAM_DQ_output;

wire SDRAM_DQ_enable;

wire clkenbl_read_bit;

wire clkenbl_read_data;

wire clock_pulse;

wire data_pulse;

wire clkenbl_1usec;

wire [7:0] sdram_debug;

wire [7:0] bdw_test;

wire interface_test_mode;

wire strobe_selected_ready;

wire read_selected_ready;

wire write_selected_ready;

wire Servo_Pulse_FPGA;

//reg [7:0] test_counter;

//wire [2:0] bdw_state_output; // for debugging for visibility of the bus write state

//============================ MISC TOP LEVEL LOGIC TO DRIVE THE INDICATORS ==================================

assign FPANEL_WT_PROT_indicator = interface_test_mode ? ~test_reg_3[3] : ~Write_Protect;

assign FPANEL_WT_indicator = interface_test_mode ? ~test_reg_3[1] : ~write_indicator;

assign FPANEL_RD_indicator = interface_test_mode ? ~test_reg_3[0] : ~read_indicator;

assign FPANEL_ON_CYL_indicator = interface_test_mode ? ~test_reg_3[5] : ~(oncylinder_indicator & File_Ready);

//assign FPANEL_WT_indicator = ~(~BUS_WT_GATE_L & Selected_Ready);

//assign FPANEL_RD_indicator = ~(~BUS_RD_GATE_L & Selected_Ready);

//assign SPARE_PIO1_24 = sdram_debug[0];

//assign SPARE_PIO1_24 = bdw_test[6];

//assign SPARE_PIO1_24 = 1'b0;

assign SELECTED_RDY_LED_N = ~Selected_Ready;

assign TESTER_OUTPUT_1_L = interface_test_mode ? ~test_reg_3[8] : ~1'b0; // this is pin 87

//assign TESTER_OUTPUT_2_L = interface_test_mode ? ~test_reg_3[9] : ~(atten_mode_enable & ~Drive_Address[2] & ~Drive_Address[1] & ~Drive_Address[0] & ~BUS_RWS_RDY_H); // this is pin 44

assign TESTER_OUTPUT_2_L = interface_test_mode ? ~test_reg_3[9] : ~(~Drive_Address[2] & ~Drive_Address[1] & ~Drive_Address[0] & ~BUS_RWS_RDY_H); // this is pin 44

// Don't qualify the ATTEN output with Selected_Ready because the setting of the on_cyl_counter in seek_to_cylinder.v is already qualified by Selected_Ready.

// We want the ATTEN to remain active in case the controller selects another drive immediately following a seek command (by activating Strobe)

// There are already individual outputs of ATTENx for each drive so they don't need to be qualified by the BUS_SEL_DR_L address from the disk bus

// Instead, use Drive_Address (the address selected by the dipswitches) to route the signal to the proper ATTENx output

assign TESTER_OUTPUT_3_L = interface_test_mode ? ~test_reg_3[10] : ~1'b0; // this is pin 45

//assign TESTER_OUTPUT_1_L = sdram_debug[1]; // this is pin 87

//assign TESTER_OUTPUT_2_L = sdram_debug[2]; // this is pin 44

//assign TESTER_OUTPUT_3_L = sdram_debug[3]; // this is pin 45

//assign Servo_Pulse_FPGA_pin = bdw_test[7];

//assign Servo_Pulse_FPGA_pin = Servo_Pulse_FPGA;

//assign Servo_Pulse_FPGA_pin = ~Selected_Ready;

//assign TESTER_OUTPUT_1 = test_counter[0]; // this is pin 87

//assign TESTER_OUTPUT_2 = test_counter[1]; // this is pin 44

//assign TESTER_OUTPUT_3 = test_counter[2]; // this is pin 45

//assign Servo_Pulse_FPGA_pin = test_counter[3]; // this is pin 73

//assign SPARE_PIO1_24 = test_counter[4]; // this is pin 74

//assign SELECTED_RDY_LED_N = test_counter[5]; // this is pin 75

//assign CMD_INTERRUPTX = test_counter[6]; // this is pin 76

//always @ (posedge clock)

//begin : PINTESTLOOP // block name

//if(reset==1'b1) begin

//test_counter <= 8'd0;

//end

//else begin

//test_counter <= test_counter + 1;

//end

//end

//============================ SDRAM Bidirectional I/O pins ==================================

SB_IO DQ00

(

.PACKAGE_PIN (SDRAM_DQ[0]), // User's Pin signal name

.OUTPUT_ENABLE (SDRAM_DQ_enable), // Output Pin Tristate/Enable control

.D_OUT_0 (SDRAM_DQ_output[0]), // Data 0 - out to Pin

.D_IN_0 (SDRAM_DQ_in[0]), // Data 0 - Pin input

// n.c. pins we don't use

.LATCH_INPUT_VALUE (), .CLOCK_ENABLE (), .INPUT_CLK (), .OUTPUT_CLK (), .D_OUT_1 (), .D_IN_1 ()

);

defparam DQ00.PIN_TYPE = 6'b101001; // non-latched bi-directional I/O buffer

defparam DQ00.PULLUP = 1'b0;

// By default, the IO will have NO pull up.

// This parameter is used only on bank 0, 1, and 2. Ignored when it is placed at bank 3

defparam DQ00.NEG_TRIGGER = 1'b0;

// Specify the polarity of all FFs in the IO to be falling edge when NEG_TRIGGER = 1.

// Default is rising edge.

//defparam DQ00.IO_STANDARD = "LVCMOS";

// Other IO standards are supported in bank 3 only: SB_SSTL2_CLASS_2, SB_SSTL2_CLASS_1,

// SB_SSTL18_FULL, SB_SSTL18_HALF, SB_MDDR10,SB_MDDR8, SB_MDDR4, SB_MDDR2 etc.

SB_IO DQ01

(

.PACKAGE_PIN (SDRAM_DQ[1]),

.OUTPUT_ENABLE (SDRAM_DQ_enable),

.D_OUT_0 (SDRAM_DQ_output[1]),

.D_IN_0 (SDRAM_DQ_in[1]),

.LATCH_INPUT_VALUE (), .CLOCK_ENABLE (), .INPUT_CLK (), .OUTPUT_CLK (), .D_OUT_1 (), .D_IN_1 ()

);

defparam DQ01.PIN_TYPE = 6'b101001; // non-latched bi-directional I/O buffer

defparam DQ01.PULLUP = 1'b0;

defparam DQ01.NEG_TRIGGER = 1'b0;

//defparam DQ01.IO_STANDARD = "LVCMOS";

SB_IO DQ02

(

.PACKAGE_PIN (SDRAM_DQ[2]),

.OUTPUT_ENABLE (SDRAM_DQ_enable),

.D_OUT_0 (SDRAM_DQ_output[2]),

.D_IN_0 (SDRAM_DQ_in[2]),

// n.c. pins we don't use

.LATCH_INPUT_VALUE (), .CLOCK_ENABLE (), .INPUT_CLK (), .OUTPUT_CLK (), .D_OUT_1 (), .D_IN_1 ()

);

defparam DQ02.PIN_TYPE = 6'b101001; // non-latched bi-directional I/O buffer

defparam DQ02.PULLUP = 1'b0;

defparam DQ02.NEG_TRIGGER = 1'b0;

//defparam DQ02.IO_STANDARD = "LVCMOS";

SB_IO DQ03

(

.PACKAGE_PIN (SDRAM_DQ[3]),

.OUTPUT_ENABLE (SDRAM_DQ_enable),

.D_OUT_0 (SDRAM_DQ_output[3]),

.D_IN_0 (SDRAM_DQ_in[3]),

// n.c. pins we don't use

.LATCH_INPUT_VALUE (), .CLOCK_ENABLE (), .INPUT_CLK (), .OUTPUT_CLK (), .D_OUT_1 (), .D_IN_1 ()

);

defparam DQ03.PIN_TYPE = 6'b101001; // non-latched bi-directional I/O buffer

defparam DQ03.PULLUP = 1'b0;

defparam DQ03.NEG_TRIGGER = 1'b0;

//defparam DQ03.IO_STANDARD = "LVCMOS";

SB_IO DQ04

(

.PACKAGE_PIN (SDRAM_DQ[4]),

.OUTPUT_ENABLE (SDRAM_DQ_enable),

.D_OUT_0 (SDRAM_DQ_output[4]),

.D_IN_0 (SDRAM_DQ_in[4]),

// n.c. pins we don't use

.LATCH_INPUT_VALUE (), .CLOCK_ENABLE (), .INPUT_CLK (), .OUTPUT_CLK (), .D_OUT_1 (), .D_IN_1 ()

);

defparam DQ04.PIN_TYPE = 6'b101001; // non-latched bi-directional I/O buffer

defparam DQ04.PULLUP = 1'b0;

defparam DQ04.NEG_TRIGGER = 1'b0;

//defparam DQ04.IO_STANDARD = "LVCMOS";

SB_IO DQ05

(

.PACKAGE_PIN (SDRAM_DQ[5]),

.OUTPUT_ENABLE (SDRAM_DQ_enable),

.D_OUT_0 (SDRAM_DQ_output[5]),

.D_IN_0 (SDRAM_DQ_in[5]),

// n.c. pins we don't use

.LATCH_INPUT_VALUE (), .CLOCK_ENABLE (), .INPUT_CLK (), .OUTPUT_CLK (), .D_OUT_1 (), .D_IN_1 ()

);

defparam DQ05.PIN_TYPE = 6'b101001; // non-latched bi-directional I/O buffer

defparam DQ05.PULLUP = 1'b0;

defparam DQ05.NEG_TRIGGER = 1'b0;

//defparam DQ05.IO_STANDARD = "LVCMOS";

SB_IO DQ06

(

.PACKAGE_PIN (SDRAM_DQ[6]),

.OUTPUT_ENABLE (SDRAM_DQ_enable),

.D_OUT_0 (SDRAM_DQ_output[6]),

.D_IN_0 (SDRAM_DQ_in[6]),

// n.c. pins we don't use

.LATCH_INPUT_VALUE (), .CLOCK_ENABLE (), .INPUT_CLK (), .OUTPUT_CLK (), .D_OUT_1 (), .D_IN_1 ()

);

defparam DQ06.PIN_TYPE = 6'b101001; // non-latched bi-directional I/O buffer

defparam DQ06.PULLUP = 1'b0;

defparam DQ06.NEG_TRIGGER = 1'b0;

//defparam DQ06.IO_STANDARD = "LVCMOS";

SB_IO DQ07

(

.PACKAGE_PIN (SDRAM_DQ[7]),

.OUTPUT_ENABLE (SDRAM_DQ_enable),

.D_OUT_0 (SDRAM_DQ_output[7]),

.D_IN_0 (SDRAM_DQ_in[7]),

// n.c. pins we don't use

.LATCH_INPUT_VALUE (), .CLOCK_ENABLE (), .INPUT_CLK (), .OUTPUT_CLK (), .D_OUT_1 (), .D_IN_1 ()

);

defparam DQ07.PIN_TYPE = 6'b101001; // non-latched bi-directional I/O buffer

defparam DQ07.PULLUP = 1'b0;

defparam DQ07.NEG_TRIGGER = 1'b0;

//defparam DQ07.IO_STANDARD = "LVCMOS";

SB_IO DQ08

(

.PACKAGE_PIN (SDRAM_DQ[8]),

.OUTPUT_ENABLE (SDRAM_DQ_enable),

.D_OUT_0 (SDRAM_DQ_output[8]),

.D_IN_0 (SDRAM_DQ_in[8]),

// n.c. pins we don't use

.LATCH_INPUT_VALUE (), .CLOCK_ENABLE (), .INPUT_CLK (), .OUTPUT_CLK (), .D_OUT_1 (), .D_IN_1 ()

);

defparam DQ08.PIN_TYPE = 6'b101001; // non-latched bi-directional I/O buffer

defparam DQ08.PULLUP = 1'b0;

defparam DQ08.NEG_TRIGGER = 1'b0;

//defparam DQ08.IO_STANDARD = "LVCMOS";

SB_IO DQ09

(

.PACKAGE_PIN (SDRAM_DQ[9]),

.OUTPUT_ENABLE (SDRAM_DQ_enable),

.D_OUT_0 (SDRAM_DQ_output[9]),

.D_IN_0 (SDRAM_DQ_in[9]),

// n.c. pins we don't use

.LATCH_INPUT_VALUE (), .CLOCK_ENABLE (), .INPUT_CLK (), .OUTPUT_CLK (), .D_OUT_1 (), .D_IN_1 ()

);

defparam DQ09.PIN_TYPE = 6'b101001; // non-latched bi-directional I/O buffer

defparam DQ09.PULLUP = 1'b0;

defparam DQ09.NEG_TRIGGER = 1'b0;

//defparam DQ09.IO_STANDARD = "LVCMOS";

SB_IO DQ10

(

.PACKAGE_PIN (SDRAM_DQ[10]),

.OUTPUT_ENABLE (SDRAM_DQ_enable),

.D_OUT_0 (SDRAM_DQ_output[10]),

.D_IN_0 (SDRAM_DQ_in[10]),

// n.c. pins we don't use

.LATCH_INPUT_VALUE (), .CLOCK_ENABLE (), .INPUT_CLK (), .OUTPUT_CLK (), .D_OUT_1 (), .D_IN_1 ()

);

defparam DQ10.PIN_TYPE = 6'b101001; // non-latched bi-directional I/O buffer

defparam DQ10.PULLUP = 1'b0;

defparam DQ10.NEG_TRIGGER = 1'b0;

//defparam DQ10.IO_STANDARD = "LVCMOS";

SB_IO DQ11

(

.PACKAGE_PIN (SDRAM_DQ[11]),

.OUTPUT_ENABLE (SDRAM_DQ_enable),

.D_OUT_0 (SDRAM_DQ_output[11]),

.D_IN_0 (SDRAM_DQ_in[11]),

// n.c. pins we don't use

.LATCH_INPUT_VALUE (), .CLOCK_ENABLE (), .INPUT_CLK (), .OUTPUT_CLK (), .D_OUT_1 (), .D_IN_1 ()

);

defparam DQ11.PIN_TYPE = 6'b101001; // non-latched bi-directional I/O buffer

defparam DQ11.PULLUP = 1'b0;

defparam DQ11.NEG_TRIGGER = 1'b0;

//defparam DQ11.IO_STANDARD = "LVCMOS";

SB_IO DQ12

(

.PACKAGE_PIN (SDRAM_DQ[12]),

.OUTPUT_ENABLE (SDRAM_DQ_enable),

.D_OUT_0 (SDRAM_DQ_output[12]),

.D_IN_0 (SDRAM_DQ_in[12]),

// n.c. pins we don't use

.LATCH_INPUT_VALUE (), .CLOCK_ENABLE (), .INPUT_CLK (), .OUTPUT_CLK (), .D_OUT_1 (), .D_IN_1 ()

);

defparam DQ12.PIN_TYPE = 6'b101001; // non-latched bi-directional I/O buffer

defparam DQ12.PULLUP = 1'b0;

defparam DQ12.NEG_TRIGGER = 1'b0;

//defparam DQ12.IO_STANDARD = "LVCMOS";

SB_IO DQ13

(

.PACKAGE_PIN (SDRAM_DQ[13]),

.OUTPUT_ENABLE (SDRAM_DQ_enable),

.D_OUT_0 (SDRAM_DQ_output[13]),

.D_IN_0 (SDRAM_DQ_in[13]),

// n.c. pins we don't use

.LATCH_INPUT_VALUE (), .CLOCK_ENABLE (), .INPUT_CLK (), .OUTPUT_CLK (), .D_OUT_1 (), .D_IN_1 ()

);

defparam DQ13.PIN_TYPE = 6'b101001; // non-latched bi-directional I/O buffer

defparam DQ13.PULLUP = 1'b0;

defparam DQ13.NEG_TRIGGER = 1'b0;

//defparam DQ13.IO_STANDARD = "LVCMOS";

SB_IO DQ14

(

.PACKAGE_PIN (SDRAM_DQ[14]),

.OUTPUT_ENABLE (SDRAM_DQ_enable),

.D_OUT_0 (SDRAM_DQ_output[14]),

.D_IN_0 (SDRAM_DQ_in[14]),

// n.c. pins we don't use

.LATCH_INPUT_VALUE (), .CLOCK_ENABLE (), .INPUT_CLK (), .OUTPUT_CLK (), .D_OUT_1 (), .D_IN_1 ()

);

defparam DQ14.PIN_TYPE = 6'b101001; // non-latched bi-directional I/O buffer

defparam DQ14.PULLUP = 1'b0;

defparam DQ14.NEG_TRIGGER = 1'b0;

//defparam DQ14.IO_STANDARD = "LVCMOS";

SB_IO DQ15

(

.PACKAGE_PIN (SDRAM_DQ[15]),

.OUTPUT_ENABLE (SDRAM_DQ_enable),

.D_OUT_0 (SDRAM_DQ_output[15]),

.D_IN_0 (SDRAM_DQ_in[15]),

// n.c. pins we don't use

.LATCH_INPUT_VALUE (), .CLOCK_ENABLE (), .INPUT_CLK (), .OUTPUT_CLK (), .D_OUT_1 (), .D_IN_1 ()

);

defparam DQ15.PIN_TYPE = 6'b101001; // non-latched bi-directional I/O buffer

defparam DQ15.PULLUP = 1'b0;

defparam DQ15.NEG_TRIGGER = 1'b0;

//defparam DQ15.IO_STANDARD = "LVCMOS";

//================================= MODULES =====================================

// ======== Module ======== clock_and_reset =====

clock_and_reset i_clock_and_reset (

// Inputs

.clock (clock),

.pin_reset_n (pin_reset_n),

// Outputs

.reset (reset)

);

// ======== Module ======== bus_disk_read =====

bus_disk_read i_bus_disk_read (

// Inputs

.clock (clock),

.reset (reset),

.BUS_RD_GATE_L (BUS_RD_GATE_L),

.clkenbl_read_bit (clkenbl_read_bit),

.clkenbl_read_data (clkenbl_read_data),

.clock_pulse (clock_pulse),

.data_pulse (data_pulse),

.dram_readdata (dram_readdata),

.Selected_Ready (Selected_Ready),

.clkenbl_sector (clkenbl_sector),

.dram_readack (dram_readack),

// Outputs

.dram_read_enbl_busread (dram_read_enbl_busread),

.BUS_RD_DATA_H (BUS_RD_DATA_H),

.BUS_RD_CLK_H (BUS_RD_CLK_H),

.load_address_busread (load_address_busread),

.read_indicator (read_indicator),

.read_selected_ready (read_selected_ready)

);

// ======== Module ======== bus_disk_write =====

bus_disk_write i_bus_disk_write (

// Inputs

.clock (clock),

.reset (reset),

.BUS_WT_GATE_L (BUS_WT_GATE_L),

.BUS_WT_DATA_CLK_L (BUS_WT_DATA_CLK_L),

.Selected_Ready (Selected_Ready),

.clkenbl_sector (clkenbl_sector),

.clkenbl_read_data (clkenbl_read_data),

.dram_readack (dram_readack),

.dram_writeack (dram_writeack),

// Outputs

.dram_write_enbl_buswrite (dram_write_enbl_buswrite),

.dram_writedata_buswrite (dram_writedata_buswrite),

.load_address_buswrite (load_address_buswrite),

.dram_addr_incr_buswrite (dram_addr_incr_buswrite),

.write_indicator (write_indicator),

.bdw_debug (bdw_test),

.write_selected_ready (write_selected_ready)

//.bdw_state_output (bdw_state_output)

);

// ======== Module ======== bus_outputs =====

bus_outputs i_bus_outputs (

// Inputs

.Selected (Selected),

.File_Ready (File_Ready),

.Fault_Latch (Fault_Latch),

.BUS_RWS_RDY_H (BUS_RWS_RDY_H),

.BUS_ADDRESS_ACCEPTED_H (BUS_ADDRESS_ACCEPTED_H),

.BUS_ADDRESS_INVALID_H (BUS_ADDRESS_INVALID_H),

//.BUS_SEEK_INCOMPLETE_H (BUS_SEEK_INCOMPLETE_H),

.Write_Protect (Write_Protect),

.BUS_RD_DATA_H (BUS_RD_DATA_H),

.BUS_RD_CLK_H (BUS_RD_CLK_H),

.BUS_RD_GATE_L (BUS_RD_GATE_L),

.Sector_Address (Sector_Address),

.bus_sector_pulse (bus_sector_pulse),

.bus_index_pulse (bus_index_pulse),

.cpu_dc_low (cpu_dc_low),

//.cpu_dc_low (File_Ready), // for debugging to have visibility of File_Ready

//.cpu_dc_low (~SDRAM_DQ_output[0]), // for debugging SDRAM_DQ[0]

.interface_test_mode (interface_test_mode),

.test_reg_1 (test_reg_1),

.test_reg_2 (test_reg_2),

.test_reg_3 (test_reg_3),

// Outputs

.BUS_FILE_READY_L (BUS_FILE_READY_L),

.BUS_RWS_RDY_L (BUS_RWS_RDY_L),

.BUS_ADDRESS_ACCEPTED_L (BUS_ADDRESS_ACCEPTED_L),

.BUS_ADDRESS_INVALID_L (BUS_ADDRESS_INVALID_L),

.BUS_SEEK_INCOMPLETE_L (BUS_SEEK_INCOMPLETE_L),

.BUS_WT_PROT_STATUS_L (BUS_WT_PROT_STATUS_L),

.BUS_WT_CHK_L (BUS_WT_CHK_L),

.BUS_RD_DATA_L (BUS_RD_DATA_L),

.BUS_RD_CLK_L (BUS_RD_CLK_L),

.BUS_SEC_CNTR_L (BUS_SEC_CNTR_L),

.BUS_SEC_PLS_L (BUS_SEC_PLS_L),

.BUS_INDX_PLS_L (BUS_INDX_PLS_L),

//.BUS_AC_LO_L (BUS_AC_LO_L),

.BUS_DC_LO_L (BUS_DC_LO_L),

.BUS_RK05_HIGH_DENSITY_L (BUS_RK05_HIGH_DENSITY_L),

.Selected_Ready (Selected_Ready)

);

// ======== Module ======== drive_select =====

drive_select i_drive_select (

// Inputs

.BUS_RK11D_L (BUS_RK11D_L),

.BUS_SEL_DR_L (BUS_SEL_DR_L),

.Drive_Address (Drive_Address),

.RK05F_Mode (1'b0),

// Outputs

.Selected (Selected)

);

// ======== Module ======== sdram_controller =====

sdram_controller i_sdram_controller (

// Inputs

.clock (clock),

.reset (reset),

.load_address_spi (load_address_spi),

.load_address_busread (load_address_busread),

.load_address_buswrite (load_address_buswrite),

.dram_read_enbl_spi (dram_read_enbl_spi),

.dram_read_enbl_busread (dram_read_enbl_busread),

.dram_addr_incr_buswrite (dram_addr_incr_buswrite),

.dram_write_enbl_spi (dram_write_enbl_spi),

.dram_write_enbl_buswrite (dram_write_enbl_buswrite),

.dram_writedata_spi (dram_writedata_spi),

.dram_writedata_buswrite (dram_writedata_buswrite),

.Write_Protect (Write_Protect),

.spi_serpar_reg (spi_serpar_reg),

.Sector_Address_Safe (Sector_Address_Safe),

.Cylinder_Address (Cylinder_Address),

.Head_Select (Head_Select),

.number_of_sectors_minus_1 (number_of_sectors_minus_1),

.SDRAM_DQ_in (SDRAM_DQ_in),

// Outputs

.dram_readdata (dram_readdata),

.dram_readack (dram_readack),

.dram_writeack (dram_writeack),

.SDRAM_DQ_output (SDRAM_DQ_output),

.SDRAM_DQ_enable (SDRAM_DQ_enable),

.SDRAM_Address (SDRAM_Address),

.SDRAM_BS0 (SDRAM_BS0),

.SDRAM_BS1 (SDRAM_BS1),

.SDRAM_WE_n (SDRAM_WE_n),

.SDRAM_CAS_n (SDRAM_CAS_n),

.SDRAM_RAS_n (SDRAM_RAS_n),

.SDRAM_CS_n (SDRAM_CS_n),

.SDRAM_CLK (SDRAM_CLK),

.SDRAM_CKE (SDRAM_CKE),

.SDRAM_DQML (SDRAM_DQML),

.SDRAM_DQMH (SDRAM_DQMH),

.sdram_debug (sdram_debug)

);

// ======== Module ======== sector_and_index =====

sector_and_index i_sector_and_index (

// Inputs

.clock (clock),

.reset (reset),

.clkenbl_1usec (clkenbl_1usec),

.number_of_sectors_minus_1 (number_of_sectors_minus_1),
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

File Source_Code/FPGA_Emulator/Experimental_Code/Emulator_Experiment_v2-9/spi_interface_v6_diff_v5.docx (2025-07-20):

//==========================================================================================================

// RK05 Emulator

// Processor SPI Interface

// File Name: spi_interface.v

// Functions:

// read and write FPGA hardware control registers.

// read and write SDRAM data.

// write SDRAM address register for processor SDRAM accesses.

//

//==========================================================================================================

module spi_interface(

input wire clock, // master clock 40 MHz

input wire reset, // active high synchronous reset input

input wire spi_clk, // SPI clock

input wire spi_cs_n, // SPI active low chip select

input wire spi_mosi, // SPI controller data output, peripheral data input

input wire [15:0] dram_readdata, // 16-bit read data from DRAM controller

input wire dram_readack, // dram read acknowledge ==== maybe no longer needed?? ============

input wire dram_writeack, // dram read acknowledge

input wire BUS_WT_PROTECT_L, // write protect strobe from the bus

input wire [7:0] Cylinder_Address, // input to be able to read the Cylinder Address

input wire Head_Select, // input to be able to read the Head Select bit

input wire Selected_Ready, // input to be able to read Selected_Ready

input wire BUS_RK11D_L, // RK11 mode for Drive Select BUS_RK11D_L

input wire [3:0] BUS_SEL_DR_L, // Drive Select signals

input wire [7:0] BUS_CYL_ADD_L, // Cylinder Address

input wire BUS_STROBE_L, // Strobe to enable movement, gates the Cylinder Address or Restore line

input wire BUS_HEAD_SELECT_L, // Head Select

//BUS_WT_PROTECT_L, // Write Protect

input wire BUS_WT_DATA_CLK_L, // Composite write data and write clock

input wire BUS_WT_GATE_L, // Write gate, when active enables write circuitry

input wire BUS_RESTORE_L, // Restore, moves heads to cylinder 0

input wire BUS_RD_GATE_L, // Read gate, when active enables read circuitry

input wire [7:0] major_version,

input wire [7:0] minor_version,

input wire [4:0] Sector_Address, // Sector Address to be read test visibility mode

input wire strobe_selected_ready,

input wire read_selected_ready,

input wire write_selected_ready,

input wire clkenbl_1usec, // 1 usec clock enable input from the timing generator

input wire SPARE_PIO1_24,

output reg spi_miso, // SPI controller data input, peripheral data output

output reg load_address_spi, // enable from SPI to command the sdram controller to load address 8 bits at a time

output reg [7:0] spi_serpar_reg, // 8-bit serpar register used for writing to the sdram address register

output reg dram_read_enbl_spi, // read enable request to DRAM controller

output reg dram_write_enbl_spi, // write enable request to DRAM controller

output reg [15:0] dram_writedata_spi, // 16-bit write data to DRAM controller

output reg [2:0] Drive_Address, // 3-bits internal drive address

output reg File_Ready, // disk contents have been copied from the microSD to the SDRAM.

output reg Write_Protect, // CPU register that indicates the drive write protect status.

output reg Fault_Latch, // included for future support. Software will always write zero to Fault_Latch.

output reg cpu_dc_low, // DC low signal driven by a CPU register

output reg [7:0] test_reg_1,

output reg [7:0] test_reg_2,

output reg [11:0] test_reg_3,

//output reg [7:0] postamble_length,

output wire [4:0] number_of_sectors_minus_1,

output reg [7:0] bitclockdivider_clockphase,

output reg [7:0] bitclockdivider_dataphase,

output reg [7:0] bitpulse_width,

output reg [15:0] microseconds_per_sector,

output reg interface_test_mode,

output reg command_interrupt,

output reg Servo_Pulse_FPGA

,

output reg atten_mode_enable

);

//============================ Internal Connections ==================================

//`define EMULATOR_FPGA_CODE_VERSION 8'h51 // hex number that indicates the version of the FPGA code

reg [7:0] spiserialreg;

reg [3:0] metaspi;

reg [2:0] metawprot;

reg dramwrite_lowhigh;

reg dramread_lowhigh;

reg [4:0] spicount; // define as 5 bits instead of 4 to prevent the first bit from wrapping around at the end of transmitting the 16-bit data (8 addr + 8 data)

reg [7:0] serialaddress;

wire [7:0] muxed_read_data;

wire pre_spi_miso;

reg frdlyd;

reg toggle_wp;

reg [1:0] operation_id;

reg [4:0] number_of_sectors;

//reg [7:0] servo_pw;

//reg [10:0] counter_servo_20ms_period; // counts 1250 16-usec intervals for the 20 ms servo pulse period

//reg [3:0] counter_16usec;

wire spi_start;

//============================ Start of Code =========================================

// SB_DFFS - D Flip-Flop, Set is asynchronous to the clock.

SB_DFFS SPI_DFFS_inst (

.Q(spi_start), // Registered Output, "Q" output of the DFF

.C(~spi_clk), // rising-edge Clock, so with ~spi_clk as the input, Q changes on the falling edge of spi_clk

.D(1'b0), // Data, clocks in a zero on the falling edge of spi_clk

.S(spi_cs_n) // Asynchronous active-high Set, we perform async set of the DFF while spi_cs_n is inactive

);

//assign number_of_sectors_minus_1 = (number_of_sectors < 2) ? 1 : number_of_sectors - 1;

assign number_of_sectors_minus_1 = number_of_sectors - 1;

assign muxed_read_data = (serialaddress == 8'h81) ? Cylinder_Address[7:0] :

((serialaddress == 8'h82) ? {Sector_Address[3:0], operation_id[1:0], Selected_Ready, Head_Select} :

((serialaddress == 8'h83) ? {7'h00, Sector_Address[4]} :

//((serialaddress == 8'h84) ? 8'h00 :

//((serialaddress == 8'h85) ? 8'h00 :

((serialaddress == 8'h89) ? {1'b0, 7'h0} : // bit 7 == 0 identifies the FPGA as an emulator, bits 6:0 are presently unused

((serialaddress == 8'h90) ? major_version[7:0] :

((serialaddress == 8'h91) ? minor_version[7:0] :

((serialaddress == 8'h94) ? BUS_CYL_ADD_L[7:0] :

((serialaddress == 8'h95) ? {BUS_RD_GATE_L, BUS_RESTORE_L, BUS_WT_GATE_L, BUS_WT_DATA_CLK_L, BUS_WT_PROTECT_L, BUS_HEAD_SELECT_L, BUS_STROBE_L, BUS_RK11D_L} :

((serialaddress == 8'h96) ? {3'b000, SPARE_PIO1_24, BUS_SEL_DR_L[3:0]} :

((serialaddress == 8'ha0) ? {cpu_dc_low, 1'b0, Fault_Latch, File_Ready, 1'b0, Drive_Address[2:0]} : // read-back of register 0x0

//((serialaddress == 8'ha7) ? test_reg_1_length[7:0] :

//((serialaddress == 8'ha8) ? test_reg_2_length[7:0] :

//((serialaddress == 8'ha9) ? {4'h0, test_reg_3[11:8]} :

//((serialaddress == 8'haa) ? test_reg_3[7:0] :

//((serialaddress == 8'hab) ? postamble_length[7:0] :

((serialaddress == 8'hac) ? {3'b000, number_of_sectors[4:0]} : // commented out to reduce PLBs consumed so the design fits in the part

((serialaddress == 8'had) ? bitclockdivider_clockphase[7:0] :

((serialaddress == 8'hae) ? bitclockdivider_dataphase[7:0] :

((serialaddress == 8'haf) ? bitpulse_width[7:0] :

//((serialaddress == 8'hb0) ? microseconds_per_sector[15:8] :

// removed microseconds_per_sector in v2.9 to reduce PLBs consumed

//((serialaddress == 8'hb1) ? microseconds_per_sector[7:0] :

((serialaddress == 8'h88) ? (dramread_lowhigh ? dram_readdata[15:8] : dram_readdata[7:0]) : 8'b0))))))))))))));

// dram_readdata[15:0] always has the data ready that was read at the dram_address.

// The DRAM word read function is triggered after the odd byte is read.

// The next word is requested after reading the high byte from register 0x88.

assign pre_spi_miso = ((spicount == 5'd7) & muxed_read_data[7]) |

((spicount == 5'd8) & muxed_read_data[6]) |

((spicount == 5'd9) & muxed_read_data[5]) |

((spicount == 5'd10) & muxed_read_data[4]) |

((spicount == 5'd11) & muxed_read_data[3]) |

((spicount == 5'd12) & muxed_read_data[2]) |

((spicount == 5'd13) & muxed_read_data[1]) |

((spicount == 5'd14) & muxed_read_data[0]);

always @ (posedge spi_clk)

begin : SPICLKPOSFUNCTIONS // block name

// Reset the SPI bit counter using the DFF that is set when spi_cs_n is inactive

// The SPI bit counter is used by a mux to serialize the SPI read data.

spicount <= spi_start ? 5'd0 : spicount + 1;

serialaddress <= (spicount == 6) ? {spiserialreg[6:0], spi_mosi} : serialaddress;

if(spi_cs_n == 1'b0) begin

spiserialreg[7:0] <= {spiserialreg[6:0], spi_mosi};

end

else begin

spiserialreg[7:0] <= 8'hff;

end

end

always @ (negedge spi_clk)

begin : SPICLKNEGFUNCTIONS // block name

spi_miso <= pre_spi_miso;

end

always @ (posedge spi_cs_n)

begin : SPICSPOSFUNCTIONS // block name

spi_serpar_reg <= spiserialreg;

end

always @ (posedge clock)

begin : HSCLOCKFUNCTIONS // block name

if(reset == 1'b1) begin

dram_read_enbl_spi <= 1'b0;

dram_write_enbl_spi <= 1'b0;

Drive_Address <= 3'd0;

File_Ready <= 1'b0;

frdlyd <= 1'b0;

Write_Protect <= 1'b0;

Fault_Latch <= 1'b0;

load_address_spi <= 1'b0;

dramwrite_lowhigh <= 1'b0;

dramread_lowhigh <= 1'b0;

metaspi <= 4'b0000;

metawprot <= 3'b000;

cpu_dc_low <= 1'b0;

atten_mode_enable <= 1'b0;

toggle_wp <= 1'b0;

test_reg_1 <= 8'd0;

test_reg_2 <= 8'd0;

test_reg_3 <= 12'h0;

number_of_sectors[4:0] <= 5'd16; //default for RK8-E, 16 sectors or 0x10

bitclockdivider_clockphase <= 8'd14; //default for RK8-E, system clock divided by 14 for half a bit, clock phase

bitclockdivider_dataphase <= 8'd14; //default for RK8-E, system clock divided by 14 for half a bit, data phase

bitpulse_width <= 8'd6; //default for RK8-E, clock and data pulse width is 6 system clocks

microseconds_per_sector <= 16'd2500; //default for RK8-E, 2.5 msec per sector, 2.5 * 16 = 40 msec per revolution, 0x09c4

interface_test_mode <= 1'b0;

operation_id <= 2'b00;

command_interrupt <= 1'b0;

//servo_pw <= 8'd47; // 0.75 msec is 47, 16 usec intervals

//counter_servo_20ms_period <= 11'h0;

//counter_16usec <= 4'h0;

Servo_Pulse_FPGA <= 1'b0;

end

else begin

//counter_16usec <= clkenbl_1usec ? counter_16usec + 1 : counter_16usec;

//counter_servo_20ms_period <= (clkenbl_1usec & (counter_16usec == 15)) ?

//((counter_servo_20ms_period < 11'd1249) ? counter_servo_20ms_period + 1 : 11'd0) : counter_servo_20ms_period;

//Servo_Pulse_FPGA <= ({3'h0, servo_pw[7:0]} > counter_servo_20ms_period);

Servo_Pulse_FPGA <= 1'b0;

command_interrupt <= strobe_selected_ready || read_selected_ready || write_selected_ready;

operation_id <= strobe_selected_ready ? 2'h0 : (read_selected_ready ? 2'h1 : (write_selected_ready ? 2'h2 : operation_id));

frdlyd <= File_Ready;

metaspi[3:0] <= {metaspi[2:0], ~spi_cs_n};

metawprot[2:0] <= {metawprot[1:0], (~BUS_WT_PROTECT_L & Selected_Ready)};

//clear Write_Protect when there's a change in File_Ready

//Write_Protect <= metawprot[2] | // if metawp then set wp

//(~(File_Ready ^ frdlyd) & ~metawprot[2] & (serialaddress == 8'h04) & ~metaspi[2] & metaspi[3] & spi_serpar_reg[0] & ~Write_Protect) |

//(~(File_Ready ^ frdlyd) & ~metawprot[2] & ((serialaddress == 8'h04) | metaspi[2] | ~metaspi[3] | ~spi_serpar_reg[0]) & Write_Protect);

// Q <= (Q | Set) & ~Reset

// Set when metawprot[2] or (toggle_wp & ~Q)

// Reset when (toggle_wp & Q) or (File_Ready ^ frdlyd)

toggle_wp <= (serialaddress == 8'h04) & ~metaspi[2] & metaspi[3] & spi_serpar_reg[0]; //toggle_wp is separated only so the code is more readable

Write_Protect <= (Write_Protect | (metawprot[2] | (toggle_wp & ~Write_Protect))) & ~((toggle_wp & Write_Protect) | (File_Ready ^ frdlyd));

// register address 0x00

Drive_Address[2:0] <= ((serialaddress == 8'h00) && ~metaspi[2] && metaspi[3]) ? spi_serpar_reg[2:0] : Drive_Address[2:0];

File_Ready <= ((serialaddress == 8'h00) && ~metaspi[2] && metaspi[3]) ? spi_serpar_reg[4] : File_Ready;

Fault_Latch <= ((serialaddress == 8'h00) && ~metaspi[2] && metaspi[3]) ? spi_serpar_reg[5] : Fault_Latch;

atten_mode_enable <= ((serialaddress == 8'h00) && ~metaspi[2] && metaspi[3]) ? spi_serpar_reg[6] : atten_mode_enable;

cpu_dc_low <= ((serialaddress == 8'h00) && ~metaspi[2] && metaspi[3]) ? spi_serpar_reg[7] : cpu_dc_low;

// register address 0x05

load_address_spi <= (serialaddress == 8'h05) & ~metaspi[2] & metaspi[3]; // command to load 8 bits of address from SPI

// register address 0x06

dram_writedata_spi[7:0] <= ((serialaddress == 8'h06) && ~metaspi[2] && metaspi[3]) ? dram_writedata_spi[15:8] : dram_writedata_spi[7:0];

dram_writedata_spi[15:8] <= ((serialaddress == 8'h06) && ~metaspi[2] && metaspi[3]) ? spi_serpar_reg : dram_writedata_spi[15:8];

dram_write_enbl_spi <= (serialaddress == 8'h06) & ~metaspi[2] & metaspi[3] & dramwrite_lowhigh;

// register address 0x07

test_reg_1 <= ((serialaddress == 8'h07) && ~metaspi[2] && metaspi[3]) ? spi_serpar_reg[7:0] : test_reg_1;

// register address 0x08

test_reg_2 <= ((serialaddress == 8'h08) && ~metaspi[2] && metaspi[3]) ? spi_serpar_reg[7:0] : test_reg_2;

// register address 0x09

test_reg_3[11:8] <= ((serialaddress == 8'h09) && ~metaspi[2] && metaspi[3]) ? spi_serpar_reg[3:0] : test_reg_3[11:8];

// register address 0x0a

test_reg_3[7:0] <= ((serialaddress == 8'h0a) && ~metaspi[2] && metaspi[3]) ? spi_serpar_reg[7:0] : test_reg_3[7:0];

// register address 0x0b

//postamble_length <= ((serialaddress == 8'h0b) && ~metaspi[2] && metaspi[3]) ? spi_serpar_reg[7:0] : postamble_length;

// register address 0x0c

number_of_sectors <= ((serialaddress == 8'h0c) && ~metaspi[2] && metaspi[3]) ? spi_serpar_reg[4:0] : number_of_sectors;

// register address 0x0d

bitclockdivider_clockphase <= ((serialaddress == 8'h0d) && ~metaspi[2] && metaspi[3]) ? spi_serpar_reg[7:0] : bitclockdivider_clockphase;

// register address 0x0e

bitclockdivider_dataphase <= ((serialaddress == 8'h0e) && ~metaspi[2] && metaspi[3]) ? spi_serpar_reg[7:0] : bitclockdivider_dataphase;

// register address 0x0f

bitpulse_width <= ((serialaddress == 8'h0f) && ~metaspi[2] && metaspi[3]) ? spi_serpar_reg[7:0] : bitpulse_width;

// register address 0x10

microseconds_per_sector[15:8] <= ((serialaddress == 8'h10) && ~metaspi[2] && metaspi[3]) ? spi_serpar_reg[7:0] : microseconds_per_sector[15:8];

// register address 0x11

microseconds_per_sector[7:0] <= ((serialaddress == 8'h11) && ~metaspi[2] && metaspi[3]) ? spi_serpar_reg[7:0] : microseconds_per_sector[7:0];

// register address 0x12

//servo_pw[7:0] <= ((serialaddress == 8'h12) && ~metaspi[2] && metaspi[3]) ? spi_serpar_reg[7:0] : servo_pw[7:0];

// register address 0x20

interface_test_mode <= ((serialaddress == 8'h20) && ~metaspi[2] && metaspi[3]) ? (spi_serpar_reg[7:0] == 8'h55) : interface_test_mode;

// register address 0x88

dram_read_enbl_spi <= (serialaddress == 8'h88) & ~metaspi[2] & metaspi[3] & dramread_lowhigh;

// dram_readdata[15:0] always has the data ready that was read at the dram_address.

// The read function is triggered after the odd byte is read.

// The next word is requested after reading the high byte when the SPI address is 8'h88.

// toggle respective lowhigh bits on a write or read, clear both bits on address load, otherwise lowhigh bits remain the same

dramwrite_lowhigh <= ((serialaddress == 8'h06) && ~metaspi[2] && metaspi[3]) ? ~dramwrite_lowhigh :

(((serialaddress == 8'h05) && ~metaspi[2] && metaspi[3]) ? 1'b0 : dramwrite_lowhigh);

dramread_lowhigh <= ((serialaddress == 8'h88) && ~metaspi[2] && metaspi[3]) ? ~dramread_lowhigh :

(((serialaddress == 8'h05) && ~metaspi[2] && metaspi[3]) ? 1'b0 : dramread_lowhigh);

end

end // End of Block HSCLOCKFUNCTIONS

endmodule // End of Module spi_interface

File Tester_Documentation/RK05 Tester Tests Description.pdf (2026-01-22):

20-July-2025 | RK05 Tester Tests Descripon v12.docx | page 1

### RK05 Tester, Tests Descripon

Overview
- Drive Addressing commands allow tesng of the drive select signals and sets the drive address used to communicate with the drive under test.
- Seek tests allow tesng of drive seek funcons and verificaon of signals for: cylinder address, restore, strobe, and acknowledge signals that result from strobing a new cylinder address.
- Read & Write tests provide the ability to verify reading and wring between tester and drive under test. Some commands are useful for scope loop tests.
- Read & Write disk images tests provide ability to transfer data between drive under test and the tester DRAM. There are also commands to transfer between tester DRAM and the microSD card.
- Miscellaneous commands:
o Read back drive status
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

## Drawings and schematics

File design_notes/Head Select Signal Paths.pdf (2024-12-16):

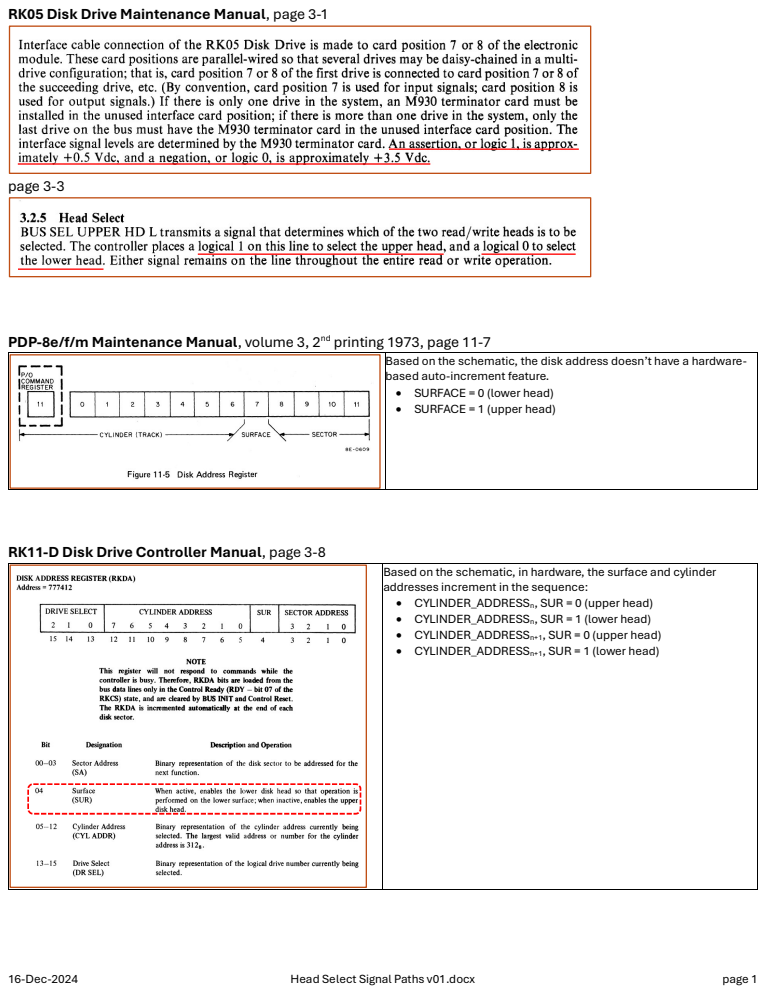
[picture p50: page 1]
16-Dec-2024; Head Select Signal Paths v01.docx; page 1; page 3-3

RK05 Disk Drive Maintenance Manual, page 3-1

PDP-8e/f/m Maintenance Manual, volume 3, 2nd printing 1973, page 11-7

Based on the schematic, the disk address doesn’t have a hardware-
based auto-increment feature.
SURFACE = 0 (lower head)
SURFACE = 1 (upper head)

RK11-D Disk Drive Controller Manual, page 3-8

Based on the schematic, in hardware, the surface and cylinder
addresses increment in the sequence:
CYLINDER_ADDRESSn, SUR = 0 (upper head)
CYLINDER_ADDRESSn, SUR = 1 (lower head)
CYLINDER_ADDRESSn+1, SUR = 0 (upper head)
CYLINDER_ADDRESSn+1, SUR = 1 (lower head)

## RK8-E Head Select Path:

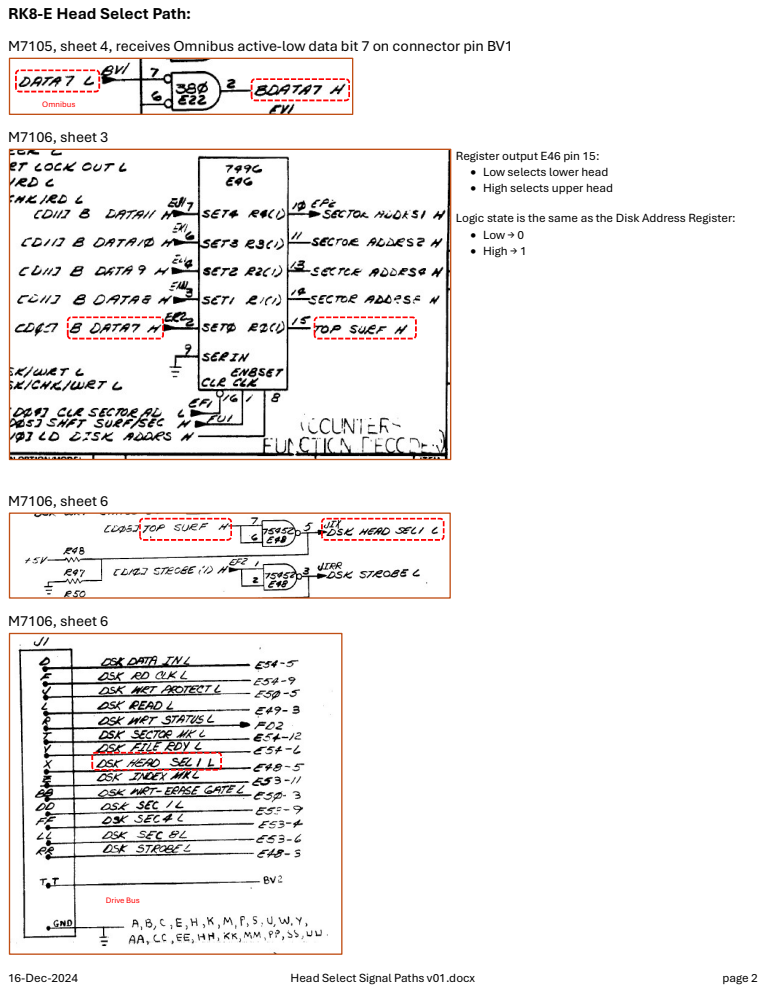
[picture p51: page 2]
16-Dec-2024; Head Select Signal Paths v01.docx; page 2; M7106, sheet 3; M7106, sheet 6; Drive Bus; Omnibus

M7105, sheet 4, receives Omnibus active-low data bit 7 on connector pin BV1

Register output E46 pin 15:
Low selects lower head
High selects upper head

Logic state is the same as the Disk Address Register:
Low → 0
High → 1

## RK11-D Head Select Path: (backplane C, D, E, F is plug-in board A, B, C, D)

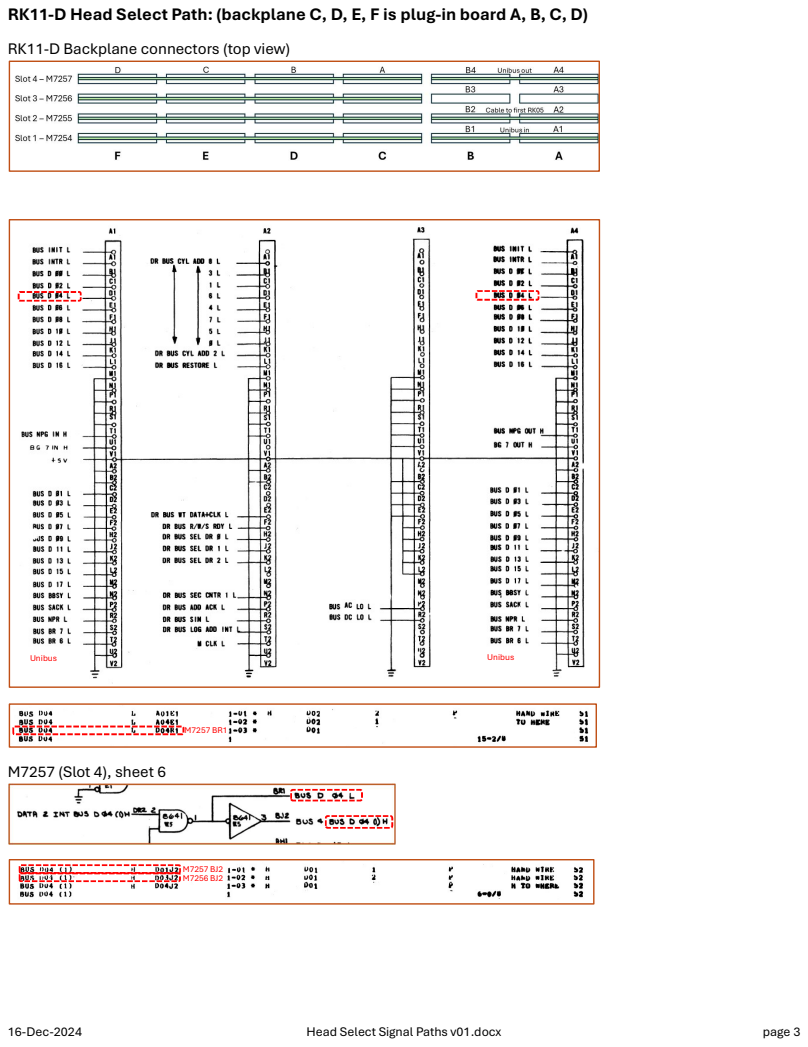
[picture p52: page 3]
16-Dec-2024; Head Select Signal Paths v01.docx; page 3; M7257 (Slot 4), sheet 6; Unibus

RK11-D Backplane connectors (top view)

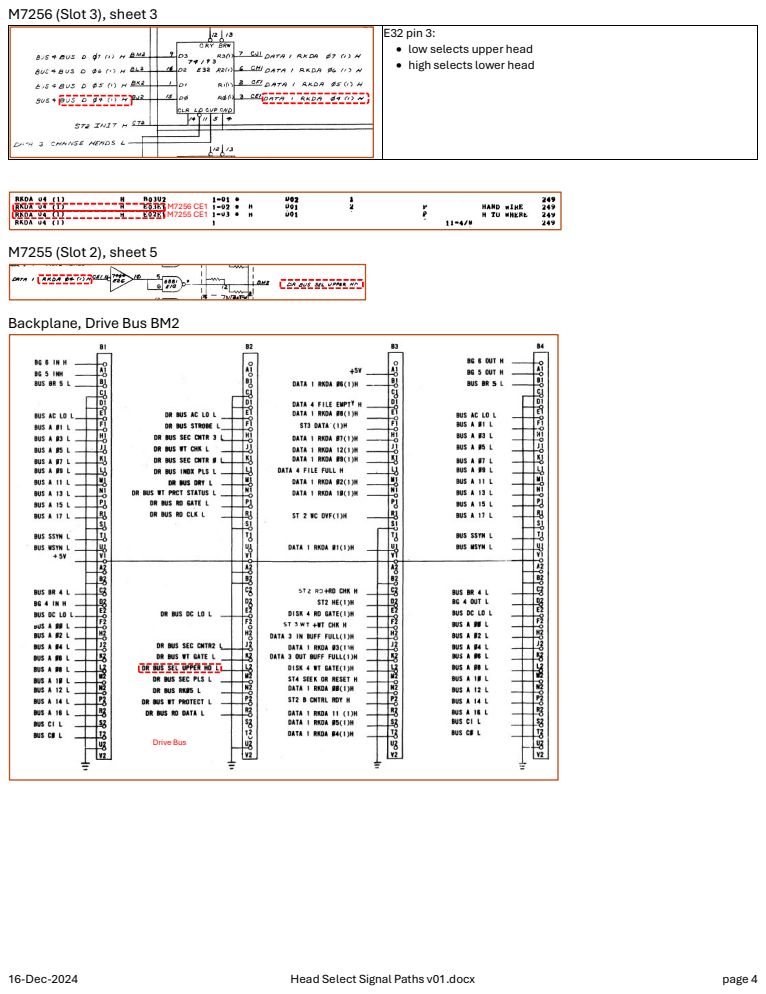
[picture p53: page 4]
16-Dec-2024; Head Select Signal Paths v01.docx; page 4; M7256 (Slot 3), sheet 3; M7255 (Slot 2), sheet 5; Drive Bus

E32 pin 3:
low selects upper head
high selects lower head

Backplane, Drive Bus BM2

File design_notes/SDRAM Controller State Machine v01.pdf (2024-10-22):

reset | SDRAM Controller State Machine
| Memory Data Addressing

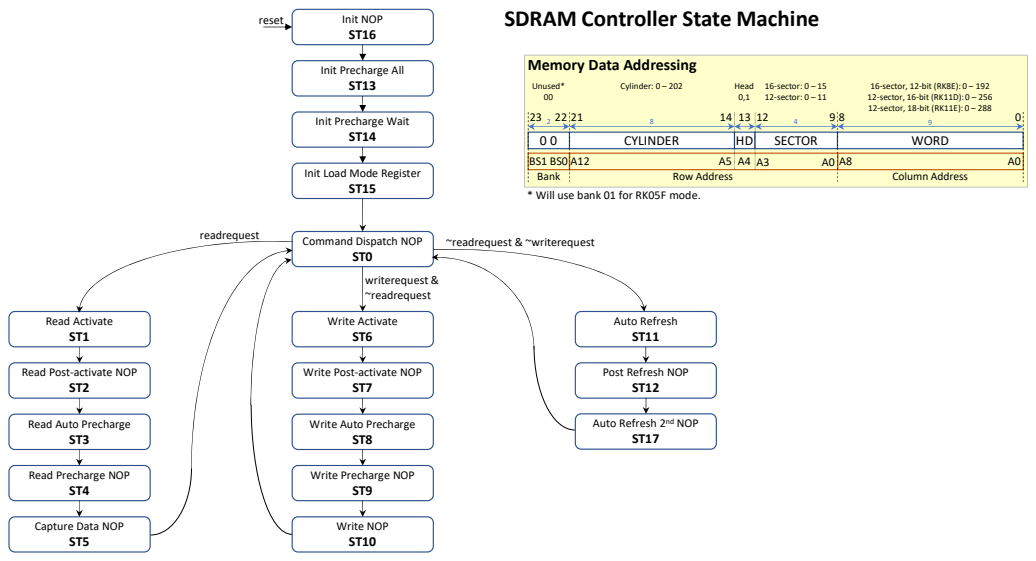
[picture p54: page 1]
Read Activate ST1; Write Activate ST6; Write NOP ST10; Auto Refresh ST11; Command Dispatch NOP ST0; Init NOP ST16; readrequest; writerequest & ~readrequest; ~readrequest & ~writerequest; CYLINDER; SECTOR; WORD; Bank; Row Address; Column Address; Unused* 00; Cylinder: 0 – 202; Head; 16-sector: 0 – 15 12-sector: 0 – 11; 16-sector, 12-bit (RK8E): 0 – 192 12-sector, 16-bit (RK11D): 0 – 256 12-sector, 18-bit (RK11E): 0 – 288

Init Precharge All

Init Precharge Wait

Init Load Mode Register

* Will use bank 01 for RK05F mode.

Read Post-activate NOP

Write Post-activate NOP

Post Refresh NOP

Auto Refresh 2nd NOP

Read Auto Precharge

Write Auto Precharge

Read Precharge NOP

Write Precharge NOP

Capture Data NOP

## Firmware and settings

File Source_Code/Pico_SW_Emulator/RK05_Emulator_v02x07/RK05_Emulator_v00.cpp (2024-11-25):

// *********************************************************************************
// RK05_Emulator_v0.cpp
//   Top Level main() function of the RK05 disk emulator
// *********************************************************************************
//
//===============================================================================================//
//                                                                                               //
// This software and related modules included by the top level module and files used to build    //
// the software are provided on an as-is basis. No warrantees or guarantees are provided or      //
// implied. Users of the RK05 Emulator or RK05 Tester shall not hold the developers of this      //
// software, firmware, hardware, or related documentation liable for any damages caused by       //
// any type of malfunction of the product including malfunctions caused by defects in the design //
// or operation of the software, firmware, hardware or use of related documentation or any       //
// combination thereof.                                                                          //
//                                                                                               //
//===============================================================================================//
//
#define SOFTWARE_MINOR_VERSION 7
#define SOFTWARE_VERSION 2

#include <stdio.h>
#include "pico/stdlib.h"
#include "hardware/gpio.h"
#include "hardware/sync.h"
//#include "hardware/adc.h"
//#include "sd_card.h"
//#include "ff.h"

//#include "include_libs/stdlib.h"
//#include "include_libs/adc.h"
//#include "include_libs/sd_card.h"
//#include "include_libs/ff.h"

//#include <stdio.h>
#include <string.h>
//#include "pico/stdlib.h"
//#include "hardware/uart.h"
//#include "pico/binary_info.h"
//#include "hardware/spi.h"

//#include "emulator_hardware.h"
//#include "emulator_state.h"
//#include "display_big_images.h"
#include "disk_state_definitions.h"
#include "display_functions.h"
//#include "microsd_file_ops.h"

#include "emulator_state_definitions.h"
#include "emulator_state.h"
#include "emulator_hardware.h"
#include "display_functions.h"
#include "display_timers.h"
#include "emulator_command.h"

// GLOBAL VARIABLES
struct Disk_State edisk;

#define INPUT_LINE_LENGTH 200
char inputdata[INPUT_LINE_LENGTH];
char *extract_argv[INPUT_LINE_LENGTH];
int extract_argc;

// callback code
int char_from_callback;

int debug_mode;

// Function Prototype
//void update_drive_address(Disk_State* ddisk);


// console input callback code
void callback(void *ptr){
    int *i = (int*) ptr;  // cast void pointer back to int pointer
    // read the character which caused to callback (and in the future read the whole string)
    *i = getchar_timeout_us(100); // length of timeout does not affect results
}

void gpio_callback(uint gpio, uint32_t events) {
    int readval = read_int_inputs();
    int operation_id = (readval >> 10) & 0x3;
    if((gpio == 4) && ((events & 0x8) == 0x8)){
        switch(operation_id){
            case 0:
                if((readval & 0x400000) == 0)
                    printf("*SEEK RESTORE\r\n");
                else
                    printf("*SEEK %d\r\n", readval & 0xff);
                break;
            case 1:
                printf("*READ c=%d h=%d s=%d\r\n", readval & 0xff, (readval >> 8) & 1, (readval >> 12) & 0xf);
                break;
            case 2:
                printf("*WRITE c=%d h=%d s=%d\r\n", readval & 0xff, (readval >> 8) & 1, (readval >> 12) & 0xf);
                break;
            default:
                printf("*ERROR, operation_id=%d\r\n", operation_id);
                break;
        }
    }
}

void read_switches_and_set_drive_address(){
    int switch_read_value = read_drive_address_switches();
    edisk.Drive_Address = switch_read_value & DRIVE_ADDRESS_BITS_I2C;
    edisk.mode_RK05f = ((switch_read_value & DRIVE_FIXED_MODE_BIT_I2C) == 0) ? false : true;
    load_drive_address(edisk.Drive_Address);
}

void initialize_states(){
    edisk.Drive_Address = 0;
    edisk.mode_RK05f = false;
    edisk.File_Ready = false;
    edisk.Fault_Latch = false;
    edisk.dc_low = false;
    edisk.FPGA_version = 0;
    edisk.FPGA_minorversion = 0;
    edisk.Board_version = read_board_version();

    edisk.run_load_state = RLST0;
    edisk.rl_switch = false;
    edisk.p_wp_switch = edisk.wp_switch = false;

    edisk.door_is_open = true;
    edisk.door_count = 0;

    //display_disable_message_timer();
    //display_restart_invert_timer();

    // initialize parameters to PDP-8 RK8-E values
    strcpy(edisk.controller, "RK8-E");
    edisk.bitRate = 1440000;
    //edisk.preamble1Length = 120;
    //edisk.preamble2Length = 82;
    //edisk.dataLength = 3104;
    //edisk.postambleLength = 36;
    edisk.numberOfCylinders = 203;
    edisk.numberOfSectorsPerTrack = 16;
    edisk.numberOfHeads = 2;
    edisk.microsecondsPerSector = 2500;
}

#define UART_ID uart0
//#define BAUD_RATE 115200
#define BAUD_RATE 460800
#define UART_TX_PIN 0
#define UART_RX_PIN 1

void initialize_system() {
    debug_mode = 0;
    stdio_init_all();
    sleep_ms(50);
    //initialize_uart();
    // Set up our UART with the required speed.
    uart_init(UART_ID, BAUD_RATE);
    sleep_ms(500);

    // Set the TX and RX pins by using the function select on the GPIO
    // Set datasheet for more information on function select
    // We are using GP0 and GP1 for the UART, package pins 1 & 2
    gpio_set_function(UART_TX_PIN, GPIO_FUNC_UART);
    gpio_set_function(UART_RX_PIN, GPIO_FUNC_UART);
    sleep_ms(50);

    // callback code
    char_from_callback = 0;
    uint32_t old_irq_status = save_and_disable_interrupts();
    stdio_set_chars_available_callback(callback, (void*)  &char_from_callback); //register callback
    restore_interrupts(old_irq_status);

    //printf("************* UART is initialized *****************\r\n");

    // Wait for user to press 'enter' to continue
    //char buf[100];
    //printf("\r\nPress 'enter' to start.\r\n");
    //while (true) {
        //buf[0] = getchar();
        //if ((buf[0] == '\r') || (buf[0] == '\n')) {
            //break;
        //}
    //}

    printf("\r\n************* RK05 Emulator STARTUP *************\n");
    initialize_gpio();
    setup_display();
    printf(" *gpio initialized\n");
    assert_fpga_reset();
    sleep_ms(10);
    deassert_fpga_reset();
    initialize_spi();
    printf(" *spi initialized\r\n");
    initialize_states();
    printf(" *software internal states initialized\n");
    initialize_fpga(&edisk);
    printf(" *fpga registers initialized\n");

    printf(" *Emulator software version %d.%d\r\n", SOFTWARE_VERSION, SOFTWARE_MINOR_VERSION);
    printf(" *FPGA version %d.%d\r\n", edisk.FPGA_version, edisk.FPGA_minorversion);
    printf(" *Board version %d\r\n", edisk.Board_version);

    // At boot time: if the RUN/LOAD switch is in the LOAD position then open the door
    read_rocker_switches(&edisk);
    //if(edisk.rl_switch == 0)
      //boot_open_the_door();
    // else if the switch is in the RUN position then the RUN/LOAD state machine will "automatically" close the door and load the DRAM
    clear_dc_low();
}

int main() {
    uint32_t ticker;
    initialize_system();
    read_switches_and_set_drive_address();

    ticker = 0;
    int reg00_val;
    //stdio_init_all();
    // set the baud rate of stdio here
    printf("RK05 Emulator STARTING\n");
    display_splash_screen();
    if(is_it_a_tester()) // check the hardware ID bit in the FPGA to confirm that it's loaded with emulator FPGA code
        printf("  ######## ERROR, hardware is a tester, should be emulator hardware ########\r\n");

    if(is_testmode_selected()){
        sleep_ms(1000); // wait a second before turning off the display
        display_shutdown(); // turn off the display during Interface Test Mode
        close_drive_door(); // make the servo motor relax
	    sleep_ms(100);
        drive_door_status();
        enable_interface_test_mode(); // enable interface test mode in the FPGA
        while(true){
            emulator_command_mode(&edisk);
        }
    }
    else{
        while (true) {
            if((ticker % 50) == 0){
                reg00_val = read_reg00();
                printf("main loop %d, Drive_Address = %d, RLST%x, vsense = %d, reg00 = %x\r\n", ticker, edisk.Drive_Address, edisk.run_load_state, 
                edisk.debug_vsense, reg00_val);
            }
            //if((ticker % 10) == 0) // for debugging the display_state functions
                //print_display_state();
            read_rocker_switches(&edisk);
            // if the WTPROT button is pressed then toggle the WP status in the FPGA, also toggles the indicator
            if(edisk.wp_switch && !edisk.p_wp_switch){
                toggle_wp();
                printf("toggle WTPROT\r\n");
            }

            check_dc_low(&edisk);
            //clear_dc_low();

            process_run_load_state(&edisk);
            if((edisk.run_load_state == RLST0) || (edisk.run_load_state == RLST19) || (edisk.run_load_state == RLST1d)){
                int previous_drive_address = edisk.Drive_Address;
                bool previous_mode_RK05f = edisk.mode_RK05f;
                read_switches_and_set_drive_address();
                //int switch_read_value = read_drive_address_switches();
                //edisk.Drive_Address = switch_read_value & DRIVE_ADDRESS_BITS_I2C;
                //edisk.mode_RK05f = ((switch_read_value & DRIVE_FIXED_MODE_BIT_I2C) == 0) ? false : true;
                //load_drive_address(edisk.Drive_Address);
                if((previous_drive_address != edisk.Drive_Address) || (previous_mode_RK05f != edisk.mode_RK05f)){
                    printf("Drive_Address changed to %d.\r\n", edisk.Drive_Address);
                    display_disable_message_timer();
                    display_restart_invert_timer();
                    display_drive_address(edisk.Drive_Address, edisk.mode_RK05f, edisk.File_Ready ? edisk.imageName : (char *)"");
                }
            }
            manage_display_timers(&edisk);
            if(char_from_callback != 0){
                // if the key was L or l then begin logging events
                if((char_from_callback == 'L') || (char_from_callback == 'l')){
                    printf("  Begin logging events\r\n");
                    gpio_set_irq_enabled_with_callback(4, GPIO_IRQ_EDGE_RISE, true, &gpio_callback); // gpio callback
                }
                else if((char_from_callback == 'S') || (char_from_callback == 's')){
                    printf("  Stop logging events\r\n");
                    gpio_set_irq_enabled_with_callback(4, GPIO_IRQ_EDGE_RISE, false, &gpio_callback); // gpio callback
                }
                char_from_callback = 0; //reset the value
            }

            sleep_ms(100);
            ticker++;
        }
    }
    return 0;
}

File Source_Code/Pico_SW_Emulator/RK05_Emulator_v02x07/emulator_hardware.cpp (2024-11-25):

// *********************************************************************************
// emulator_hardware.cpp
//  definitions and functions related to the emulator hardware
//  both GPIO and FPGA
// *********************************************************************************
// 
#include <stdio.h>
#include <string.h>
#include "pico/stdlib.h"

#include "hardware/uart.h"
#include "pico/binary_info.h"
#include "hardware/spi.h"

#include "disk_state_definitions.h"
#include "display_functions.h"
#include "emulator_state_definitions.h"

#include "hardware/gpio.h"
#include "hardware/pwm.h"
#include "hardware/adc.h"
#include "time.h"

#define UART_ID uart0
#define BAUD_RATE 115200

// MOTORMIN and MOTORMAX are virtual PWM values that range from 0 to 20. With a 100 msec update it takes 2 seconds to open or close the door.
// The actual PWM values that get written to the hardware are mapped to hardware-specific values based on the state of servodutyfactor.
#define MOTORMIN 0  // was 4 for GPIO PWM, original was 3, sets the bottom of the inner arm, this is the Door Open position
#define MOTORMAX 20 // was 7 for GPIO PWM, original was 13, sets the top of the inner arm, this is the Door Closed position
#define MOTORDELTA 1
//#define SERVOPULSEGPIO 10

//#define PICO_DEFAULT_SPI_CSN_PIN 1 // commented out because compiler said it was re-defined

// GPIO PIN DEFINITIONS
#define GPIO_ON 1
#define GPIO_OFF 0
#define UART_TX_PIN 0
#define UART_RX_PIN 1
#define DC_LOW_CPU_N 2
//#define SPARE_GP2 2
#define FPGA_HW_RESET_N 3
// CMD_INTERRUPT is GPIO4
#define SPARE_FP_GP22 22
#define SPARE_SPIRegSelect1 5
#define TESTMODE_SELECT 6
#define FP_CPU_RDY_ind 7
#define FP_CPU_FAULT_ind 8
#define FP_CPU_LOAD_ind 9
#define SP_SDLED_N 10
#define microSD_CD 11
#define microSD_MISO 12
#define microSD_CS 13
#define microSD_SCLK 14
#define microSD_MOSI 15
#define FPGA_SPI_MISO 16
#define FPGA_SPI_CS_n 17
#define FPGA_SPI_CLK 18
#define FPGA_SPI_MOSI  19
#define FP_switch_RUN_LOAD 20
#define FP_switch_WT_PROT 21
#define BOARD_VERSION_0 22
#define LED_PIN 25
#define ADC2 28

//FPGA VERSIONS
#define FPGA_MIN_VERSION 0
#define FPGA_MAX_VERSION 255

//FPGA CPU REGISTERS, WRITE
#define SPI_CONTROL_0 0
#define SPI_COMMAND_4 4
#define SPI_DRAM_ADDR_5 5
#define SPI_DRAM_DATA_6 6
#define SPI_TEST_REG1_7 7
#define SPI_TEST_REG2_8 8
#define SPI_TEST_REG3H_9 9
#define SPI_TEST_REG3L_A 0xa
#define SPI_POSTAMBLE_B 0xb
#define SPI_SECTPERTRK_C 0xc
#define SPI_BITCLKDIV_CP_D 0xd
#define SPI_BITCLKDIV_DP_E 0xe
#define SPI_BITPLSWIDTH_F 0xf
#define SPI_USECPERSECTH_10 0x10
#define SPI_USECPERSECTL_11 0x11
#define SPI_SERVO_PW_12 0x12
#define SPI_INTERFACE_TEST_MODE_20 0x20

//FPGA CPU REGISTERS, READ
#define SPI_STATUS_80 0x80
#define SPI_CYLADDR_81 0x81
#define SPI_DRVSTATUS_82 0x82
#define SPI_DRAMREAD_88 0x88
#define SPI_FUNCT_ID_89 0x89
#define SPI_FPGACODE_VER_90 0x90
#define SPI_FPGACODE_MINORVER_91 0x91
#define SPI_TEST_MODE_GRP1_94 0x94
#define SPI_TEST_MODE_GRP2_95 0x95
#define SPI_TEST_MODE_GRP3_96 0x96
#define SPI_READBACK_00_A0 0xa0
#define SPI_READBACK_00_A7 0xa7
#define SPI_READBACK_00_A8 0xa8
#define SPI_READBACK_00_A9 0xa9
#define SPI_READBACK_00_AA 0xaa
#define SPI_READBACK_00_AB 0xab
#define SPI_READBACK_00_AC 0xac
#define SPI_READBACK_00_AD 0xad
#define SPI_READBACK_00_AE 0xae
#define SPI_READBACK_00_AF 0xaf
#define SPI_READBACK_00_B0 0xb0
#define SPI_READBACK_00_B1 0xb1

#define DRIVE_ADDRESS_BITS 0x7
#define FILE_READY_BIT 0x10
#define FAULT_LATCH_BIT 0x20
#define DC_LOW_BIT 0x80
#define TOGGLE_WP_BIT 0x1

#define TEST_REG_3_LO_BIT_7 0X80

#define dc_lower_threshold 2850 // 3850 // equivalent of ~4.70 V
#define dc_upper_threshold 2940 // 3972 // equivalent of ~4.85 V

// drive door states
#define DOOROPEN 0
#define DOORCLOSED 1
#define DOORMOVING 2

#define DOOR_IS_CLOSING 1
#define DOOR_IS_OPENING 0

#define BUF_LEN 2
//#define PICO_DEFAULT_SPI_CSN_PIN 17

//static int debugdrivedoorstatus;
static int servodutyfactor;
static int servomovedirection;
static uint servo_slice_num;
static uint servo_chan;

static uint8_t dutyfactortable_fpga[21] = {47, 49, 51, 53, 55, 57, 59, 61, 63, 65, 67, 69, 71, 73, 75, 77, 79, 81, 83, 85, 88};

#ifdef PICO_DEFAULT_SPI_CSN_PIN
static inline void cs_select()
{
    asm volatile("nop \n nop \n nop");
    gpio_put(PICO_DEFAULT_SPI_CSN_PIN, 0);  // Active low
    asm volatile("nop \n nop \n nop");
}

static inline void cs_deselect()
{
    asm volatile("nop \n nop \n nop");
    gpio_put(PICO_DEFAULT_SPI_CSN_PIN, 1);
    asm volatile("nop \n nop \n nop");
}
#endif

// *************** FPGA SPI Registers ***************
//
uint8_t read_write_spi_register(uint8_t reg, uint8_t data)
{
    uint8_t out_buf [BUF_LEN], in_buf [BUF_LEN];
    uint8_t buf[2];
    out_buf[0] = reg;
    out_buf[1] = data;
    cs_select();
    spi_write_read_blocking (spi_default, out_buf, in_buf, 2);
    cs_deselect();
    return(in_buf[1]);
}
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

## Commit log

2024-11-05 Add files via upload
    updated to v04, current photos of accessory kits
2024-11-05 Add files via upload
    A software improvement that prevents the system from locking up due to activity on the serial port input during the boot-up process. It’s not required but recommended to install Raspberry Pi software version 2.7 or higher in addition to the rework to add the pullup on the serial port input.
2025-01-26 Add files via upload
    Adding Diablo Adapters and Terminator
    [BOM_RK05-Diablo-Terminator-v1_2025-01-13.csv, Diablo Connector Shell v01.stl, PickAndPlace_PCB_RK05-Diablo-Terminator-v1_2025-01-13.csv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]
